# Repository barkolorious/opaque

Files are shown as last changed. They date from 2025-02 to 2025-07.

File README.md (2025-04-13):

# **OPAQUE**: **O**pen-source **P**ortable **A**ir **QU**ality **E**quipment

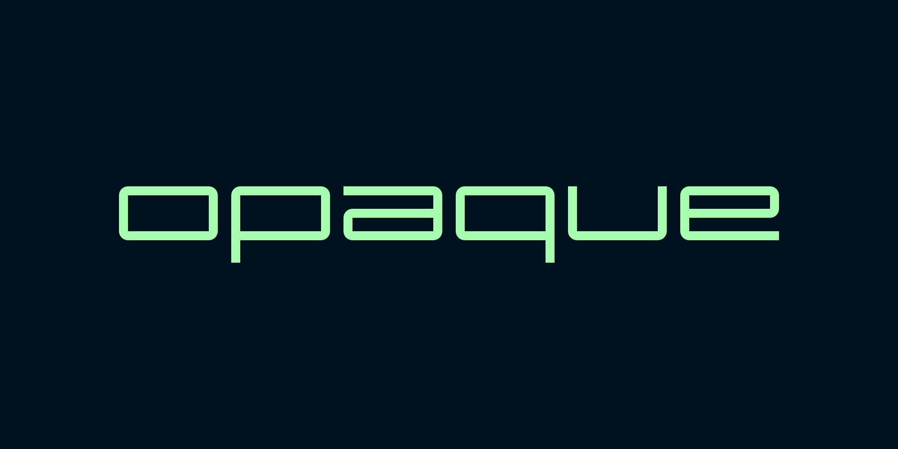
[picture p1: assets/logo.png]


---

A portable device that measures the temperature, humidity, AQI (Air Quality Index), tVOC (total Volatile Organic Components), eCO2, CO, NH3, NOx and O3 amount in the air.

It comes in 2 flavours: OPAQUE Lite and OPAQUE Connect. OPAQUE Lite stores the measurements on device, in contrast to OPAQUE Connect, which stores data both on device and on cloud. OPAQUE Connect can also pull data from cloud.

It's still work in progress.

2204-D Report: https://docs.google.com/document/d/112pA8oVNO5BkxKRDr9aJxBSNs7QlX5zvWhuIxiFPKnI/edit?usp=sharing

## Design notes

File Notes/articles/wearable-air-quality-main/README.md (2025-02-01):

# Wearable Air Quality Monitor
The device is based around the Arduino Nicla Sense ME  and incorporates aditional sensors to collect information on VOCs, CO2, Temperature, Humidity, and particulates. The objective is to provide a relatively low cost open design to monitor pollutants of concern.

----------------------
If installing fresh libraries, make sure to change the following:

In sps30.h file make sure to do the following
Comment out: 
#define INCLUDE_SOFTWARE_SERIAL 1

Change I2C length from 32 to 256>>
  #define I2C_LENGTH 256
  
Receieve buffer length change for non SMALLFOOTPRINT from 128 to 256:
#else
#define MAXRECVBUFLENGTH 256

Also install the ArduinoBLE library for the Arduino_BHY2.
----------------------



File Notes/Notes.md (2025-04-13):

- [x] terahertz diode co2
- [x] ege üni özlem hoca
- [x] cuma öğleden sonra 14:00

- [x] ege üni özkur hoca
- [x] ultraviyole sensör
- [ ] verilerin birbirlerini etkilemesi

- https://www.hammaddeler.com/urun/kaucuk-buyuk-tipa

- [x] basınç gerekli mi 
- [x] no2 so2 gerekli mi - özlem hocaya sor
- [x] 15k tl -> özlem hocaya sor
- [x] 3 tane
- [x] genel araştırma projesi

- [ ] sps30 karşılaştırma testi
- [ ] hastalar işe gitsin trafiğe çıksın
- [X] en şart ölçümleri soru ve sıklığı sor
- [X] butonu sor
- [x] 3 x 5 gün
- [x] ivme ölçer 
- [x] diğeri kadar büyük olabilir

- [ ] sunumları alabilir miyiz
- [ ] basınç gerekli mi
- [ ] no2 so2 gerekli mi
- [ ] genel araştırma projesi nasıl çalışıyor, gap olmadan bize yardım edebilir mi

**Hastalara verme sebebi**
- gerçekten işe yarıyor mu, 
- veri toplama ve analizi (bölgesel), 
- Doktora destek çünkü SD kart veri topluyor ve doktora verebilirsin.

**OPAQUE**: **O**pen-source **P**ortable **A**ir **QU**ality **E**quipment
![[assets/logo.png]]

## EgeSAM
- https://polenalerji.ege.edu.tr
- goksel.ozlem@gmail.com
- pelin.metiner@gmail.com
- [EgeSAM 101. Yıl Sempozyumu](EgeSAM%20101.%20Yıl%20Sempozyumu.md)

## Articles
- [BACA GAZI ÖRNEKLEMESİNDE BTEX VOC GRUPLARININ ÖLÇÜM BELİRSİZLİĞİNİN HESAPLANMASI](https://avesis.omu.edu.tr/yayin/6a808b43-7e9a-41d2-a6cd-b386e392ce22/baca-gazi-orneklemesinde-btex-voc-gruplarinin-olcum-belirsizliginin-hesaplanmasi)
- [What is BTEX?](https://www.aeroqual.com/blog/what-is-btex)
- [Akıllı Şehir Hava Takip Sistemi ve Astım Hastaları İçin PM2.5 Konsantrasyonu Ölçüm Aracının Geliştirilmesi](articles/akillihava.pdf)
- [Comprehensive analysis of resilience of human airway epithelial barrier against short-term PM2.5 inorganic dust exposure using in vitro microfluidic chip and ex vivo human airway models](allergy2024goksel.pdf)
- [HYPER-LOCAL AIR ZONE EVALUATOR (HAZE): AN OPEN SOURCE SYSTEM FOR PERSONAL ENVIRONMENTAL EXPOSURE MONITORING](v001t04a003-dmd2023-5665.pdf)

## Benzer Projeler
- https://atmotube.com/atmotube-pro
- Oğuz Hoca'nın Projesi
	- https://github.com/AMA-Labs/droneiotserver
	- https://asmedigitalcollection.asme.org/BIOMED/proceedings/DMD2023/86731/V001T04A003/1163853
- https://www.hepsiburada.com/sunshinee-13-u-1-arada-tuya-wifi-hava-kalitesi-monitoru-co2-tvoc-hcho-pm2-5-pm1-0-pm10-sicaklik-nem-saat-tarih-alarm-zamanlayici-siyah-yu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
- https://www.google.com.tr/shopping/product/1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,of:1,eto:141815484925603285_0,prmr:1,pid:141815484925603285,cs:1&sa=X&ved=0ahUKEwiIlb6ItvyKAxUZ6wIHHQQRC94QgjYI_wg 
- https://www.google.com.tr/url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
- https://www.reddit.com/r/esp32/s/lKiWNX6Ak0

## Probable Components
- ESC32 SIM800L
	- https://www.hiber.com.tr/esp32-sim800l-gsm-module-imei-kayitli-uretim-fazlasi
	- https://www.youtube.com/watch?v=aCeVsySh-v4
	- https://www.motorobit.com/esp32-sim800l-gsm-module-gelistirme-karti-ttgo-t
	- https://randomnerdtutorials.com/esp32-sim800l-publish-data-to-cloud/
	- https://www.hepsiburada.com/ttgo-t-call-v1-4-esp32-sim800l-gsm-modulu-gelistirme-karti-ve-sim-anten-lehimsiz-pm-HBC000071WQ8U
	- https://www.elektrodepo.com/urun/ttgo-t-call-v1-4-esp32-sim800l-gsm-modulu-gelistirme-karti-sim-anten-lehimsiz
	- https://www.amazon.com.tr/T-Call-SIM800L-Modülü-Geliştirme-Lehimsiz/dp/B0DJJYS7H8/ref=sr_1_1?adgrpid=149290891115&dib=eyJ2IjoiMSJ9.EgimDA37MKVbJFewe0D3VPdO1C6fNslO2Pl-HL35DVgIxA5WuMHFbvYWD4978R3_z2cK8L_joyDAhRv9Xe0morgsaPVF940nGoh1fdj12P2CRbK1QtMohecb0POAcMw8DVhDOnuiY08fk4ExVHoFzI31nRxyBsWJJ-KK28ia0VTu7qdZAMSPXiS5wjYPGHoBxLNg6GleS1d_2DnD4zWxIggH06StPBn1YcHMs6USU_KjMwu6Vwsy81Dq_cBEVPWbYKxBVEC2vj8UKeA4ZLVePiUncPJECCjdZJ-8quTdRKU.aERDkYUaHCwcZKKPt1ZaMCcbHvms9AoYU4QdMM2_wCA&dib_tag=se&hvadid=678425501699&hvdev=c&hvlocphy=1012783&hvnetw=g&hvqmt=e&hvrand=2204728206467899657&hvtargid=kwd-842690300862&hydadcr=5565_2410569&keywords=esp32+sim800l&qid=1729361943&sr=8-1
- PMS7003
	- [Datasheet](datasheets/PMS7003_PMsensor.pdf)
- SPS30
	- [Datasheet](datasheets/SPS30.pdf)
- SCD4x: CO2 - Sıcaklık - Nem
	- https://robiz.net/scd41
	- https://sensirion.com/media/documents/48C4B7FB/66E05452/CD_DS_SCD4x_Datasheet_D1.pdf
	- https://tr.aliexpress.com/i/1005003974569988.html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
- MQ-7: CO
- ENS160: CO2 - tVOC
	- [Datasheet](datasheets/ENS160.pdf)
	- [Library](https://github.com/sciosense/ENS160_driver)
- AHT20 + BMP280: Nem - Sıcaklık - Basınç
	- https://www.hiber.com.tr/aht20-bmp280-yuksek-hassasiyetli-atmosferik-basinc-sicaklik-nem
- NEO-8M: GPS
- SGP40: VOC - Toluen
	- https://www.amazon.com.tr/Bileşikler-Cihazları-Monitörleri-Oluşturmak-Destekler/dp/B09D43WDVK
	- https://sensirion.com/media/documents/296373BB/6203C5DF/Sensirion_Gas_Sensors_Datasheet_SGP40.pdf 
- DS1307: RTC
	- https://www.direnc.net/rtc-modul-ds1307
- MP801: C6H6 - C7H8 - CH2O - C2H5OH - smoke
	- https://www.winsen-sensor.com/product/mp801.html?searchid=4719
- MP503: C2H5OH - smoke - iso-butane - CH2O
	- https://www.winsen-sensor.com/product/mp503.html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
- ENS160 + AHT21: CO2 - tVOC - Sıcaklık - Nem
	- https://tr.aliexpress.com/item/1005004052950350.html?src=google
- Batarya
	- https://www.turktablet.net/urun/venatus-va33hd-batarya-pil-5000mah
	- https://www.turktablet.net
- Arduino Nicla Sense Me
	- https://market.samm.com/arduino-nicla-sense-me
- MQ-131: O3
- ZE25-O3: O3
	- https://www.roboshop.com.tr/ze25-o3-ozon-sensoru-o3-gaz-sensoru-modulu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
- MICS-6814: CO, NO2, NH3
	- https://www.robotistan.com/mics-6814-hava-kalitesi-co-no2-nh3-azot-karbon-gaz-sensoru-modulu
	- https://www.sgxsensortech.com/content/uploads/2015/02/1143_Datasheet-MiCS-6814-rev-8.pdf
- ADS1115:
	- ![[assets/Pasted image 20241123235145.png]]
	- https://how2electronics.com/how-to-use-ads1115-16-bit-adc-module-with-esp32/
	- https://arduino.stackexchange.com/questions/53899/ads1115-measuring-5v-voltages-and-powering-with-3-3v
- ESC32-DevKitC-V4
	- https://dl.espressif.com/dl/schematics/esp32_devkitc_v4-sch.pdf
https://randomnerdtutorials.com/esp32-web-bluetooth/
## Current Components

### Lite
- ESP32-DevKitC-V4
- RTC - DS3231
- OLED Screen - SSD1306
- Gyro - MPU6050
- µSD Card
- GPS - NEO-6M
- Temperature, Humidity Measurement - ENS210
- AQI, tVOC, eCO2 Measurement - ENS160
- CO, NH3, NOx Measurement - MiCS6814
- O3 Measurement - MQ-131
- PM1, PM2.5, PM10 - PMS7003

### Connect
- ESP32-DevKitC-V4
- RTC - DS3231
- Touch Screen - Nextion NX4827P043
- Gyro - MPU6050
- µSD Card
- Mobile Data - SIM800C
- GPS - NEO-6M
- Temperature, Humidity Measurement - ENS210
- AQI, tVOC, eCO2 Measurement - ENS160
- CO, NH3, NOx Measurement - MiCS6814
- O3 Measurement - MQ-131
- PM1, PM2.5, PM10 - PMS7003

---

![[assets/Pasted image 20241114225116.png]]
![[assets/Pasted image 20241116133241.png]]

- ESP32 + SSD1306: 
	- https://lastminuteengineers.com/oled-display-esp32-tutorial/
- ESP32 + SD Card ( + [Data logging](https://randomnerdtutorials.com/esp32-microsd-card-arduino/#webserversdcard)): 
	- https://www.electronicwings.com/esp32/microsd-card-interfacing-with-esp32
	- https://randomnerdtutorials.com/esp32-microsd-card-arduino/
- ESP32 + SSD1306 + DS3231:
	- https://microcontrollerslab.com/esp32-ds3231-real-time-clock-rtc-oled/
- ESP32 + MPU6050:
	- https://randomnerdtutorials.com/esp32-mpu-6050-accelerometer-gyroscope-arduino/
- ESP32 Analog Input:
	- https://randomnerdtutorials.com/esp32-adc-analog-read-arduino-ide/
- ESP32 + Firebase:
	- https://randomnerdtutorials.com/esp32-firebase-web-app/
- ESP32 + SIM800C:
	- https://community.thinger.io/t/esp32-sim800c/676/3
- ESP32 + SIM800L:
	- https://randomnerdtutorials.com/esp32-cloud-mqtt-broker-sim800l/
	- https://circuitdigest.com/microcontroller-projects/interfacing-sim800l-module-with-esp32
- ESP32 + NEO-6M:
	- https://randomnerdtutorials.com/esp32-neo-6m-gps-module-arduino/
- ESP32 I<sup>2</sup>C Pull-up: 
	- https://electronics.stackexchange.com/questions/602404/esp32-i2c-circuit
	> Most sensors we use in our projects are breakout boards that already have the resistors built-in. So, usually, when you’re dealing with this type of electronics components you don’t need to worry about this.
	> - https://randomnerdtutorials.com/esp32-i2c-communication-arduino-ide/
- PM7003:
	- https://registry.platformio.org/libraries/avaldebe/PMSerial
	- https://github.com/avaldebe/PMserial
	- https://github.com/Ptelka/PMS7003
- MICS6814
	- https://forum.arduino.cc/t/cjmcu-6814-readings-into-ppm/1257495/5
	- https://store.siqma.com/mics-6814-air-quality-sensor-module.html
		- https://www.youtube.com/watch?v=ByzoAjvoX58
			- https://github.com/noorkhokhar99/MICS6814/tree/master
	- https://github.com/Seeed-Studio/Mutichannel_Gas_Sensor
	- maybe you forgot pullup-resistors? Do you use the MiCS-6814 on the purple adapter board CJMCU6814? Then you may add an eg 47k ohm resistor from the analog Input (A1 in your sketch) to Vcc (5V or 3,3 V, depends on your arduino). Then you should get other measurment than the 0-values.  BTW: the sensor needs some time to heat up. And I'm not sure about it's stability over time. I've no experience with it yet.
	- https://kstobbe.dk/2019/02/16/esp32-pms5003-bme280-mics6814-sensor-build/
	- https://forum.arduino.cc/t/cjmcu-6814-adapter-board-with-mics-6814-co-nh3-no2-sensor/595612/14
	- https://forum.arduino.cc/t/mics-6814-cjmcu-6814-gas-sensor-reading-conversion/992844
	- https://forum.arduino.cc/t/mics-6814-integrated-on-a-board-with-esp-wroom-32d-v_rs-reads-2-98-v-of-3-3/699348
	- https://forum.arduino.cc/t/cjmcu-6814-readings-into-ppm/1348009
	- ![[assets/assets/Pasted image 20250128162927.png]]
- MQ-131
	- https://github.com/ostaquet/Arduino-MQ131-driver
	- https://www.graphreader.com/v2
	- https://www.winsen-sensor.com/d/files/manual/mq131-h.pdf

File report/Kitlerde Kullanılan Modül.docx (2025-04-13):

Kitlerde Kullanılan Modül | Kullanıcı Kiti | Hasta Kiti | Açıklama
Mikrodenetleyici Kartı | ESP32-DevKitC-V4 | ESP32-DevKitC-V4 | ESP32-WROOM-32U; 4MB’lık flash hafızaya, 40MHz’lik kristale, 2 çekirdeğe, Bluetooth ve Wi-Fi entegrasyonuna ve harici anten konnektörüne sahiptir. UART, SPI ve I²C haberleşme protokollerini destekleyen kart 3,3V’ta çalışmaktadır.
Ekran | NX4827P043-011R | SSD1306 | NX4827P043; 4,3 inç, dokunmatik (resistif) bir ekrandır. UART ile haberleşmekte ve 5V’ta çalışmaktadır.
Sıcaklık ve Nem Ölçümü | ENS210 | ENS210 | Sensör 3,3V’ta çalışmaktadır. Sıcaklık ölçüm hassasiyeti ±0.15°C, bağıl nem ölçüm hassasiyeti ise ±%2’dir. Sıcaklık ölçüm aralığı -40 ile 100°C arası iken bağıl nem ölçüm aralığı %0 ile %100’dür.
AQI, tUOB, CO2 Ölçümü | ENS160 | ENS160 | Sensör 3,3V’ta çalışmaktadır. tUOB ölçüm aralığı 0-65.000ppb arası iken CO2 ölçüm aralığı 400-65.000ppm’dir. AQI ölçüm aralığı 1-5’tir (UBA, 2007 standardına göre).
CO, NH3, NOx Ölçümü | MICS-6814 | MICS-6814 | Sensör 5V’ta çalışmaktadır. CO ölçüm aralığı 1-1.000ppm, NH3 ölçüm aralığı 1-500ppm ve NOx ölçüm aralığı 0,05-10ppm’dir.
O3 Ölçümü | MQ131 | MQ131 | Sensör 5V’ta çalışmaktadır. O3 ölçüm aralığı 10-1.000ppm’dir.
PM1, PM2.5, PM10 Ölçümü | PMS7003 | PMS7003 | Sensör 5V’ta çalışmaktadır. Ölçüm aralığı 0-1.000μg/m³tür ve %98 doğrulukla sonuç vermektedir.
Gerçek Zamanlı Saat | DS3231 for Pi | NX4827P043-011R modülünün kendi RTC modülü | DS3231 For Pi modülü, I²C ile haberleşmekte ve 3,3V’ta çalışmaktadır.
İvmeölçer | GY-521 | - | GY-521 modülü, MPU6050 entegresini kullanan bir ivmeölçerdir. Modül, I²C ile haberleşmekte ve 3,3V’ta çalışmaktadır.
Mikro SD Kart Adaptörü | Mikro SD Kart Adaptör Modülü | Mikro SD Kart Adaptör Modülü | Modül, SPI ile haberleşmekte ve 3,3V’ta çalışmaktadır.
GPS Modülü | NEO-6M | NEO-6M | Modülün konum hassasiyeti ±2,5m, hız hassasiyeti ±0,1m/s’dir. Modül, UART ile haberleşmekte ve 5V’ta çalışmaktadır.

Kitlerde Kullanılan Modül | Kullanıcı Kiti | Hasta Kiti | Açıklama
ESP32-DevKitC-V4 | X | X | Mikrodenetleyici Kartı 4MB’lık flash hafızaya, 40MHz’lik kristale, 2 çekirdeğe, Bluetooth ve Wi-Fi entegrasyonuna ve harici anten konnektörüne sahiptir. UART, SPI ve I²C haberleşme protokollerini destekleyen kart 3,3V’ta çalışmaktadır.
NX4827P043-011R | X | | Ekran NX4827P043; 4,3 inç, dokunmatik (resistif) bir ekrandır. UART ile haberleşmekte ve 5V’ta çalışmaktadır.
SSD1306 | | X | Ekran SSD1306; 128x64 piksel, siyah-beyaz bir OLED ekrandır. I²C ile haberleşmekte ve 3,3V’ta çalışmaktadır.
ENS210 | X | X | Sıcaklık ve Nem Ölçümü Sensör 3,3V’ta çalışmaktadır. Sıcaklık ölçüm hassasiyeti ±0.15°C, bağıl nem ölçüm hassasiyeti ise ±%2’dir. Sıcaklık ölçüm aralığı -40 ile 100°C arası iken bağıl nem ölçüm aralığı %0 ile %100’dür.
ENS160 | X | X | AQI, tUOB, CO2 Ölçümü Sensör 3,3V’ta çalışmaktadır. tUOB ölçüm aralığı 0-65.000ppb arası iken CO2 ölçüm aralığı 400-65.000ppm’dir. AQI ölçüm aralığı 1-5’tir (UBA, 2007 standardına göre).
MICS-6814 | X | X | CO, NH3, NOx Ölçümü Sensör 5V’ta çalışmaktadır. CO ölçüm aralığı 1-1.000ppm, NH3 ölçüm aralığı 1-500ppm ve NOx ölçüm aralığı 0,05-10ppm’dir.
MQ131 | X | X | O3 Ölçümü Sensör 5V’ta çalışmaktadır. O3 ölçüm aralığı 10-1.000ppm’dir.
PMS7003 | X | X | PM1, PM2.5, PM10 Ölçümü Sensör 5V’ta çalışmaktadır. Ölçüm aralığı 0-1.000μg/m³tür ve %98 doğrulukla sonuç vermektedir.
DS3231 for Pi | | X | Gerçek Zamanlı Saat DS3231 For Pi modülü, I²C ile haberleşmekte ve 3,3V’ta çalışmaktadır. Hassasiyeti ±1dakika/yıl’dır.
GY-521 | | X | İvmeölçer GY-521 modülü, MPU6050 entegresini kullanan bir ivmeölçerdir. Modül, I²C ile haberleşmekte ve 3,3V’ta çalışmaktadır.
Mikro SD Kart Adaptör Modülü | X | X | Mikro SD Kart Adaptörü Modül, SPI ile haberleşmekte ve 3,3V’ta çalışmaktadır.
NEO-6M | X | X | GPS Modülü Modülün konum hassasiyeti ±2,5m, hız hassasiyeti ±0,1m/s’dir. Modül, UART ile haberleşmekte ve 5V’ta çalışmaktadır.

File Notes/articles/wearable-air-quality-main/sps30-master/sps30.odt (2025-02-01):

SPS30 sensor

# 1. Background

This project is part of a number of projects to measure the air quality. I bought a new sensor : SPS30 from Sensirion. Having worked on another sensor from them (SCD30) before the quality is normally good. The aim is to compare the output with other sensors and provide the learning.

The board was relative new, but at the time of writing this version of the documentation a better datasheet is available from supplier. (July 2020)

While there is a driver available from Sensirion it is very modular, to a point where it feel to be over engineered and complex. Also it looked to be half-library as I did not find good user examples for Arduino / ESP32. Hence I wrote the driver from scratch and it supports UART communication (different serial ports) as well as I2C.

A number of examples have been added. Tailored examples for LORA/Feather and SODAQ AFF/SARA-R410M NB-IOT are also available on my github.

In March 2020 an updated datasheet was made available. It contained information about updated SPS30 function and new functions, of which some depend on firmware revisions. The library has been updated with new functions : sleep(), wakeup(), GetVersion() and GetStatusReg(). Also some existing functions have been updated.

In May 2020, based on continued new boards with different pin-outs, as well as boards with multiple I2C channels, the option has been added to select any serial or I2C channel and pass that initialized to the library. Example12 and 13 demonstrate those options.

The library has been validated on many boards now and in June 2020 I got hold of an Arduino Due. It does not seem to support SoftSerial, so for all the friends using a Due, I made changes that you can connected it to I2C, Serial1, Serial2 and Serial3, just like it is for a Mega2560.

Thank you Sensirion !! In June 2020 they have reached out as I have 2 SPS30 ‘only’ on firmware level 1.0 and offered me SPS30 with revision 2.2. I could now test the code and made a number of changes for the new functions : sleep(), wakeup() and GetStatusReg(). I have changed example11 to demonstrate reading the status register only and added example14 to demonstrate the usage of Sleep and wakeup().

August 2020. I obtained connectors for all 3 SPS30 and added Example20 which can run up to 5 SPS30 devices in parallel on a single Arduino Due, 4 devices on Mega2560 or ESP32. See chapter 9 for explanations.

October 2020 : added a Sparkfun LCD to display the results (with optional warning limit)

January 2021 : corrected pin - connection for Due

Paul van Haastrecht

paulvha@hotmail.com

# 2. Hardware connection

Depending on UART or I2C the connections are different. Has been tested by others on many other platforms including SAMx1D.

## 2.0 Select any communication

From the start I had decided to take an embedded communication channel setup. This made it much easier for the user to select and have the right setup for Serial or I2C. It was initially tested on an UNO, MEGA, ESP32, ESP8266 and works well.

Overtime code has been adjusted to support many more boards with different pin-outs based on user request and feedback. The Arduino Due has been added in 1.4.4.

Given the large number of new boards that continue to hit the market, with different pin-outs as well as boards with multiple I2C channels and based on feedback, I have decided to add the option for the user provide the communication channel also differently. This means the user will perform in the sketch the initialization of the channel (serial or I2C) and provide that to the SP30 library. Example12 (for serial communication) and Example13 (for I2C communication) has been added to demonstrate the usage.

The embedded approach as described below, and thus backward compatibility, continues to be available.

## 2.1 UART communication

### 2.1.1 ESP32

Using serial port1, setting the RX-pin(25) and TX-pin(26)

Different setup can be configured in the sketch.

SPS30 pin ESP32

1 VCC -------- VUSB

2 RX --------- TX pin 26

3 TX --------- RX pin 25

4 Select (NOT CONNECTED)

5 GND -------- GND

Also successfully tested on Serial2 (default pins TX:17, RX: 16)

NO level shifter is needed as the SPS30 is TTL 5V and LVTTL 3.3V compatible

### 2.1.2 ATMEGA2560 / Arduino Due

Used SerialPort2. No need to set/change RX or TX pin

SPS30 pin ATMEGA/ Due

1 VCC -------- 5V

2 RX --------- TX2 pin 16

3 TX --------- RX2 pin 17

4 Select (NOT CONNECTED)

5 GND -------- GND

Also successfully tested on SerialPort1 and Serialport3

### 2.1.3 Failed UNO R3

Failed as I had to use softserial as there is not a separate serial port. But as the SPS30

is only working on 115K the connection failed all the time with CRC errors. (see 2.2.3)

### 2.1.4 Failed ESP8266

As the power is only 3V3 (the SPS30 needs 5V) and one has to use softserial which failed with 115K speed

## 2.2 I2C communication

As documented in the datasheet, make sure to use external 10K pull-up resistor on both the SDA and SCL lines. Otherwise the communication with the sensor will fail random. Also read chapter 4 about the expected valid values in I2C.

Although the SPS30 (according to the datasheet) can handle 100K/s, based on feedback from a user he could only the SPS30 to work for longer time stable at 50K. Example13 and example16 allow you to set the speed to 50K. (added version 1.4.10)

### 2.2.1 ESP32

SPS30 pin ESP32

1 VCC -------- VUSB

2 SDA -------- SDA (pin 21)

3 SCL -------- SCL (pin 22)

4 Select ------ GND (select I2c)

5 GND ------- GND

The pull-up resistors should be to 3V3.

Just be aware the ESP32 also has WIRE1, without default pins. You can set pins however e.g.

Wire1.begin(23,18,100000); // SDA pin 23, SCL pin 18, 100kHz frequency // Wire1 on ESP32

You still need pull-up resistors to 3V3

### 2.2.2 ATMEGA2560 / Arduino Due

SPS30 pin ATMEGA

1 VCC -------- 5V

2 SDA -------- SDA

3 SCL --------- SCL

4 Select ------- GND (select I2c)

5 GND -------- GND

On a Due Wire already has pull-up resistors. You can also use Wire1 on a Due. Then connect to SDA1 and SCL1 next to AREF. Here you need to add external pull-up resistors as you have to do on an MEGA2560.

### 2.2.3 UNO R3

SPS30 pin UNO

1 VCC ------- 5V

2 SDA ------- A4

3 SCL -------- A5

4 Select ------ GND (select I2c)

5 GND ------- GND

When UNO-board is detected the UART code is excluded as that does not work on UNO and will save memory. Also some buffers reduced and the call to GetErrDescription() is removed to allow enough memory. Apart from that ALL examples work with UNO as well :-)

### 2.2.4 ESP8266

SPS30 pin External ESP8266

1 VCC -------- 5V

2 SDA ----------------------- SDA

3 SCL ------------------------ SCL

4 Select ---------------------- GND (select I2c)

5 GND ------- GND -------- GND

The pull-up resistors should be to 3V3 from the ESP8266.

### 2.2.5 SODAQ AFF / SARA NB-IOT

SPS30 pin SODAQ

1 VCC -------- 5V

2 SDA -------- SDA (next to ARF NOT A4 / SDA1)

3 SCL -------- SCL (next to SCL/ARF NOT A5 / SCL1)

4 Select ------- GND (select I2c)

5 GND -------- GND

When connecting as indicated above to SDA and SCL those pull-up resistors are already

on the SODAQ board. SDA1 and SCL1 do NOT have pull-up and require driver change.

# 3. Software

This software has been written from scratch. The driver has no dependencies on other libraries, some examples have, due to extra sensors / hardware. It has a number of user level calls to set and get data from the SPS30 and can be used independent of the communication channel setting. The I2C communication however could have some restrictions. See chapter 4.

## 3.1 Examples overview

At the top of each sketch there is detailed information about the hardware connections and dependencies on external libraries. For a SODAQ board, the standard console output Serial (e.g. Serial.print()), needs to be changed in each example to SerialUSB.

### 3.1.1 Basic reading

This sketch will detect an SPS30 and read and display all the data every 3 seconds

It will allow to configure for communication channel, serial-RX and TX pins as well as debug level.

### 3.1.2 Basic reading with fan-clean

This sketch will detect an SPS30, read the current auto clean interval, optionally set new auto clean interval or force a manual fan-clean. After that it wile read and display all the data every 3 seconds.

It will allow to configure for communication channel, serial-RX and TX pins, debug level and options to set the auto clean interval or force a manual fan-clean.

### 3.1.3 Basic reading specific data & order

This sketch will detect an SPS30 and allows to set and display specific data in a specific order every 3 seconds. It will allow to configure for communication channel, serial-RX and TX pins, debug level and define the wanted data in a wanted order.

### 3.1.4 Basic reading with DS18X20

This sketch will detect an SPS30 and DS18X20 temperature sensor and read and display all the data every 3 seconds. It will allow to configure for the SPS30 communication channel, serial-RX and TX pins as well as debug level. For the DS18x20 it will allow to configure the pin and whether to display in Celsius or Fahrenheit. This sketch the download library: https://github.com/PaulStoffregen/OneWire. Code for the DS18x20 is based on the DS18x20 example in the onewire library

### 3.1.5 Basic reading with BME280

This sketch will detect an SPS30 and DS18X20 temperature sensor and read and display all the data every 3 seconds. It will allow to configure for the SPS30 communication channel, serial-RX and TX pins as well as debug level. For the BME280 it will allow to configure the I2C address, whether to display in Celsius or Fahrenheit and whether to display altitude in meter or foot. This sketch the download library: https://github.com/sparkfun/SparkFun_BME280_Arduino_Library

### 3.1.6 SPS30 plotter

This sketch will detect an SPS30, reads and displays the data every seconds The output format is aimed for the plotter (Cntrl+shift+L). It will allow to configure for the SPS30 communication channel, serial-RX and TX pins as well as debug level. You can configure the data to plot (MassPMx, NumPMx or average size) as well as how of the first readings to skip to remove invalid start-up info.

### 3.1.7 SPS30 and SCD30

This sketch will detect an SPS30 and SCD30, reads and display data every 3 seconds. It will allow to configure for the SPS30 communication channel, serial-RX and TX pins as well as debug level. For the SCD30 it will allow to configure to display in Celsius or Fahrenheit. This sketch the depending on the SCD30 library: https://github.com/paulvha/scd30

NOTE: on an ESP32 together with and SCD30 the standard I2C/Wire library can not be used as that does not support clock stretching. The SoftWire library, part of SCD30 has been included to support that. See 3.3.5. Apart from that the I2C on an ESP32 initializes in a particular way and as part of that it will fail often if a device is constant sending data. Read the top of the sketch for more details.

### 3.1.8 SPS30 and SCD30 and BME280

This sketch is a combination of example 5 and 7 in one sketch.

### 3.1.9 SPS30 higher precision + typical value compare

Read the SPS30 information and display with high precision. Calculated average size and compare that against the reported typical value. Provide an actual and longer running error margin.

### 3.1.10 SPS30 and AirQualityindex (AQI)

This sketch will connect to an SPS30 for getting data, store data and display the available data. The sketch has been developed and tested only for an ESP32. The data during-hour and during-day is stored RAM and at end-of-day it will be combined with data from previous days that is stored in NVRAM. Based on the captured data and the region setting, it can calculate and display an air quality index that is applicable for that region. Requires : https://github.com/paulvha/airquality

### 3.1.11 basic reading + status register

In March 2020 an updated datasheet was made available in which new SPS30 functions were indicated. These functions depend mostly on newer level firmware of the SPS30. For the status register firmware level 2.2 in the SPS30 is necessary. This example was added to show how to use the new function GetStatusReg(). The fan needs to be turning couple seconds before detecting an issue.

### 3.1.12 basic reading + any Serial

Added the option for the user to select any serial communication channel. It must be initialized in the sketch ( e.g. Serial2.begin() and then passed on the library ( sps30.begin(&Serial2)). Example12 has been added to demonstrate the usage. This “any serial channel” approach can be applied to any of the other examples.

### 3.1.13 basic reading + any I2C

Added the option for the user to select any I2C communication channel. Many of the new boards have multiple I2C channels. It must be initialized in the sketch ( e.g. Wire1.begin() and then passed on the library ( sps30.begin(&Wire1)). Example13 has been added to demonstrate the usage. This “any I2C channel” approach can be applied to any of the other examples.

### 3.1.14 basic reading + sleep and wakeup

In March 2020 an updated datasheet was made available in which new SPS30 functions were indicated. These functions depend mostly on newer level firmware of the SPS30. For the sleep and wakeup firmware level 2.0 in the SPS30 is necessary. This example was added to show how to use the new functions : sleep(), wakeup().

### 3.1.15 basic reading + any Serial + LCD

### 3.1.16 basic reading + any I2C + LCD

As Example 12 and Example 13 but added an LCD for display to display PM1, PM2.5 and PM10.

The normal background color can be set to White, Green, Red, blue or OFF.

A trigger level for PM2 can be set :

A. SET the LCD background RED if above and return to normal when below.
B. OR only turn the LCD on RED if above the limit.

A button can be defined to turn the display on for 10 seconds. This button can be combined with with option A above.

The LCD used is from Sparkfun https://www.sparkfun.com/products/16397

Needs the driver to be installed as well, see sketch header for more information.

### 3.1.20 Multiple SPS30 on the same board

This has been added in August 2020 and for more information see chapter 9

## 3.2 Overview of user level calls

### 3.2.1 EnableDebugging(act, SelectDebugSerial)

Will enable or disabled driver debug messages. Valid options for ‘act’ as level of debug

0 : no debug message (default)

1 : sending and receiving data

2 : 1 + protocol messages

SelectDebugSerial is optional, by default it will use ‘Serial’ ( STANDARD). Starting revision 1.3.10 one could also select ‘SODAQ”, which will use ‘SerialUSB’ for debug output. See chapter 3.3.7.

### 3.2.2 SetSerialPin( rx, tx)

Sets the RX and TX pins to use for softserial or serialport1 on the ESP32. If these communication channels are used the pins must be set before calling begin. See NOTE 2 with chapter 3.2.3

### 3.2.3 begin(Comms_port)

This will initialize embedded the communication channel. Unlike in other sketches, you should NOT first perform a begin ( Serial1.begin()) in the sketch. That is all handled by the driver. The following options are supported :

I2C_COMMS I2C communication (Wire)

SOFTWARE_SERIAL Arduino variants (see NOTE)

SERIALPORT ONLY IF there is NO monitor attached

SERIALPORT1 Arduino MEGA2560 and Arduino Due

ESP32 Thing : MUST define pins as defaults are for flash memory

SERIALPORT2 Arduino MEGA2560, Due and ESP32 (default is omitted)

SERIALPORT3 Arduino MEGA2560 and Arduino Due only for now

NOTE 1 : Softserial has been left in as an option, but as the SPS30 is only working on 115K the connection will probably NOT work on any device. See chapter 3.3.4 to excluding Software Serial code. On a SAM21D and Due SoftSerial is disabled.

NOTE 2: SerialPort1 is only enabled in case of MEGA2560, Arduino Due or ESP32 (with defined RX/TX before)

On some boards/IDE (like Particle Photon) Serial1 is available as well. To force-enable from the user sketch : set TX and RX pins BOTH to 8, before calling begin().

Will return ‘true’ if successful, else ‘false’.

### 3.2.4 begin (&Serial)

The library will take any initialized serial communication channel. You MUST first perform a begin ( e.g. Serial1.begin()) in the sketch, before passing on.

### 3.2.5 begin (&Wire)

The library will take any initialized Wire communication channel. (e.g. Wire1) You MUST first perform a begin (e.g. Wire1.begin()) in the sketch, before passing on.

### 3.2.6 probe()

This will try to connect the SPS30 over the requested communication channel.

Will return ‘true’ if successful, else ‘false’.

### 3.2.7 reset()

This will sent a soft-reset to the SPS30.

Will return ‘true’ if successful, else ‘false’.

### 3.2.8 start()

This will sent a start-measurement command to the SPS30.

Will return ‘true’ if successful, else ‘false’.

### 3.2.9 stop()

This will sent a stop-measurement command to the SPS30.

Will return ‘true’ if successful, else ‘false’.

### 3.2.10 clean()

This will sent a manual clean fan command to the SPS30. The fan will spin faster for 10 seconds.

The SPS30 must be in measurement mode. Will return ‘true’ if successful, else ‘false’.

### 3.2.11 GetAutoCleanInt(uint32_t *val)

This will read the current Auto Fan clean interval from the SPS30 and return that in pointer to ‘val’.

Will return ‘SPS30_ERR_OK’ if successful read, else on the error messages documentation in Appendix A.

### 3.2.12 SetAutoCleanInt(uint32_t val)

This will SET the Auto Fan cleaning interval on the SPS30 to the value defined in ‘val’. Will return ‘SPS30_ERR_OK’ if successful read, else on the error messages documentation in Appendix A.

### 3.2.13 GetErrDescription(code, *buf, len)

This will provide a description of an error code as documented in Appendix A. ‘Code’ the error code, ‘buf’ is a buffer to store the message and ‘len’ is the length of the buffer. (not supported on Uno : see chapter 3.2)

### 3.2.14 GetSerialNumber(*buf, len)

This will try to read the serial number from the device and store that in buffer ‘buf’ with a maximum number of bytes ‘len’. The maximum can be 32 bytes. Will return ‘true’ if successful, else ‘false’.

### 3.2.15 GetArticleCode(*buf, len)

This will try to read the Articlecode from the device and store that in buffer ‘buf’ with a maximum number of bytes ‘len’. The maximum can be 32 bytes. Will return ‘true’ if successful, else ‘false’.

!! GetArticleCode has been depreciated and for backward compatibility it will also be empty!!!

### 3.2.16 GetProductName(*buf, len)

Tries to read the product name from the device and store that in buffer ‘buf’ with a maximum number of bytes ‘len’. The maximum can be 32 bytes. Will return ‘true’ if successful, else ‘false’.

The name will always be always “00080000” , recommended to use as product identifier.

### 3.2.17 I2C_expect()

Will return the number of valid float values to expect from reading in I2C. See chapter 4.

### 3.2.18 GetValues(struct sps_values *v)

This will try to read all the values from the SPS30 and store those in structure pointer v. Will return ‘SPS30_ERR_OK’ if successful read else on the error messages documentation in Appendix A.

The structure is defined in sps30.h, for details read the datasheet

typedef struct sps_values

{

float MassPM1; // Mass Concentration PM1.0 [μg/m3]

float MassPM2; // Mass Concentration PM2.5 [μg/m3]

float MassPM4; // Mass Concentration PM4.0 [μg/m3]

float MassPM10; // Mass Concentration PM10 [μg/m3]

float NumPM0; // Number Concentration PM0.5 [#/cm3]

float NumPM1; // Number Concentration PM1.0 [#/cm3]

float NumPM2; // Number Concentration PM2.5 [#/cm3]

float NumPM4; / / Number Concentration PM4.0 [#/cm3]

float NumPM10; // Number Concentration PM4.0 [#/cm3]

float PartSize; // Typical Particle Size [μm]

};

NOTE 1: As mentioned in chapter 4, when the communication channel is I2C, depending on the receive buffer size in wire.h, only the MassPMx may be available. The others will be zero.

NOTE 2: Although the SPS30 can provide the different values as unsigned 16 bits, this library is only reading and providing the float values. Why settle for less ?

### 3.2.19 GetSpecific value()

This will try to return a specific value as a float. In case of error a ‘-1’ value will be returned.

The following calls are valid :

GetMassPM1()

GetMassPM2()

GetMassPM4()

GetMassPM10()

GetNumPM0()

GetNumPM1()

GetNumPM2()

GetNumPM4()

GetNumPM10()

GetPartSize()

The driver will perform a GetValues() and report the specific requested value. If another value is requested this will be provided from cache. As such the different values are a snap-shot taken at the same time. If a value is requested that has been reported already all the values will be refreshed.

### 3.2.20 sleep()

This functions requires minimum firmware level 2.0. It will set the SPS30 to sleep, using even less power < 50uA according to datasheet. Measurements done indicate that the current is around 30uA

### 3.2.21 wakeup()

This functions requires minimum firmware level 2.0. It will wakeup the SPS30 after it was set to sleep. If the SPS30 was in measurement mode before turning to sleep, wakeup will restart measurement mode, else it will wakeup in idle mode. In Idle mode the SPS30 is using 320uA, in measurement mode around 52mA. a

### 3.2.22 GetVersion()

This function will read the firmware and hardware levels from the SPS30 and provide the library version level.

struct SPS30_version {

uint8_t major; SPS30 Firmware levels

uint8_t minor;

uint8_t HW_version; SPS30 hardware level (zero on I2C)

uint8_t SHDLC_major; SHDLC protocol (zero on I2C)

uint8_t SHDLC_minor;

uint8_t DRV_major; The library version level

uint8_t DRV_minor;

};

### 3.2.23 GetStatusReg()

This functions requires minimum firmware level 2.2. This function will read the device status register. The status return is an “orred” value as multiple errors might happen at the same time.

STATUS_OK = 0

STATUS_SPEED_ERROR = 1 (0b00000001)

STATUS_LASER_ERROR = 2 (0b00000010)

STATUS_FAN_ERROR = 4 (0b00000100)

The call will return SPS30_ERR_OK if NO status issues are found or SPS30_ERR_OUTOFRANGE in case status issues were detected. The status-issues are cleared after reading. For fan issues to be detected the fan must be up and running for a couple of seconds.

## 3.3 Driver configuration

In the SPS30.h configuration settings are available.

### 3.3.1 Automatic configuration

In case of an UNO or another board with small memory some changes are applied automatically.

The buffers are reduced, the error message lookup is disabled and the UART communication code is excluded.

### 3.3.2 Exclude I2C communication code

In case you do not plan to use the I2C code and want to remove that in order to reduce the memory size of the driver in sps30.h comment out the line : #define INCLUDE_I2C 1.

Compile will fail if UART communication is excluded at the same time.

### 3.3.3 Exclude UART communication code

In case you do not plan to use the I2C code and want to remove that in order to reduce the memory size of the driver in sps30.h comment out the line : #define INCLUDE_UART 1

Compile will fail if I2C communication is excluded at the same time.

### 3.3.4 Exclude Software Serial communication code

In case software serial is not available for your board / IDE (causing compile errors) OR you want to save memory in sps30.h comment out the line: #define INCLUDE_SOFTWARE_SERIAL 1.

Software Serial has been in as an option, but given the 115K speed, it is expected to fail.

As SAMD device has 6 SERCOM or for the Arduino Due and Apollo3, there is no SoftSerial available. This option is to exclude.

### 3.3.5 ESP32 / SCD30 / clock stretching library

In case a sketch is to interact with both SPS30 and SCD30 on a ESP32 platform running BOTH over I2C, you MUST use the SoftWire I2C that is part of SCD30. For that you need to un-comment in sps30.h the line: // #define SOFTI2C_ESP32 1

If you platform is ESP32 and you do NOT plan to run the SPS30 over I2C, you can also apply option 3.3.2.

### 3.3.6 RX_DELAY_MS

Due to some users reporting timing issues during reading with newer SPS30 a delay has been added between written the register and reading the content. This delay is defined in SPS30.h as 100mS.

### 3.3.7 SelectDebugSerial

Starting version 1.3.10 a different serial port can be selected for debug output. For backward compatibility ‘Serial’ is choosing as default (STANDARD) with the call EnableDebugging(). An option that can be chosen with SODAQ, which will use ‘SerialUSB’ for debug output. More can be defined in the top of SPS30.h

### 3.3.8 INCLUDE_FWCHECK

New firmware levels have been slipped streamed into the SPS30 The datasheet from March 2020 shows added / updated functions on new firmware level. E.g. sleep(), wakeup(), status register are new.

On serial connection the new functions are accepted and positive acknowledged on lower level firmware, but execution does not seem to happen or should be expected.

On I2C reading Status register gives an error on lower level firmware. Sleep and wakeup are accepted and positive acknowledged on lower level firmware, but execution does not seem to happen or should be expected.

Starting version 1.4 of this library a firmware level check has been implemented and in case a function is called that requires a higher level than on the current SPS30, it will return an error.

By setting INCLUDE_FWCHECK to 0, this check can be disabled

# 4. I2C communication

In datasheet (page 16) the disclaimer is made:

Some considerations should be made about the use of the I 2 C interface. I 2 C was originally designed to connect two chips on a PCB. When the sensor is connected to the main PCB via a cable, particular attention must be paid to electromagnetic interference and crosstalk. Use as short as possible (< 10 cm) and/or well shielded connection cables.

We recommend using the UART interface instead, whenever possible: it is more robust against electromagnetic interference, especially with long connection cables

While the above is true, the I2C implementation, which works good as long as you apply the 2 x 10K pull-up resistors as indicated in the datasheet (March 2020) on pag 16.

## 4.1 Number of valid values

Opposite to an earlier assumption that the SPS30 is only sending 32 bytes, it turned out that the I2C / Wire receive buffer on many boards is set a maximum value of 32. After that the boards will stop with receiving.

A size needed for each float value is 6 bytes (LSB + MSB + CRC ) ++ (LSB + MSB + CRC) To read all values an I2C receive buffer of at least 6 x 10 = 60 bytes is needed. As on many boards the default buffer size is set to 32 in Wire.h, it will only be providing 5 valid float values.

To cope with this we determine the I2C buffer-size in the sps30.h and calculate in the constructor for sps30 the expected valid bytes. If the I2C buffer size is less than 64 only the MASS values are provided.

One can check the impact by calling I2C_expect(), which will return the number of valid float values to expect from reading SPS30.

Of course you can increase the buffer (if memory size allows) for your board in Wire.h. This is NOT part of this library, but part of your IDE.

ATMEGA (UNO or 2560 or Due .. maybe others)

I had to increase BOTH otherwise the connection would fail:

Wire/src/wire.h #define BUFFER_LENGTH 64 // was 32

Wire/src/utility/twi.h #define TWI_BUFFER_LENGTH 64 // was 32

Note :

Got input from Bert Heusinkveld that on a windows system for PRO-Mini (UNO variant) he had to change these values on:

-c:\program files (x86)\arduino\hardware\avr\libraries\wire…

-c:\users\...\AppData\local\arduino15\packages\arduino\hardware\avr\1.6.23\libraries\wire....

esp8266

Wire/src/wire.h #define BUFFER_LENGTH 64 // was 32

esp32

The buffer is already 128

Wire/src/wire.h #define I2C_BUFFER_LENGTH 128

MKRZERO / SAMD / Apollo3

The SAMD library has a different definition as it has a ‘sercom’ setup for all communication.

In wire.h for the a SAMD the RX buffer is defined as : RingBufferN<256> rxBuffer;

The library will handle that and set to 256, BUT given the 6 communication options, the SoftSerial is NOT available and thus disabled.

# 5. Relationship PM10 and PM2.5

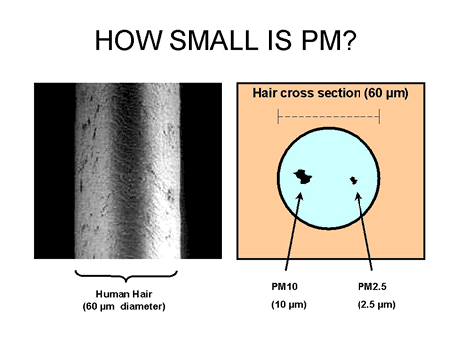
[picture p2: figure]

https://www.arb.ca.gov/research/aaqs/pm/pm.htm

An PM10 surface is 16 x PM2.5, while the PM10 volume is 64 x PM2.5. This means that the <PM 2.5 as much smaller, much lighter than the PM25 <> PM10 particles. And while the PM2.5 <> PM10 numbers are much less they have a size-able impact on the numbers.

The PM10 number INCLUDE the PM2.5 numbers. Different investigations have provided information around the relationship between PM2.5 and PM10 ug/m3.

The university of Montana 70% of the weight of PM10 constitutes of PM2.5.

HongKong:

Annual(μg/m³) | Daily(μg/m³)
PM2.5 = 0.71 x PM10 | PM2.5 = 0.75 x PM10

(https://www.epd.gov.hk/epd/english/environmentinhk/air/guide_ref/guide_aqa_model_g5.html)

Scotland:

The annual average ratio of daily mean PM2.5 concentration to daily mean PM10 concentration typically varied from 0.51 to 0.69 with a mean of 0.63

This was supported by the PCM modeled data, which indicated that the ratio of annual mean PM2.5 / PM10 ranged from 0.63 to 0.69

(http://www.scottishairquality.scot/assets/documents/technical%20reports/pm2.5-pm10ratio_29Mar2016-FINAL_Version_Approved.pdf)

# 6. Compare against Dylos

## 6.1 DYLOS-1700 definition

A DYLOS-1700 is providing information particle information per 0.01 cubic foot. It has 2 numbers:

A. Particle count > 0.5 μm

B. Particle count > 2.5 μm. This is a good representation of the PM10 value.(different tests)

From this you can calculate the Particle count between 0.5 μm and 2.5 μm: C = A - B

DYLOS numbers from cubic feet to cm3: DYLOS 0.01 ft³ / 283.1685 => cm³

## 6.2 SPS30 definition

The SPS30 numbers show in cm³ the particle count SMALLER than the size. Datasheet pag 2

PMx defines particles with a size smaller than “x” micrometers (e.g., PM2.5 = particles smaller than 2.5 μm).

The SPS30 starts measurement from 0.3um

## 6.3 Comparing

Let take an example of values captured (nearly) at the same moment :

SPS30 (concentration count)

PM0.5 PM1 PM2.5 PM4 PM10

123.09985 142.61128 143.41982 143.47649 143.48987

DYLOS-1700

A = 5523 B = 42 calculated C = 5481

Compare < 2.5μm concentration

Dylos > 5481 / 283.1685 = 19.536 particles / cm³ (> 0.5)

sps30 > 143.41982 –123.09985 = 20.31 particles /cm³ (> 0.5)

Compare >2.5μm concentration

Dylos > 42 / 283.1685 = 0.148 particles /cm³

SPS30 > 143.48987 – 143.41982 = 0.07 particles /cm³

Having run the above compare 10 times, the results < 2.5μm are within 92%, where the > 2.5μm varies between 1 to 40 times difference, but on a very small amount.

Interesting / surprising to see the high number between 0.3 μm to 0.5 μm. The Dylos starts at 0.5 where the SPS40 starts at 0.3 μm.

# 7. compare against SDS-011

## 7.1 SDS-011 definition

The SDS011 using principle of laser scattering,can get the particle concentration between 0.3 to 10μm in the air. It provides the mass of 2.5 μ/m³ and 10 μ/m³ . It is not defined whether this is inclusive or exclusive of the 2.5 μm particle, but it looks they follow official definition of the < 2.5 μm particle.

## 7.2 SP30 definition

The SPS30 numbers show in cm³ the particle count SMALLER than the size. Datasheet pag 2

PMx defines particles with a size smaller than “x” micrometers (e.g., PM2.5 = particles smaller than 2.5 μm).

The SPS30 starts at 0.3 μm as well and provides mass numbers as 1 μg/m³ , 2.5 μg/m³ , 4 μg/m³ and 10 μg/m³

## 7.3 Comparing

We had the 2 sensors run side by side for ~3500 samples, every 3 seconds.

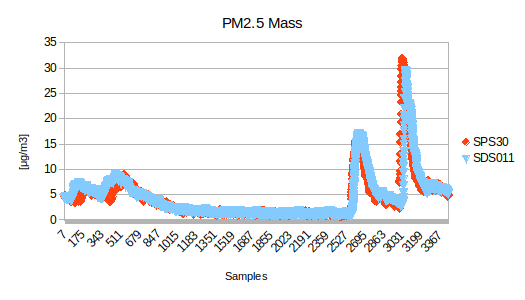
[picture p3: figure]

The 2.5 μ/m³ numbers are extremely close. They follow the same pattern, same reaction to change and the average over the 3500 samples is SPS30 : 4.27 μg/m³ where the SDS011 is showing : 4.45 μg/m³

Actually over a longer time it > 95% the same.

For the 10 μ/m³ the numbers are different

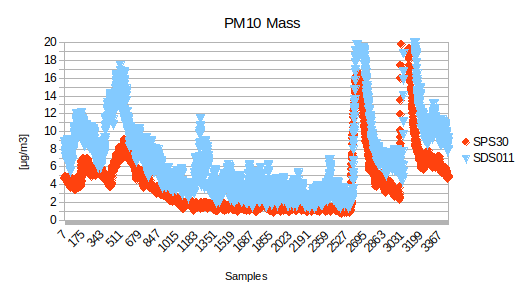
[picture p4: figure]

While they follow the same pattern and reaction, the values of SPS30 are nearly 50% of the SPS011. Over the 3500 samples on average the SPS30 is 4.35 μg/m³ where the SDS011 is 7.52 μg/m³.

We reference to chapter 5 :

Checking the relationship of SDS011 results shows over 3500 samples a factor between PM10 and PM2.5 of 0.567, often 0.6 / 0.7 drawn down especially when the μg/m3 reading is low.

Checking the relationship of SPS30 results shows over 3500 samples a factor between PM10 and PM 2.5 of 0.967, often 0.99 or 100% with lowest around 0.92.

Next to that when using example 9, compare Typical Particle Size (TPS) against average (AVG), it seems that the particles numbers above 2.5 μm to 10 μm are below of what to expect.

Using Example 9 and looking at the reported 10um mass, they are sometimes LESS than the 4um (nearly or the same as 2.5um). Also sometimes the 4 μm mass is less than 2.5 μm mass. I have 2 SPS30 sensor and BOTH have similar behavior. I have triple checked the real HEX values received from the SPS30. Below example with UART communication. :

sending: 0x7E 0x00 0x03 0x00 0xFC 0x7E

Received: 0x7E 0x00 0x03 0x00 0x28 0x41 0xB5 0x07 0x06 0x41 0xBF 0x36 0x47 0x41 0xBF 0x36 0x65 0x41 0xBF 0x36 0x47 0x43 0x18 0x06 0xDA 0x43 0x30 0xFB 0xD9 0x43 0x31 0xA0 0x35 0x43 0x31 0xA3 0x50 0x43 0x31 0xA4 0xB7 0x3F 0x09 0xD2 0x78 0xA9 0x7E length: 46

0x7E header

0x00 address

0x03 command

0x00 state

0x28 length

0x41 0xB5 0x07 0x06 1 ug/m3

0x41 0xBF 0x36 0x47 2.5 ug/m3

0x41 0xBF 0x36 0x65 4 ug/m3

0x41 0xBF 0x36 0x47 10 ug/m3 (PM10 mass values is the same as PM.25 and lower than PM4 ?)

0x43 0x18 0x06 0xDA 0.5 #/m3

0x43 0x30 0xFB 0xD9 1 #/m3

0x43 0x31 0xA0 0x35 2.5 #/m3

0x43 0x31 0xA3 0x50 4 #/m3

0x43 0x31 0xA4 0xB7 10 #/m3 (but at the same time the PM10 particle count is higher ???)

0x3F 0x09 0xD2 0x78 Typical particle

0xA9 CRC

0x7E trailer

# 8 Conclusions

## 8.1 Personal conclusion (feb 2019)

I believe the mass and volume numbers up to 2.5um are well representing the environment. But I wonder whether the sensor is able to detect / report above 2,5 μm particle size the average weight and/or the number of particles in the right way.

## 8.2 Additional / external PMx remarks

Since the release of the SPS30 a number of people and instances have tested this device and the remarks about PM10 measurement have been the same : is this correct ?

Many of the people who have reached out to me came to similar conclusions and wondered.

A research paper concluded that the Sensirion Sps30 is not able to detect particles above ~2 um.

https://www.researchgate.net/publication/337852062_Laboratory_evaluation_of_particle_size-selectivity_of_optical_low-cost_particulate_matter_sensors

Document available in extra folder : Laboratory_evaluation_of_particle_size-selectivity

Sensirion has been providing additional information. A specialist article has been created (copied in the extras directory).

“The quality of the mass estimation will thus vary highly depending on the manufacturer algorithm used to convert the measured optical signal into PM mass concentration…….

Sensirion’s proprietary algorithms use an advanced approach that allows a proper estimation of the mass concentration, regardless of the particle type measured. In addition, such an approach enables a correct estimation of the size bins. Also, an additional bin output is provided in contrast to most state-of-the-art consumer PM sensors on the market – PM4.0.”

The datasheet March 2020, footnote 4 on page 2:

“PM4 and PM10 output values are calculated based on distribution profile of all measured particles”

All in all it supports the earlier personal conclusions, but this additional information provide more background information.

# 9. Multiple SPS30 at the same time

Let’s say you want to measure the air quality on different places at the same time with different SPS30 :

- Inside the building different rooms
- Inside the building different rooms and outside the building
- Inside the building different floors

BUT you do not want to have multiple CPU boards !!

Because you may want to combine or compare the data on a single place or act on the measurements from a single place with an action or alarm condition….

GOOD NEWS… YOU CAN connect up to at least 5 (FIVE !) SPS30 to a single board.

Starting with example20 you can connect up to 5 (FIVE !) different SPS30 to a single board. They can be connected to either Serial1, Serial2, Serial3 or also at the same time to Wire, Wire1 or any WireX you might have. Example20 allows up to 3 Serial and up to 2 Wire connections at the same time !! With a little change, you can add Serial connection or add Wire connections (if your board support that) .

The example20 has been tested on a Arduino MEGA2560, Arduino Due and ESP32. The MEGA2560 and ESP32 can handle 4 while Arduino Due can have 5 running at the same time.

As I ‘only’ have 3 SPS30 I was able to test with 3 in parallel. In this chapter I will share the setup and the experience I had.

## 9.1 Hardware device setup

This is already described in chapter 2 with BOTH Serial and I2C on the different boards.

Just be reminded that for each Wire-channel you have to use different pull-up resistors !!

### 9.1.1 I2C cable length

The maximum bus length of an I2C link is about 1 meter at 100 Kbaud, or 10 meters at 10 Kbaud. All driven by the quality of the cable and it’s capacitive value. There are external I2C cable extenders with can extend to 300 meters. That said, I have not tested the library using an extender and that might need to include some delays. The default speed for I2C channel is 100Khz, BUT you could lower that by added a call SPS_COMMSx.setClock(clockFrequency), e.g. 35000 as 35Khz, for SPS30_COMMS4 or SPS30_COMMS5.

### 9.1.2 Serial / RS232 cable length

The RS-232 standard specifies this as 15 meters. On lower baud rates the lines can be longer (e.g. 100 meter at 9600 baud), but the SPS30 only works on 115K. There are external RS232 extenders which can extend to as far as 1200 meters on 115K. That said, I have not tested the library using an extender and that might need to include some delays. In the file sps30.h from the library a variable RX_DELAY_MS is defined as 100mS. This delay between requesting data and reading data could be extended if needed. The received data is normally buffered before reading by the application.

## 9.2 Software

### 9.2.1 General settings

The software is modular and has a couple of settings.

Chapter 3.3 defines the settings in sps30.h

Chapter 4 is especially important for the number of values in case of I2C

### 9.2.2 Sketch

The Example20 sketch has a number of settings

Communication channel

Around line 116 you define the number of SPS30 as well as the communication channels

Comment out ( like SPS_COMMS3) the channels that you do NOT use.

- Serial channel for SPS30_COMMS1 – SPS30_COMMS3 and / or
- I2C channel for SPS30_COMMS4 – SPS30_COMMS5

#define SPS30_COMMS1 Serial1 // serial only

#define SPS30_COMMS2 Serial2 // serial only

//#define SPS30_COMMS3 Serial3 // serial only

#define SPS30_COMMS4 Wire // I2C only

#define SPS30_COMMS5 Wire1 // I2C only

Debug

Debug messages can be set for each communication channel individually, DEBUG1 – DEBUG5.

0 : no DEBUG messages

1 : request sending and receiving

2 : request sending and receiving + show protocol errors

#define DEBUG1 0

#define DEBUG2 0

#define DEBUG3 0

#define DEBUG4 0

#define DEBUG5 0

ESP32 Serial1

The ESP32 is flexible is assigning the serial communication to different pins. The default Serial1 pins are used by memory, but you can still use the Serial1 by assigning different pins. See line 147 in the sketch for Serial1 instructions : SPS30_COMMS1.begin(115200, SERIAL_8N1, 25, 26); // ESP32 in case of Serial1

ESP32 Wire1

The ESP32 has 2 Wire channels. The Wire1 does not have default pins and these need to be defined as you setup the connection with: SPS30_COMMS5.begin(23,18,100000); // SDA pin 23, SCL pin 18, 100kHz frequency // Wire1 on ESP32

## 9.3 Multiple connection test

As stated before I have 3 SPS30, but WHY ?

The first one I bought had no connector included so I could not use it. What a deception ! The second I bought from Sparkfun, these guys get it… you want to test and thus a connector is included. Both running Firmware level 1.0 The third one I got from Sensirion, as an appreciation from the work done on the library (Thank You) BUT no connector (and not expected)

At later stage I have ordered the right connectors from AliExpress and can now connect all 3 devices.

### 9.3.1 Arduino DUE

The DUE is able to support up to 5 devices: 3 x serial + 2 x Wire. In my test I connected as follows:

SPS30-1 : connection Serial1

SPS30 pin DUE

1 VCC -------- 5V

2 RX --------- TX1 pin 18

3 TX --------- RX1 pin 19

4 Select (NOT CONNECTED)

5 GND -------- GND

#define SPS30_COMMS1 Serial1 // serial only

SPS30-2 : connection Serial2

SPS30 pin DUE

1 VCC -------- 5V

2 RX --------- TX2 pin 16

3 TX --------- RX2 pin 17

4 Select (NOT CONNECTED)

5 GND -------- GND

#define SPS30_COMMS2 Serial2 // serial only

SPS30-5: connection Wire1 (with external pull-up)

SPS30 pin DUE

1 VCC -------- 5V

2 SDA -------- SDA1 NEXT TO AREF

3 SCL --------- SCL1 NEXT TO SDA1

4 Select ------- GND (select I2c)

5 GND -------- GND

#define SPS30_COMMS5 Wire1 // I2C only

Last by not least, comment out the lines:

//#define SPS30_COMMS3 Serial3 // serial only

//#define SPS30_COMMS4 Wire // I2C only

The Arduino DUE standard Wire (NOT Wire1) keeps confusing me. Sometimes the standard Wire (SDA0 / SCL0) works and sometimes it does not. This has to do with the on-board resistors, which should NOT be there – only the client / slave devices. In the tests I have done it did work, but with other slave devices with pull-up resistors it did not work. While NOT applying external pull-up resistors Wire worked. It worked always with Wire1, if you not forget to add external pull-up resistors of 5K6 or 10K.

### 9.3.2 Arduino Mega2560

The Mega2560 is able to support up to 4 devices: 3 x serial + 1 Wire. There is no Wire1 on the Arduino Mega2560, the SDA and SCL pins are just 2 times available. I connected as follows, just for a test:

SPS30-1 : connection Serial1

SPS30 pin ATMEGA

1 VCC -------- 5V

2 RX --------- TX1 pin 18

3 TX --------- RX1 pin 19

4 Select (NOT CONNECTED)

5 GND -------- GND

#define SPS30_COMMS1 Serial1 // serial only

SPS30-2 : connection Serial2

SPS30 pin ATMEGA

1 VCC -------- 5V

2 RX --------- TX2 pin 16

3 TX --------- RX2 pin 17

4 Select (NOT CONNECTED)

5 GND -------- GND

#define SPS30_COMMS2 Serial2 // serial only

SPS30-3 : connection Serial3

SPS30 pin ATMEGA

1 VCC -------- 5V

2 RX --------- TX3 pin 14

3 TX --------- RX3 pin 15

4 Select (NOT CONNECTED)

5 GND -------- GND

#define SPS30_COMMS3 Serial3 // serial only

SPS30-4: connection Wire

SPS30 pin ATMEGA

1 VCC -------- 5V

2 SDA -------- SDA

3 SCL --------- SCL

4 Select ------- GND (select I2c)

5 GND -------- GND

#define SPS30_COMMS4 Wire // I2C only

Last by not least, comment out the line:

//#define SPS30_COMMS5 Wire1 // I2C only

### 9.3.3 ESP32

Is able to support up to 4 devices: 2 x serial + 2 x Wire. In my test I connected as follows:

SPS30-1 : connection Serial1

SPS30 pin ESP32

1 VCC -------- 5V

2 RX --------- TX2 pin 26

3 TX --------- RX2 pin 25

4 Select (NOT CONNECTED)

5 GND -------- GND

#define SPS30_COMMS1 Serial1 // serial only

I have then changed around line 330 from

SPS30_COMMS1.begin(115200);

to

SPS30_COMMS1.begin(115200, SERIAL_8N1, 25, 26); // ESP32 in case of Serial1

SPS30-4: connection Wire

SPS30 pin ESP32

1 VCC -------- 5V

2 SDA -------- SDA pin 21

3 SCL --------- SCL pin 22

4 Select ------- GND (select I2c)

5 GND -------- GND

#define SPS30_COMMS4 Wire // I2C only

Pin 21 and 22 are the default pins for Wire, but could be changed like done for Wire.

Also added 2 pull-up resistors of 5k6

SPS30-5: connection Wire1

SPS30 pin ESP32

1 VCC -------- 5V

2 SDA -------- SDA pin 23

3 SCL --------- SCL pin 18

4 Select ------- GND (select I2c)

5 GND -------- GND

#define SPS30_COMMS5 Wire1 // I2C only

I have then changed around line 449 from

SPS30_COMMS5.begin();

to

SPS30_COMMS5.begin(23,18,100000); // SDA pin 23, SCL pin 18, 100kHz frequency // Wire1 on ESP32

Also added 2 pull-up resistors of 5k6

In case you want to use Serial2 as well :

SPS30-2 : connection Serial2

SPS30 pin ESP32

1 VCC -------- 5V

2 RX --------- TX2 pin 17

3 TX --------- RX2 pin 16

4 Select (NOT CONNECTED)

5 GND -------- GND

#define SPS30_COMMS2 Serial2 // serial only

Pin 16 and 17 are the default pins for Serial2, but could be changed like done for Serial1

## 9.4 Sample output ESP32

SPS30-Example20: Basic reading with multiple SPS30. press <enter> to start

Trying to connect.

Detected SPS30 - 1

Serial number : 361D4FD3AA941A76 Product name : 00080000

Firmware level: 1.0 Hardware level: 6 SHDLC protocol: 2.0 Library level : 1.4

Measurement started SPS30 - 1

Detected SPS30 - 4

Serial number : 1FDFF1525C39D2B1 Product name : 00080000

Firmware level: 1.0 Hardware level: 0

Measurement started SPS30 - 4

Detected SPS30 - 5

Serial number : 46B997159016E02F Product name : 00080000

Firmware level: 2.2 Hardware level: 0

Measurement started SPS30 - 5

Hit <enter> to continue reading.

SPS30 -------------Mass ----------- ------------- Number -------------- -Average- --Serialnumber--

Dev Concentration [μg/m3] Concentration [#/cm3] [μm]

P1.0 P2.5 P4.0 P10 P0.5 P1.0 P2.5 P4.0 P10 PartSize

1 3.11 3.61 3.92 4.03 20.60 24.48 24.96 25.01 25.02 0.62 361D4FD3AA941A76

4 5.63 10.23 13.61 14.46 27.20 39.61 44.40 45.00 45.10 0.85 1FDFF1525C39D2B1

5 6.14 6.49 6.49 6.49 41.85 48.78 48.99 49.01 49.02 0.52 46B997159016E02F

1 3.77 4.36 4.73 4.86 25.00 29.69 30.26 30.32 30.34 0.63 361D4FD3AA941A76

4 5.61 9.95 13.13 13.93 27.64 39.65 44.18 44.74 44.84 0.87 1FDFF1525C39D2B1

5 6.02 6.36 6.36 6.36 41.04 47.83 48.04 48.06 48.07 0.49 46B997159016E02F

1 4.85 5.53 5.94 6.08 32.41 38.32 38.96 39.03 39.05 0.60 361D4FD3AA941A76

4 4.94 7.66 9.60 10.08 27.11 36.10 38.89 39.23 39.29 0.74 1FDFF1525C39D2B1

5 6.04 6.39 6.39 6.39 41.17 47.99 48.19 48.21 48.23 0.53 46B997159016E02F

1 5.52 6.21 6.61 6.75 37.11 43.71 44.36 44.43 44.44 0.60 361D4FD3AA941A76

4 5.36 7.96 9.78 10.24 30.32 39.56 42.20 42.53 42.58 0.74 1FDFF1525C39D2B1

5 6.19 6.54 6.54 6.54 42.18 49.15 49.36 49.39 49.40 0.51 46B997159016E02F

1 5.86 6.57 6.97 7.12 39.45 46.42 47.09 47.16 47.17 0.62 361D4FD3AA941A76

4 6.07 8.77 10.64 11.11 34.92 45.03 47.76 48.09 48.15 0.73 1FDFF1525C39D2B1

5 6.48 6.85 6.85 6.85 44.16 51.46 51.68 51.71 51.72 0.49 46B997159016E02F

# Appendix A : Error messages

Defined in sps30.h

Hex

00 SPS30_ERR_OK “All good"

01 SPS30_ERR_DATALENGTH "Wrong data length for this command (too much or little

data)"

02 SPS30_ERR_UNKNOWNCMD "Unknown command"

03 SPS30_ERR_ACCESSRIGHT "No access right for command"

04 SPS30_ERR_PARAMETER "Illegal command parameter or parameter out of allowed

range"

28 SPS30_ERR_OUTOFRANGE "Internal function argument out of range"

43 SPS30_ERR_CMDSTATE "Command not allowed in current state"

50 SPS30_ERR_TIMEOUT "No response received within timeout period"

51 SPS30_ERR_PROTOCOL "Protocol error"

88 SPS30_ERR_FIRMWARE “Not supported on this SPS30 firmware level”

# Appendix B : some example output

## Example 1 : Basic reading

SPS30-Example1: Basic reading. press <enter> to start

Trying to connect

Detected SPS30.

Serial number : 361D4FD3AA941A76

Product name : 00080000

Firmware level: 1.0

Library level: 1.4

Measurement started

Hit <enter> to continue reading

Hit <enter> to continue reading (Note 1)

-------------Mass ----------- ------------- Number -------------- -Average-

Concentration [μg/m3] Concentration [#/cm3] [μm]

P1.0 P2.5 P4.0 P10 P0.5 P1.0 P2.5 P4.0 P10 PartSize

13.31 16.19 18.14 18.85 107.15 103.87 106.74 107.09 0.00 0.60

12.88 14.86 16.06 16.51 103.75 101.60 103.49 103.71 0.00 0.61

12.77 14.80 16.06 16.52 102.83 100.61 102.56 102.79 0.00 0.65

12.50 14.04 14.90 15.22 100.64 99.02 100.45 100.61 0.00 0.61

12.14 13.42 14.08 14.32 97.77 96.48 97.63 97.75 0.00 0.62

11.97 13.09 13.63 13.82 96.39 95.29 96.27 96.37 0.00 0.61

11.80 12.87 13.37 13.55 95.02 93.98 94.92 95.01 0.00 0.61

11.61 12.60 13.04 13.20 93.50 92.55 93.40 93.48 0.00 0.60

11.50 12.44 12.84 12.99 92.59 91.70 92.50 92.58 0.00 0.59

11.37 12.29 12.67 12.81 91.58 90.72 91.49 91.56 0.00 0.59

11.43 12.32 12.68 12.82 92.02 91.19 91.94 92.01 0.00 0.57

11.43 12.31 12.65 12.77 92.07 91.27 92.00 92.06 0.00 0.58

11.43 12.28 12.60 12.72 92.09 91.32 92.01 92.07 0.00 0.57

11.34 12.15 12.45 12.56 91.33 90.60 91.26 91.31 0.00 0.57

11.25 12.03 12.31 12.41 90.58 89.88 90.51 90.57 0.00 0.56

11.10 11.85 12.10 12.19 89.42 88.77 89.37 89.41 0.00 0.56

11.13 11.85 12.08 12.17 89.61 88.98 89.55 89.60 0.00 0.56

11.00 11.69 11.90 11.98 88.56 87.97 88.51 88.55 0.00 0.57

10.76 11.42 11.61 11.68 86.67 86.12 86.63 86.66 0.00 0.56

10.71 11.35 11.53 11.60 86.23 85.70 86.19 86.23 0.00 0.56

10.67 11.30 11.47 11.53 85.94 85.42 85.90 85.93 0.00 0.56

10.56 11.17 11.33 11.39 85.02 84.52 84.98 85.01 0.00 0.57

10.51 11.11 11.26 11.32 84.62 84.13 84.58 84.61 0.00 0.56

10.55 11.16 11.31 11.36 85.00 84.52 84.97 85.00 0.00 0.57

10.73 11.36 11.51 11.57 86.46 85.96 86.42 86.45 0.00 0.57

11.08 11.72 11.88 11.94 89.23 88.72 89.19 89.22 0.00 0.56

11.17 11.81 11.96 12.02 89.95 89.44 89.91 89.94 0.00 0.56

11.01 11.63 11.78 11.83 88.66 88.16 88.62 88.65 0.00 0.57

10.89 11.50 11.65 11.70 87.70 87.22 87.67 87.70 0.00 0.58

## Example 5 : Basic reading with BME280

SPS30-Example5: Basic reading + BME280. press <enter> to start

Trying to connect

Detected SPS30

Serial number : 361D4FD3AA941A76

Product name : 00080000

Firmware level: 1.0

Library level: 1.4

Detected BME280

Measurement started

Hit <enter> to continue reading (Note 1)

================================= SPS30 ================================= ========== BME280 ============

--------------------Mass ------------------- ----------------------- Number ------------------------- -Average- Pressure Humidity Altitude Temperature

Concentration [μg/m3] Concentration [#/cm3] [μm] [hPa] [%] Meter [*C]

P1.0 P2.5 P4.0 P10 P0.5 P1.0 P2.5 P4.0 P10 PrtSize

15.26 15.87 15.87 15.87 122.90 122.53 122.90 122.90 0.00 0.36 967 37.7 390.6 22.98

15.69 16.33 16.33 16.33 126.39 126.01 126.38 126.39 0.00 0.42 1005 37.8 68.8 22.93

15.90 16.54 16.54 16.54 128.06 127.67 128.05 128.06 0.00 0.44 1005 37.8 68.9 22.90

16.63 17.30 17.30 17.30 133.93 133.52 133.92 133.93 0.00 0.45 1005 37.7 67.8 22.84

17.01 17.70 17.70 17.70 137.02 136.60 137.01 137.01 0.00 0.46 1005 37.6 69.1 22.80

17.20 17.89 17.89 17.89 138.51 138.08 138.50 138.50 0.00 0.46 1005 37.5 68.5 22.77

17.20 17.89 17.89 17.89 138.51 138.09 138.50 138.51 0.00 0.47 1005 37.6 69.4 22.73

17.24 17.94 17.94 17.94 138.89 138.47 138.88 138.89 0.00 0.47 1005 37.5 68.9 22.67

17.40 18.10 18.10 18.10 140.13 139.70 140.12 140.13 0.00 0.47 1005 37.5 68.4 22.63

17.42 18.12 18.12 18.12 140.30 139.88 140.30 140.30 0.00 0.48 1005 37.3 68.6 22.58

## Example 7 : Basic reading with SCD30

SPS30-Example7: Basic reading + SCD30. press <enter> to start

Trying to connect

Serial number : 361D4FD3AA941A76

Product name : 00080000

Firmware level: 1.0

Library level: 1.4

SCD30 found

Serial number: 390943

Measurement started

Hit <enter> to continue reading (Note 1)

=================================== SPS30 ================================= ========= SCD30 ==========

---------------------Mass ----===---------- ----------------------- Number -------------------------- -Average- CO2 Humidity Temperature

Concentration [μg/m3] Concentration [#/cm3] [μm] [ppm] [%] [*C]

P1.0 P2.5 P4.0 P10 P0.5 P1.0 P2.5 P4.0 P10 PrtSize

16.29 17.21 17.21 17.21 127.91 127.44 127.90 127.91 0.00 0.55 741 35.6 22.15

17.86 21.66 23.86 24.41 140.80 136.81 140.33 140.73 0.00 0.57 741 35.4 22.25

17.08 19.54 20.73 21.02 134.41 132.05 134.16 134.37 0.00 0.56 742 35.3 22.33

15.96 16.86 16.86 16.86 125.31 124.85 125.30 125.31 0.00 0.54 742 35.0 22.44

15.65 16.53 16.53 16.53 122.85 122.40 122.84 122.85 0.00 0.55 741 35.0 22.49

15.64 17.00 17.37 17.46 122.90 121.85 122.81 122.88 0.00 0.56 739 34.8 22.62

15.61 16.49 16.49 16.49 122.56 122.11 122.55 122.56 0.00 0.56 739 34.7 22.67

15.97 16.89 16.90 16.91 125.39 124.90 125.37 125.38 0.00 0.56 744 34.5 22.77

16.12 17.05 17.08 17.08 126.54 126.03 126.52 126.53 0.00 0.56 745 34.4 22.80

## Example 8 : Basic reading + SCD30 + BME280

Trying to connect

Detected SPS30

Serial number : 361D4FD3AA941A76

Product name : 00080000

Firmware level: 1.0

Library level: 1.4

Detected SCD30

Serial number : 390943

Detected BME280

Measurement started

Hit <enter> to continue reading (Note 1)

============== SPS30 ============================== ========= SCD30 ====== ======== BME280 ===============

-------------Mass ----------- ------------- Number -------------- -Average- CO2 Humidity Temperature Pressure Humidity Altitude Temperature

Concentration [μg/m3] Concentration [#/cm3] [μm] [ppm] [%] [*C] [hPa] [%] Meter [*C]

P1.0 P2.5 P4.0 P10 P0.5 P1.0 P2.5 P4.0 P10 PrtSize

3.04 3.63 3.97 4.05 23.96 23.34 23.88 23.94 0.00 0.60 804 32.7 24.89 1022 44.7 -74.1 21.29

2.91 3.62 4.05 4.15 22.98 22.22 22.89 22.97 0.00 0.59 802 32.6 24.89 1022 44.6 -74.0 21.29

2.57 3.05 3.31 3.38 20.25 19.76 20.19 20.24 0.00 0.60 800 32.6 24.90 1022 44.8 -74.0 21.30

2.35 2.82 3.09 3.16 18.54 18.05 18.48 18.53 0.00 0.60 799 32.5 24.87 1022 45.3 -74.8 21.30

2.18 2.50 2.66 2.69 17.13 16.81 17.09 17.12 0.00 0.56 796 32.6 24.89 1022 45.0 -74.6 21.30

2.15 2.57 2.81 2.87 16.95 16.52 16.90 16.95 0.00 0.57 797 32.7 24.87 1022 44.6 -74.4 21.30

2.01 2.34 2.52 2.56 15.82 15.48 15.78 15.81 0.00 0.57 798 32.7 24.90 1022 45.4 -74.1 21.30

1.95 2.32 2.53 2.58 15.39 15.01 15.35 15.39 0.00 0.60 798 32.8 24.89 1022 45.1 -74.5 21.31

1.84 2.21 2.42 2.47 14.48 14.10 14.44 14.48 0.00 0.58 800 32.7 24.87 1022 45.0 -74.2 21.30

1.76 2.07 2.24 2.28 13.90 13.58 13.86 13.89 0.00 0.58 801 32.7 24.89 1022 45.0 -75.1 21.30

## Example 9 : Basic reading + typical + average

Hit <enter> to continue reading

-----------------------Mass --------------------- -------------------------- Number --------------------------- -----Partsize -------- ----- Error Margin -----

Concentration [μg/m3] Concentration [#/cm3] [μm] %

PM1.0 PM2.5 PM4.0 PM10 PM0.5 PM1.0 PM2.5 PM4.0 PM10 Typical Average Actual last 10 samples

2.44646 3.72065 4.61890 4.84432 13.60713 17.95112 19.25093 19.41132 19.43798 0.68469 0.78369 -14.46 -14.46

2.98158 3.99828 4.66924 4.83762 17.91819 22.43591 23.43956 23.55998 23.58018 0.66387 0.70377 -6.01 -10.30

3.25240 4.01541 4.47382 4.58886 20.40710 24.83409 25.55428 25.63722 25.65131 0.62317 0.65614 -5.29 -8.72

3.52776 4.20484 4.58310 4.67803 22.50948 27.09331 27.71152 27.78041 27.79225 0.58633 0.63696 -8.64 -8.70

3.68784 4.34082 4.69292 4.78127 23.66743 28.37988 28.96679 29.03113 29.04225 0.56174 0.63027 -12.20 -9.33

3.82785 4.54891 4.94859 5.04888 24.45823 29.41227 30.06833 30.14116 30.15369 0.59167 0.63536 -7.39 -9.02

3.90359 4.63237 5.03476 5.13575 24.95849 30.00106 30.66302 30.73637 30.74899 0.59676 0.63461 -6.34 -8.65

3.94991 4.69951 5.11631 5.22090 25.22431 30.34434 31.02732 31.10326 31.11631 0.60294 0.63599 -5.48 -8.26

3.94206 4.61696 4.97509 5.06495 25.35640 30.36026 30.96264 31.02818 31.03953 0.59949 0.62764 -4.70 -7.87

3.85170 4.45136 4.75403 4.82998 24.92396 29.72656 30.25042 30.30610 30.31580 0.60135 0.62064 -3.21 -7.41

3.79606 4.38160 4.67558 4.74935 24.57754 29.30286 29.81325 29.86734 29.87679 0.60597 0.61999 -2.31 -6.52

3.74854 4.33460 4.63112 4.70552 24.25030 28.92784 29.44034 29.49486 29.50437 0.60642 0.62094 -2.39 -6.11

3.73187 4.26205 4.51513 4.57863 24.27512 28.85470 29.30724 29.35406 29.36230 0.60149 0.61450 -2.16 -5.79

3.81722 4.27159 4.46097 4.50849 25.04913 29.60613 29.97384 30.00942 30.01584 0.58703 0.60410 -2.91 -5.07

3.86197 4.29266 4.46133 4.50366 25.41500 29.98342 30.32403 30.35597 30.36181 0.58214 0.60071 -3.19 -4.09

3.84442 4.25367 4.40619 4.44445 25.34799 29.86744 30.18542 30.21449 30.21984 0.58537 0.59842 -2.23 -3.63

3.93010 4.40392 4.60364 4.65376 25.77495 30.47541 30.86048 30.89796 30.90471 0.60476 0.60479 -0.01 -3.18

3.79063 4.30330 4.53995 4.59933 24.72161 29.33589 29.76757 29.81152 29.81931 0.61342 0.61143 0.32 -1.61

3.70268 4.20668 4.44037 4.49902 24.14001 28.65187 29.07703 29.12041 29.12809 0.61379 0.61182 0.32 -1.41

Note 1:

The PM10 showing 0 in some examples was an error that has been fixed in the code in a later version

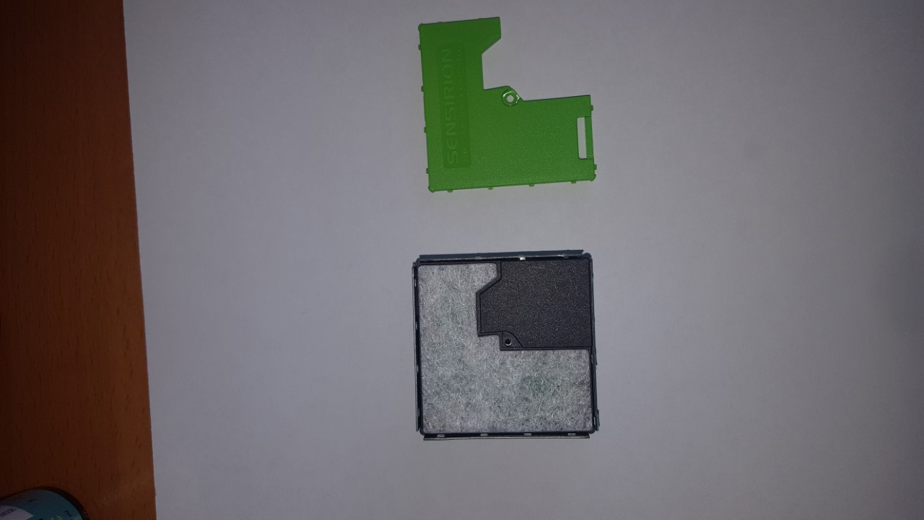
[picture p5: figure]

# Appendix C: inside SPS30

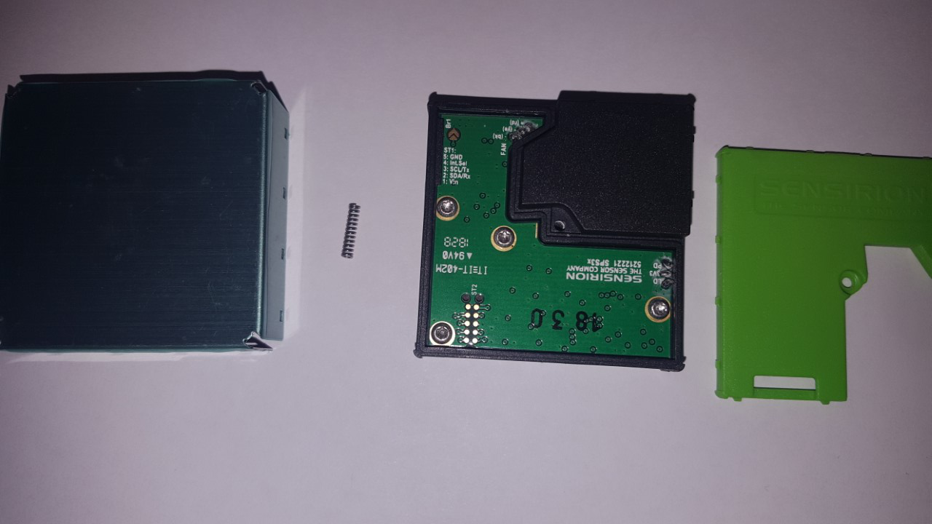
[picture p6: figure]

Removing the top cover screw

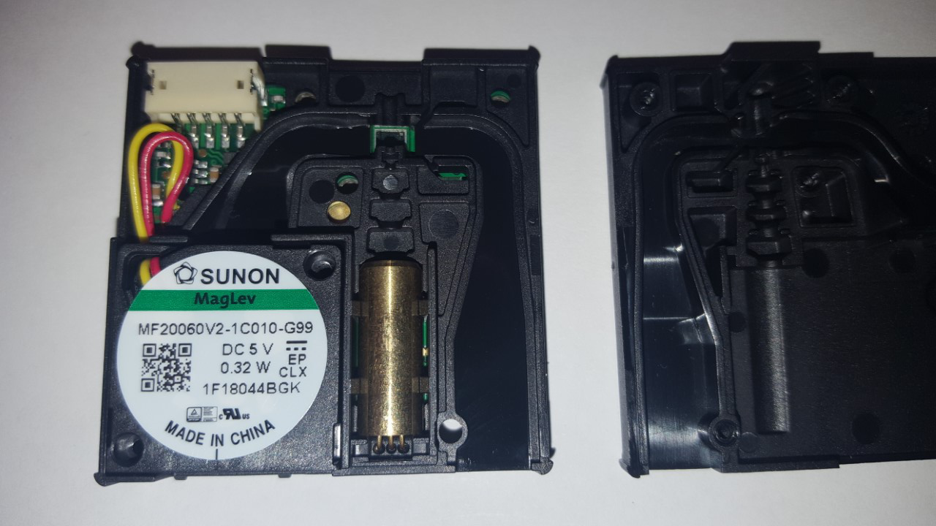
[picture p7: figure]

Carefully remove from the housing. Watch the spring at the back. Removing the 4 screws allows the top panel to be removed

Air goes in on the right hand side, through a measurement chamber and is coming out through the fan. At the bottom, the golden piece, is the led.

SPS30 page 40 of 40 Paulvha / version 1.4.11 / January 2022

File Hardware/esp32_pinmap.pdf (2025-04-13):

X | 3V3 | GND | X
X | EN | GPIO23 | VSPI_MOSI
X | VP | GPIO22 | I2C_SCL
X | VN | GPIO1 | U0_TX
Kayıt Düğmesi X Yedek Düğme X | GPIO34 | GPIO3 | U0_RX I2C_SDA
| GPIO35 | GPIO21
U3 SIM800_RX X | GPIO32 | GND | X
U3 SIM800_TX X U4 Nextion_RX X U4 Nextion_TX X Pil Şarj oluyor X | GPIO33 | GPIO19 | VSPI_MISO VSPI_SCK VSPI_SS U2_TX
| GPIO25 | GPIO18
| GPIO26 | GPIO5
| GPIO27 | GPIO17
X | GPIO14 | GPIO16 | U2_RX
X | GPIO12 | GPIO4 | U1_RX
X | GND | GPIO0 | X
X | GPIO13 | GPIO2 | U1_TX
| GPIO9 | GPIO15 | X NEXTION EXT INT
| GPIO10 | GPIO8
| GPIO11 | GPIO7
X | 5V | GPIO6

Pil Seviye (Analog)

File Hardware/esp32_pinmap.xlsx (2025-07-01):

 |  |  |  |  | NAME | TYPE | FUNCTION | TO
X | 3V3 |  | GND | GND | 3V3 | Power | Power supply
X | EN |  | GPIO23 | VSPI_MOSI | 5V | Power
BAT_CHR | GPIO36 |  | GPIO22 | I2C_SCL | GND | Power | Ground
EMPTY | GPIO39 |  | GPIO1 | U0_TX | GND | Power | Ground
BAT_LVL | GPIO34 |  | GPIO3 | U0_RX | GND | Power | Ground
INTERRUPT | GPIO35 |  | GPIO21 | I2C_SDA | EN | Input | Chip-enable
BTN_REC | GPIO32 |  | GND | GND | VP | Input
BTN_BCK | GPIO33 |  | GPIO19 | VSPI_MISO | VN | Input
(SS)U3_RX | GPIO25 |  | GPIO18 | VSPI_CLK | GPIO0 | Input/Output
(SS)U3_TX | GPIO26 |  | GPIO5 | VSPI_SS | GPIO1 | Input/Output | U0_TX | PC_RX
EMPTY | GPIO27 |  | GPIO17 | U1_TX | GPIO2 | Input/Output | U1_TX | NEO-6M_RX
HSPI_CLK | GPIO14 |  | GPIO16 | U1_RX | GPIO3 | Input/Output | U0_RX | PC_TX
HSPI_MISO | GPIO12 |  | GPIO4 | U2_RX | GPIO4 | Input/Output | U1_RX | NEO-6M_TX
GND | GND |  | GPIO0 | EMPTY | GPIO5 | Input/Output | VSPI_SS | SD Card_CS
HSPI_MOSI | GPIO13 |  | GPIO2 | U2_TX | GPIO6 | Input/Output | DO NOT USE | SHARED WITH FLASH DO NOT USE
DO NOT USE | GPIO9 |  | GPIO15 | HSPI_SS | GPIO7 | Input/Output | DO NOT USE | SHARED WITH FLASH DO NOT USE
DO NOT USE | GPIO10 |  | GPIO8 | DO NOT USE | GPIO8 | Input/Output | DO NOT USE | SHARED WITH FLASH DO NOT USE
DO NOT USE | GPIO11 |  | GPIO7 | DO NOT USE | GPIO9 | Input/Output | DO NOT USE | SHARED WITH FLASH DO NOT USE
X | 5V |  | GPIO6 | DO NOT USE | GPIO10 | Input/Output | DO NOT USE | SHARED WITH FLASH DO NOT USE
 |  | USB |  |  | GPIO11 | Input/Output | DO NOT USE | SHARED WITH FLASH DO NOT USE
 |  |  |  |  | GPIO12 | Input/Output | HSPI_MISO
 |  |  |  |  | GPIO13 | Input/Output | HSPI_MOSI
 |  |  |  |  | GPIO14 | Input/Output | HSPI_SCK
 |  |  |  |  | GPIO15 | Input/Output | HSPI_SS
 |  |  |  |  | GPIO16 | Input/Output | U2_RX | PM7003_TX
 |  |  |  |  | GPIO17 | Input/Output | U2_TX | PM7003_RX
 |  |  |  |  | GPIO18 | Input/Output | VSPI_SCK | SD Card_SCK
 |  |  |  |  | GPIO19 | Input/Output | VSPI_MISO | SD Card_MISO
 |  |  |  |  | GPIO21 | Input/Output | I2C_SDA | SSD1306_SDA, DS3231_SDA, ENS160_SDA, ENS210_SDA, MPU6050_SDA
 |  |  |  |  | GPIO22 | Input/Output | I2C_SCL | SSD1306_SCL, DS3231_SCL, ENS160_SCL, ENS210_SCL, MPU6050_SCL
 |  |  |  |  | GPIO23 | Input/Output | VSPI_MOSI | SD Card_MOSI
 |  |  |  |  | GPIO25 | Input/Output | GPIO
 |  |  |  |  | GPIO26 | Input/Output | GPIO
 |  |  |  |  | GPIO27 | Input/Output | GPIO
 |  |  |  |  | GPIO32 | Input/Output | GPIO
 |  |  |  |  | GPIO33 | Input/Output | GPIO
 |  |  |  |  | GPIO34 | Input
 |  |  |  |  | GPIO35 | Input

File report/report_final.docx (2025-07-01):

Proje Ana Alanı : Hava ve İklim

Proje Tematik Alanı : Hava Kalitesi

Proje Adı (Başlığı) : Açık-kaynaklı Taşınabilir Hava Kalitesi Ölçüm Kitleri

(opaque)

Özet

Yüksek tansiyon ve tütün kullanımından sonra, bulaşıcı olmayan hastalıklardan kaynaklı ölümlerin üçüncü önde gelen nedeni olan hava kirliliği, çağımızın en büyük çevresel sağlık riski olup her yıl 8,1 milyondan fazla insanın hayatını kaybetmesine neden olmaktadır. Uzun süreler hava kirliliğine maruz kalan kişilerin solunum sistemi hastalıklarına, kardiyovasküler hastalıklara, kanser ve diyabet gibi kronik hastalıklara yakalanma risklerinin arttığı kanıtlanmıştır. Ayrıca pandemi sürecinde yapılan bilimsel çalışmalarda hava kirliliğinin COVID-19 virüsüne yakalanma riskini yükselttiği gösterilmiştir. Hava kirliliğinden korunmak için alınabilecek önlemlerle ilgili araştırmalarda kişisel düzeyde alınabilecek tedbirlerin kirli ortamlardan uzaklaşmakla ve/veya maske takmakla sınırlı olduğu belirtilmiştir.

Proje kapsamında iki adet taşınabilir ölçüm cihazı (Kişisel Kit ve Medikal Kit) ve bir adet priz modülü (PrMd) yapılmıştır. Ölçüm cihazları mikro parçacıkları (PM1, PM2.5, PM10), toplam Uçucu Organik Bileşikleri (tUOB), AQI değerini, CO2, CO, NH3, NOx konsantrasyonlarını, sıcaklık ve nemi ölçmektedir. Kişisel Kit kişisel kullanımda özelleşip ölçümleri bir veritabanına kaydederken Medikal Kit ise medikal kullanımda özelleşip doktorların tanı ve tedavi süreçlerini hızlandırmayı amaçlamaktadır. PrMd ise Kişisel Kit ile etkileşimde olup ölçümlerin kullanıcının belirlediği alarm değerleri geçmesi halinde devreye girmektedir.

Kitler yapıldıktan sonra iki tür hassasiyet kontrol testi yapılmıştır. Birincisi kalibreli cihazlarla dış ortamda karşılaştırmalı testler, ikincisi referans değerlere karşı laboratuvar ortamında yapılan testlerdir. Testlerin sonuçlarının istatiksel değerlendirilmesinde bağımsız iki örneklem T-testi, mertebe karşılaştırması için Pearson Korelasyon analizi yapılmıştır. Yapılan analizlerde cihazların ölçümleri arasında istatiksel olarak anlamlı bir fark görülmemiştir.

Anahtar kelimeler: Hava Kirliliği, Taşınabilir Ölçüm Cihazı

1 Amaç

Dünya nüfusunun % 92’sinin etkilendiği ve her yıl 8 milyondan fazla insanın erken ölüm nedeni olan hava kirliliği (Çağlayan vd., Mart 2022) için kişisel olarak alınabilecek tedbirler ortamdan uzaklaşmak ve/veya maske takmakla sınırlıdır. Kirlilik kaynağının belirlenip kontrol altına alınması ve sağlık risklerinin tespit edilip kişisel tedbir alınabilmesi için bulunulan ortamın hava kirlilik değerlerinin bilinmesi gerekir. İnsanların yanlarında taşıyabilecekleri, uygun maliyetli ve yeterli hassasiyette ve pek çok ölçümü bir arada yapabilen ölçüm cihazına ihtiyaç vardır. Buna ek olarak kirlilikten etkilenen kişilerin maruziyet sureleri ve neye maruz kaldığının da bilmesi tedavi sürecinde doktorların daha doğru karar vermesini sağlayacaktır.

Bu çerçevede, projede iki tip taşınabilir ölçüm cihazı yapılması hedeflenmiştir.

1. Kişisel Kit: Hava kirliliğinden etkilenen kişilerin kullanabileceği taşınabilir ve kabul edilebilir hassasiyetler içinde kritik hava kirlilik parametreleri olan mikro parçacıkları (PM1, PM2.5, PM10), toplam Uçucu Organik Bileşikleri (tUOB), AQI değerini, CO2, CO, NH3, NOx konsantrasyonlarını ve sıcaklık, nem gibi ilişkili olduğu değerleri ölçebilen açık kaynaklı bir ölçüm cihazıdır. Kullanıcı, dokunmatik ekranda tüm ölçüm değerlerini görebilmektedir.
2. Medikal Kit: Tıbbî alanda kullanılması hedeflenmiştir Kişisel Kit ile aynı ölçümleri yapmaktadır. Hastaların yanlarında taşımaları için doktorlar tarafından verilecektir. Doktorların, hastaların yaşam ortamları hakkında bilgi edinmesini sağlayarak tanı/tedavi sürecini hızlandırmayı amaçlayan bir ölçüm cihazıdır.

Medikal Kit ile Kişisel Kit arasındaki farklar “Madde 3 Yöntem” başlığı altında verilmiştir. Bunun dışında kitlerin ölçümlerine göre çalışacak bir priz modülü (PrMd) yapılmıştır.

Ayrıca bu cihazların ölçümlerinin zaman ve konum bilgileriyle kaydedilip bir veri tabanı oluşturulması ve böylece hem hava kirliliğinin takibi hem de araştırma ve geliştirme çalışmalarında kullanılabilmesi hedeflenmiştir.

2 Giriş

“Hava kirliliği, çağımızın en büyük çevresel sağlık riski olup, her yıl 8,1 milyondan fazla insanın hayatını kaybetmesine neden olan sessiz bir katildir.” (United Nations Enviroment Programme [UNEP], t.y.). Hava kirliliği; iç veya dış havanın, doğal özelliklerini değiştiren bir dizi gaz ve katı ile kirlenmesidir. Başlıca sağlığa zararlı kirleticiler arasında partikül madde (PM2.5 ve PM10), karbonmonoksit (CO), ozon (O3), kükürtdioksit (SO2) ve azot oksitler (NOx) bulunur. İnce partikül madde (PM2.5), hava kirliliği etkilerinin sağlık tahminlerini yapmakta kullanılan temel göstergedir (World Health Organization [WHO], 2019).

Hava kirleticilerinin etkileri, maruz kalınan kirleticinin türü ve süresine göre değişmektedir. Yapılan çalışmalar, hava kirliliğine maruz kalmanın vücuttaki her organı etkilediğini ortaya koymuştur (Görsel 1). Dünya Sağlık Örgütü, hava kirliliği ile Tip 2 diyabet, obezite, sistemik inflamasyon, Alzheimer hastalığı ve bunama arasındaki bağlantılara dair kanıtlar sunmaktadır. Bağışıklık sistemini de hava kirliliğinden olumsuz yönde etkilenmektedir. Her yıl milyonlarca insanın erken ölümüne yol açan hava kirliliği, dünya nüfusunun %92’sini etkilemektedir. Kirlilik kaynaklı hastalık yükü ve maliyeti çok yüksektir (Çağlayan vd., Mart 2022).

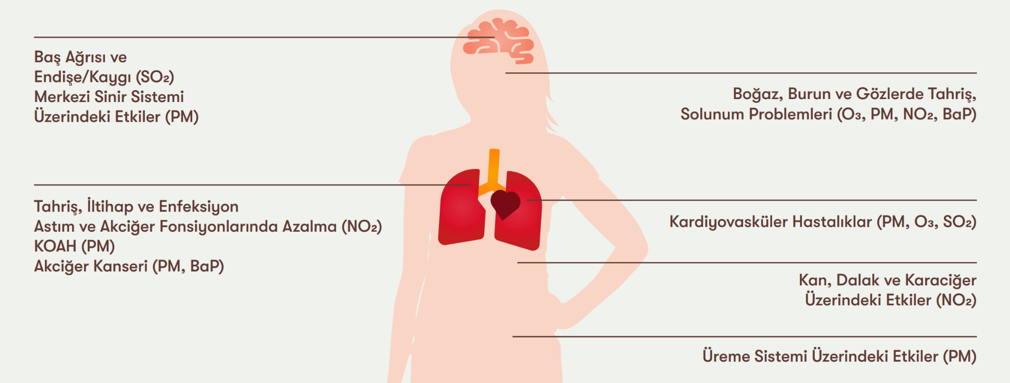
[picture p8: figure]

Görsel 1: Hava kirliliğine maruz kalmanın organlara etkileri (Çağlayan vd., Mart 2022)

Bir kısır döngü olarak hava kirlilik sebepleri aynı zamanda iklim değişikliğinin de sebepleridir. İklim değişikliğiyle beraber yükselen ortalama sıcaklıklar, yer seviyesinde ozon gibi diğer hava kirletici emisyonlarının oluşmasını tetiklemektedir (Clean Air Fund, t.y.). Çalışmalar ayrıca, ortam sıcaklığındaki yükselişin bakteri ve mantar seviyelerinin artmasına neden olduğunu ortaya koymuştur (Aghlara, 2017). Bunun yanı sıra, bakteri ve mantar yoğunluğunun PM2.5 ve PM10 seviyeleri ile istatistiksel olarak anlamlı bir bağlantıya sahip olduğu saptanmıştır. Dahası iklim değişikliğinin etkisi ile birlikte sıcak dalgaları gibi aşırı hava olayları kalıcı hale gelmekte ve bu da hava kirliliğinin zirve yaptığı sürenin artmasına sebep olmaktadır.

Hava kirliliğine karşı özellikle beş yaş altı çocuklar ve yaşlılar savunmasızdır. Astım ve diğer solunum yolu hastalıkları, kardiyovasküler hastalıklar gibi önceden var olan hastalıkları olan kişiler sağlık etkileri açısından daha büyük risk altındadır. Araştırmalar partikül maruziyetinin etkilerinin hamilelikte düşük ve erken doğum gibi olumsuzlukları artırdığını göstermiştir. En son 2020 yılı ile başlayan COVID-19 pandemisi sürecinde yapılan bilimsel çalışmalar, hava kirliliğinin COVID-19 virüsüne yakalanma riskini artırdığını ortaya koymuştur (Temiz Hava Hakkı Platformu, Eylül 2021).

Hava Kalitesi İndeksi (AQI), havada bulunan kirleticilerin insan sağlığı üzerindeki etkilerini değerlendirmek amacıyla geliştirilmiş bir ölçüttür. Hava kalitesini gösteren bu indeks, belirli bir bölgede hava kirletici maddelerin konsantrasyonunu belirli bir zaman diliminde ölçerek bir skala üzerinde değerlendirir (Idrees vd., 2018). Türkiye’de 5 temel kirletici için hava kalitesi indeksi hesaplanmaktadır. Bunlar; partikül maddeler (PM10), karbonmonoksit (CO), kükürt dioksit (SO2), azot dioksit (NO2) ve ozondur (O3) (Ege Temiz Hava Merkezi Müdürlüğü, t.y.).

Mikro parçacıklar (PM2.5, PM10), tanım olarak atmosferde asılı bulunan katı partiküllerin ve sıvı damlacıkların bir karışımı olup, asitler (sülfat, nitrat gibi), organik kimyasallar, metaller, toprak veya toz partikülleri, bakteri, küf, mantar, deniz suyunun buharlaşması ile ortaya çıkan tuzlar ve alerjik polenlerden oluşur. Genel kaynakları ısınma yöntemleri, enerji sektörü, trafik ve sanayileşmedir. (WHO, 2019) Partikül maddelerin sağlık üzerindeki etkileri, maruz kalma düzeyine (genellikle μg/m³ olarak ifade edilir) ve maruz kalma süresine bağlıdır. Partikül maddelerin sağlık üzerindeki etkilerine karşı bireysel duyarlılık değişebilir.

Karakaş (2015) doğumdan sonra iki yaşına kadar çocukların evlerindeki iç ortam kirleticilerini, bu kirleticiler ile alt solunum yolu enfeksiyonları ve alerjik semptomlar arasındaki ilişki incelemiştir. Araştırmada iç ve dış ortam havasında biyoaerosoller (bakteri ve mantar), uçucu organik bileşikler (UOB), partikül madde (PM10, PM2.5 ve PM1) ve poli aromatik hidrokarbonlar (PAH) gibi kirleticilerin 0-2 yaş grubundaki bebekler üzerinde olumsuz etkileri olduğu ortaya konmuştur.

Kaynama sıcaklığı 50 ile 260 °C arasında değişen organik bileşikler “Uçucu Organik Bileşikler (UOB)” sınıfına girer. Bu bileşikler arasında alifatik, aromatik, oksijen içeren ve halojenli hidrokarbonlar bulunur. İç mekanlarda UOB (Uçucu Organik Bileşikler) kaynakları genellikle boya, vernik, yapıştırıcı ve döşeme malzemeleri gibi yapı malzemeleri olurken, ofislerde ise fotokopi makineleri ve çeşitli ofis ekipmanları önemli yayılım kaynakları arasında yer alır (Alyüz ve Veli, 2006).

Troposferik ozon (veya yeryüzü seviyesindeki ozon) kısa ömürlü bir hava kirleticidir. Doğrudan bir emisyon kaynağı yoktur ancak uçucu organik bileşiklerin ve azot oksitlerin güneş ışığıyla etkileşimleri sonucu oluşur (WHO, Ekim 2024; Climate & Clean Air Coalition [CCAC], t.y.). Sadece ozon hava kirliliğine uzun süreler maruz kalmak, solunum hastalıkları nedeniyle her yıl 1 milyon erken ölüme sebep olmakla birlikte bronşiti ve amfizemi kötüleştirebilir, astım krizlerini tetikleyebilir ve akciğer dokusuna kalıcı zarar verebilir (CCAC, t.y.).

Karbondioksit (CO2); renksiz, kokusuz ve yanıcı olmayan bir gazdır ve havada doğal olarak bulunur. Metabolik olaylar sonucu üretilir. Ayrıca fosil yakıtların yakılması ve volkanik patlamalar gibi doğal kaynaklardan da açığa çıkar. Uzun süreler düşük seviyelerde CO2’ye maruz kalmak baş ağrısı ve uyku hali gibi semptomlara neden olabilir. Daha yüksek seviyelerde ise hızlı solunum, bilinç bulanıklığı, artan kalp debisi, yükselmiş kan basıncı ve artmış aritmi riski görülebilir (U.S. Department of Agriculture, Food Safety and Inspection Service [FSIS], 2020).

Azot oksitler (NOx), genellikle azot dioksit (NO2) ve azot monoksit (NO) bileşiklerini içeren reaktif gazlardır. Bu gazlar, fosil yakıtların yanması, endüstriyel süreçler ve motorlu taşıt emisyonları gibi insan kaynaklı faaliyetler sonucunda atmosfere salınır. Özellikle NO2, solunum yolu hastalıklarını tetikleyebilir ve akciğer fonksiyonlarını olumsuz etkileyebilir. Uzun süreli maruziyet, astım ve kronik bronşit gibi hastalıkların kötüleşmesine neden olabilirken, kısa vadede göz, burun ve boğazda tahrişe yol açabilir. Ayrıca, azot oksitler atmosferde ince partiküllerin (PM) ve ozonun oluşumuna katkıda bulunarak hava kirliliğini artırır ve genel halk sağlığını tehdit eder (WHO, 2021).

Hava kirliliğini önlemeye yönelik tedbirlerin büyük çoğunluğu yetkili kurumlar tarafından uygulanabilir niteliktedir (IQAir, 2022; WHO, 2019). Bireysel olarak alınabilecek önlemler ise hava kirliliğine maruz kalma süresini en aza indirmek, imkanlar ölçüsünde hava filtreleri ve hava temizleme sistemlerinden faydalanmak, kirliliğin olduğu ortamlarda KN95, N95 veya FFP2 tipi maskeler kullanmak ve dışarısı uygun olduğunda pencereleri açarak iç ortamların havalandırılmasını sağlamakla sınırlıdır. Kişisel olarak tedbir alabilmek için de kirlilik ölçümleri gereklidir (Karakaş, 2015; Aghlara, 2017; IQAir, 2022). Hava kalitesi verileri Çevre ve Şehircilik Bakanlığı (ÇŞB) “Ulusal Hava Kalitesi İzleme Ağı Web Sitesi”nden (https://sim.csb.gov.tr/Services/AirQuality) görülebilmektedir. Buradaki veriler geniş bir bölgeyi kapsamaktadır, bulunulan nokta için sadece fikir verebilir.

Literatür taramasında bu proje kapsamında daha önce yapılmış benzer veya yakın çalışmalara bakıldığında:

- (Alsshamsi, 2017 vd., aktaran Idrees vd., 2018) Bu çalışmada gerçek zamanlı hava kirliliğini gösteren IoT sistemi yapılmıştır. Yazarlar birden fazla gaz sensörü kullanmışlar, ancak belirli standart ölçüm prosedürünü takip etmemişlerdir.
- (Bellavista, 2017 vd., aktaran Idrees vd., 2018) Bu çalışmada, MQ serisinden düşük maliyetli sensörler kullanarak çevresel parametreleri izledikleri IoT konseptine dayalı bir izleme sistemi tasarlanmıştır ancak düşük maliyetli sensörler durumunda zorunlu olan veri doğrulaması veya sensör kalibrasyon prosedürü yoktur.
- (Lee, 2014 vd., aktaran Idrees vd., 2018) Bu çalışmada, MQTT protokolü aracılığıyla mevcut bir Wi-Fi ağında çalışmaktadır. Amaç iç mekan hava kalitesini izlemektir ve odak noktası PM kontrolü olan tek bir kirleticilerdir.
- (Caya, 2017 vd., aktaran Idrees vd., 2018) Bu çalışmada, yalnızca PM'yi tespit etmeyi ve veri iletimi için düşük maliyetli bir toz sensörü ve Raspberry Pi kullanarak e-posta yoluyla kullanıcıyı bilgilendirmeyi amaçlamaktadır.
- (Yang vd. 2017, aktaran Idrees vd., 2018) Bu çalışmada, 3B AQI haritasını ölçmek için bir sistem üzerinde durulmuştur. Araştırmacılar, 3B veri toplama için bir dört pervaneli helikopter prototipi yapmış ve sonuçları resmi verilerle karşılaştırmıştır. Bu tasarım maliyet açısından verimli değildir ve sistem uygulaması oldukça karmaşıktır.
- (Min vd. 2014, aktaran Idrees vd., 2018) Bu çalışmada, hava kirliliği izleme için LTE ağ iletişimi ve IoT konsepti kullanılmıştır, düşük maliyetli sensörlerin sınırlamalarını dikkate almaz ve sonuçlarını Ulusal Ortam Hava Kalitesi İzleme Bilgi Sistemi tarafından sağlanan resmi verilerle karşılaştırır.
- (Simic vd. 2016, aktaran Idrees vd., 2018) Bu çalışmada, düşük maliyetli bir çözüm elde etmek için bir mobil hava kalitesi izleme sistemi yapılmıştır. Sensör taşıyıcısı olarak bir kamu otobüsü çatısı kullanılmıştır. Mobil algılama durumunda, sensörlerin düzgün çalışması için birçok hususun ele alınması gerekir, çünkü sensörler statik formda iyi çalışır. Sistemin maliyeti düşük olsa da sistem tasarım parametrelerinin eksikliği nedeniyle veriler çok güvenilir değildir.
- (Boubrima vd. 2016, aktaran Idrees vd., 2018) Bu çalışmada, kirlilik izleme sistemlerinde sensör ağı kurulumu için kapsamlı bir çalışma yürütülmüştür. Sensör düğümü yerleştirme stratejilerini ve sorunlarını analiz etmişlerdir. Bu çalışma simülasyonlar aracılığıyla değerlendirilmiştir.

Yukarıda tartışılan mevcut sistemlerin çoğu yalnızca bir veya iki ana kirleticiye vurgu yapmıştır. Sistemler daha fazla kirletici ölçtüyse, veri işleme yetenekleri belirsizdir. Düşük maliyetli sensörler kullanılmasına rağmen, bir kalibrasyon mekanizmasından yoksun oldukları tespit edilmiştir. Ayrıca, bu sistemler için güç yönetimi stratejilerinin olmadığı görülmüştür.

3 Yöntem

Proje kapsamında ölçümleri sağlayan kitler (bk. Madde 3.1) ve bu kitlerle etkileşimde olup ölçümlere göre tepki veren priz modülü (bk. Madde 3.2) yapılmıştır.

  3.1 Kitler

Proje kapsamında iki tür kit yapılmıştır: Medikal Kit ve Kişisel Kit. Medikal Kit doktorlar tarafından hastaların kullanması için verilen bir cihaz olarak tasarlanmıştır. Kişisel Kit ise kişilerin kendi kullanımları göz önüne alınarak tasarlanmıştır. Kitler arasındaki ana farklar Kişisel Kit’in 4,3 inçlik dokunmatik bir LCD ekrana sahip olması ve Bluetooth ile kullanıcının telefonuna bağlanabilmesidir. Kullanılan elemanlar Tablo 1’de verilmiştir.

Sistemin elektrik devrelerinin tasarımında açık kaynak ve kod olan KiCad programı kullanılmıştır. Bu program https://www.kicad.org bağlantısından ücretsiz olarak indirilebilir.

    3.1.1 Medikal Kit

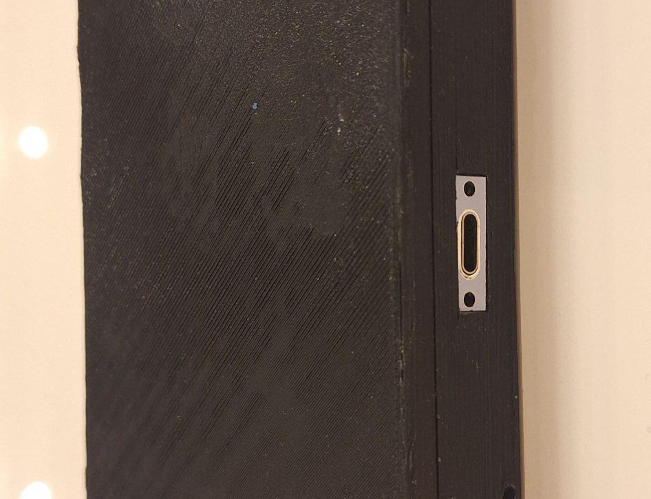
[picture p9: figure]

Görsel 2: Medikal Kit

Görsel 2’te görünen Medikal Kit, 83,5x166x25,5 mm boyutlarında (standart bir cep telefonu boyutu), 211g ağırlığında olarak hastaların kolaylıkla yanlarında taşıyabilecekleri şekilde tasarlanmıştır. Medikal Kit, doktorlar tarafından hastalarına tanı koymalarını, hastalarının yaşadıkları yerlerin hava kirliliklerini öğrenmelerini ve bunlara göre tedavi yöntemi seçmelerini kolaylaştırmak amacıyla kullanılması hedeflenmiştir. Bu cihazın kullanım amacı doktorların hastaların 7/24 tansiyonunu görmek için verilen tansiyon cihazlarıyla benzerdir. Bu kit; sıcaklık, nem, AQI [Air Quality Index (T.: Hava Kalitesi İndeksi)], tUOB (toplam Uçucu Organik Bileşenler), CO2, CO, NH3, NOx, PM1, PM2.5, PM10 ve O3’nu ölçmekte ve bu ölçümleri ölçüm zamanı ve konumuyla birlikte mikro SD karta kaydetmektedir.

Medikal Kit üzerinde iki adet düğme bulunmaktadır. Bu düğmeler biri kayıt düğmesi diğeri ise ekran kontrol düğmesidir. Hasta kendini kötü hissettiğinde kayıt düğmesine basarak anlık ölçüm değerlerinin kaydeder. Bu değerler “önemli” olarak etiketlenir. Bu sayede doktor hangi değerlerde hastanın kötü hissetmiş olduğunu anlayabilir. Ekran kontrol düğmesi ile hasta, sistem üzerindeki ekranda farklı sayfaları görebilir. Elektrik devre şeması Ek-1’de verilmiştir.

    3.1.2 Kişisel Kit

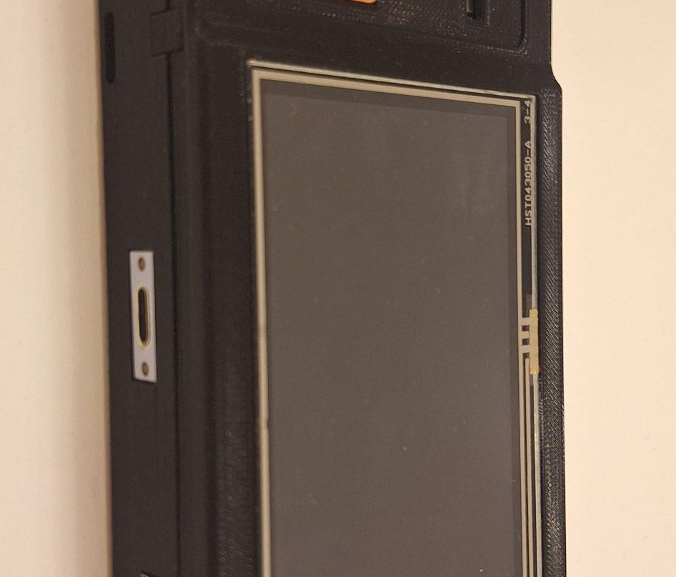
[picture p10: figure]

Görsel 3: Kişisel Kit

Görsel 3’te görünen Kişisel Kit, 83,5x166x28 mm boyutlarında (standart bir cep telefonu boyutu), 297g ağırlığında olarak kişilerin kolaylıkla yanlarında taşıyabilecekleri şekilde tasarlanmıştır. Kişisel Kit, hava kirliliğinden etkilenen kişilerin yanlarında taşıyarak bulundukları ortamın anlık ölçümlerini dokunmatik ekranda görmesi ve kişilerin önlem almalarını kolaylaştırmak amacıyla kullanılması hedeflenmiştir. Bu kit; sıcaklık, nem, AQI, tUOB, CO2, CO, NH3, NOx, PM1, PM2.5, PM10 ve O3’nu ölçmekte ve bunları ölçüm zamanı ve konumuyla birlikte hem mikro SD karta hem de Bluetooth aracılığıyla kullanıcının telefonuna bağlanarak bir veritabanına kaydeder. Bu veritabanına ayrı bir web sitesinden (Görsel 4) ulaşılabilir. Bunun yanında ölçülen değerler kullanıcı tarafından belirlenen (Görsel 5) alarm değerlerini aştığında Priz Modülü’ne (bk. Madde 3.2) Wi-Fi üzerinden bilgi göndererek bu modüle takılan cihazların çalışmasını sağlar. Elektrik devre şeması Ek-1’de verilmiştir.

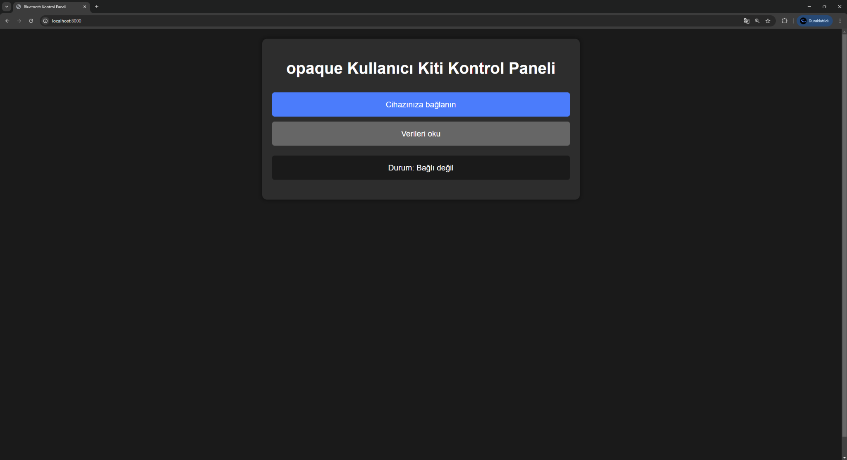
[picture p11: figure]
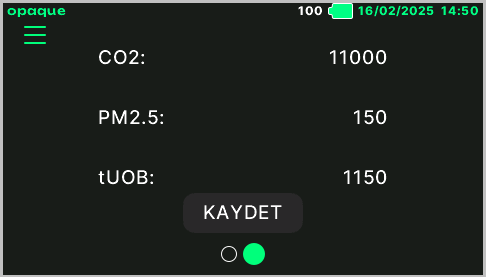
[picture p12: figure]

Görsel 4 ve 5: Veritabanına ulaşılabilen web sitesi; Alarm değer belirleme ekranı

    3.1.3 Kitlerde Kullanılan Modüller

Tablo 1

Kitlerde kullanılan modüller

Kitlerde Kullanılan Modül | Kişisel Kit | Medikal Kit | Açıklama | Görsel

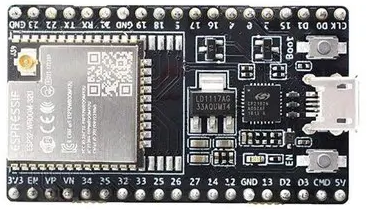
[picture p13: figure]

ESP32-DevKitC-V4 | X | X | Mikrodenetleyici Kartı ESP32-DevKitC-V4; 4MB’lık flash hafızaya, 40MHz’lik kristale, 2 çekirdeğe, Bluetooth ve Wi-Fi entegrasyonuna ve harici anten konnektörüne sahiptir. UART, SPI ve I²C haberleşme protokollerini destekleyen kart 3,3V’ta çalışmaktadır. | Görsel 6: ESP32-DevKitC-V4

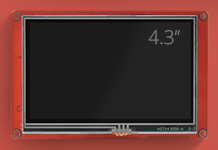
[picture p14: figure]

NX4827P043-011R | X | | Ekran NX4827P043; 4,3 inç, dokunmatik (resistif) bir ekrandır. UART ile haberleşmekte ve 5V’ta çalışmaktadır. | Görsel 8: NX4827P043

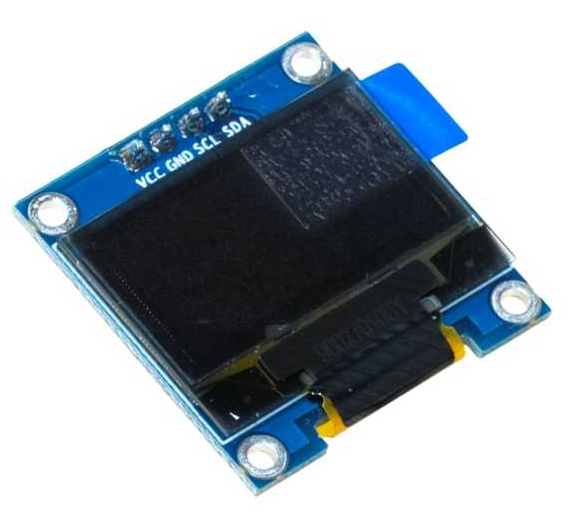
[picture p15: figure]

SSD1306 | | X | Ekran SSD1306; 128x64 piksel, siyah-beyaz bir OLED ekrandır. I²C ile haberleşmekte ve 3,3V’ta çalışmaktadır. | Görsel 7: SSD1306

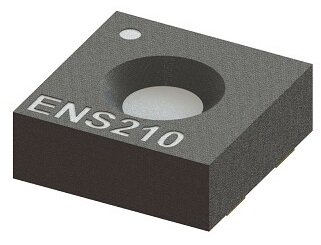
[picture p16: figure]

ENS210 | X | X | Sıcaklık ve Nem Ölçümü Sensör 3,3V’ta çalışmaktadır. Sıcaklık ölçüm hassasiyeti ±0.15°C, bağıl nem ölçüm hassasiyeti ise ±%2’dir. Sıcaklık ölçüm aralığı -40 ile 100°C arası iken bağıl nem ölçüm aralığı %0 ile %100’dür. | Görsel 9: ENS210

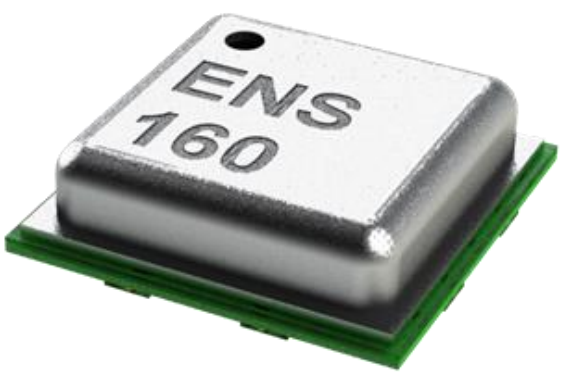
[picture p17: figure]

ENS160 | X | X | AQI, tUOB, CO2 Ölçümü Sensör 3,3V’ta çalışmaktadır. tUOB ölçüm aralığı 0-65.000 ppb arası iken CO2 ölçüm aralığı 400-65.000 ppm’dir. AQI ölçüm aralığı 1-5’tir (UBA, 2007 standardına göre). | Görsel 10: ENS160

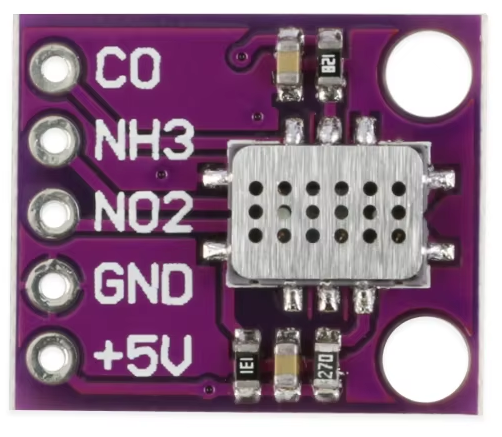
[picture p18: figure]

MICS-6814 | X | X | CO, NH3, NOx Ölçümü Sensör 5V’ta çalışmaktadır. CO ölçüm aralığı 1-1.000ppm, NH3 ölçüm aralığı 1-500ppm ve NOx ölçüm aralığı 0,05-10ppm’dir. | Görsel 11: MICS-6814

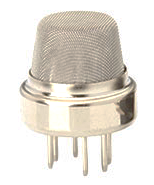
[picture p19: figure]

MQ131 | X | X | O3 Ölçümü Sensör 5V’ta çalışmaktadır. O3 ölçüm aralığı 10-1.000ppm’dir. | Görsel 12: MQ131

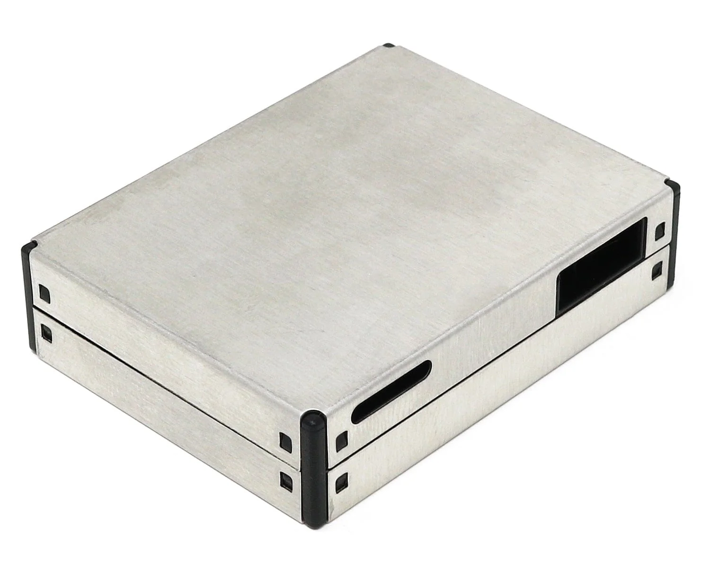
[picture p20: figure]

PMS7003 | X | X | PM1, PM2.5, PM10 Ölçümü Sensör 5V’ta çalışmaktadır. Ölçüm aralığı 0-1.000μg/m³tür ve %98 doğrulukla sonuç vermektedir. | Görsel 13: PMS7003

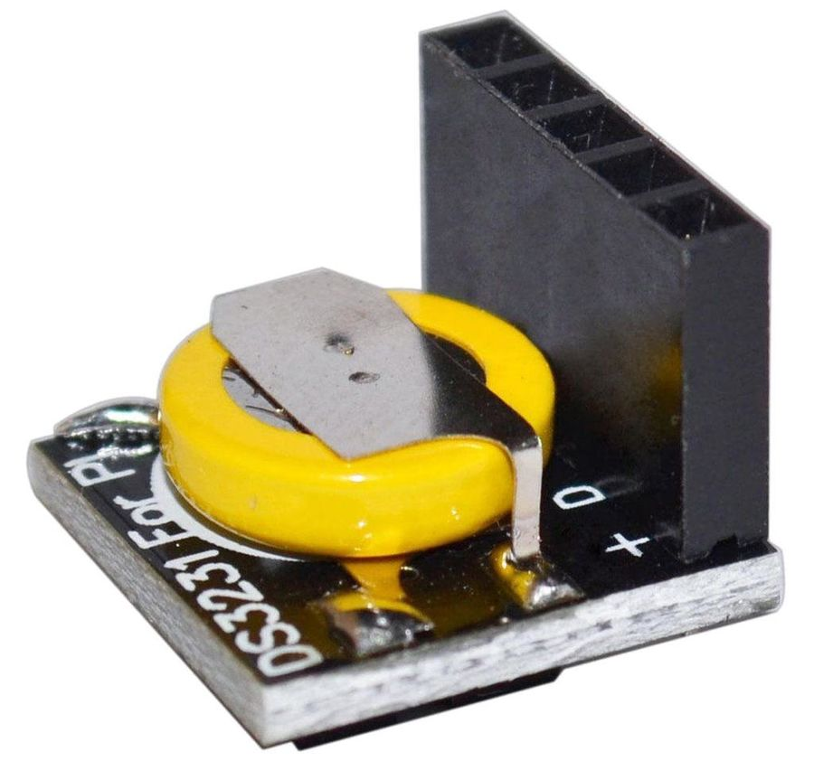
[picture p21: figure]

DS3231 for Pi | | X | Gerçek Zamanlı Saat DS3231 for Pi modülü, I²C ile haberleşmekte ve 3,3V’ta çalışmaktadır. Hassasiyeti ±1dakika/yıl’dır. | Görsel 14: DS3231 for Pi

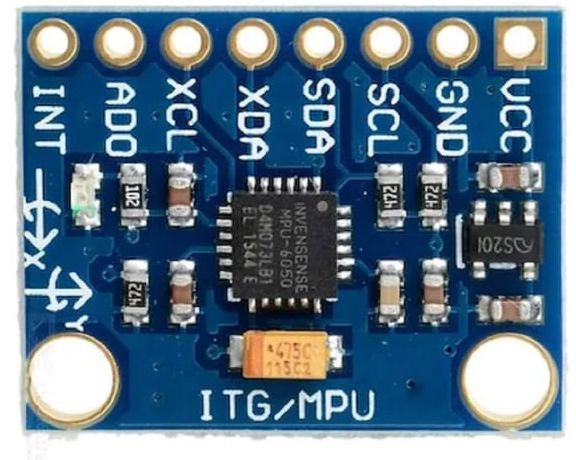
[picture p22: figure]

GY-521 | | X | İvmeölçer GY-521 modülü, MPU6050 entegresini kullanan bir ivmeölçerdir. Modül, I²C ile haberleşmekte ve 3,3V’ta çalışmaktadır. | Görsel 15: GY-521

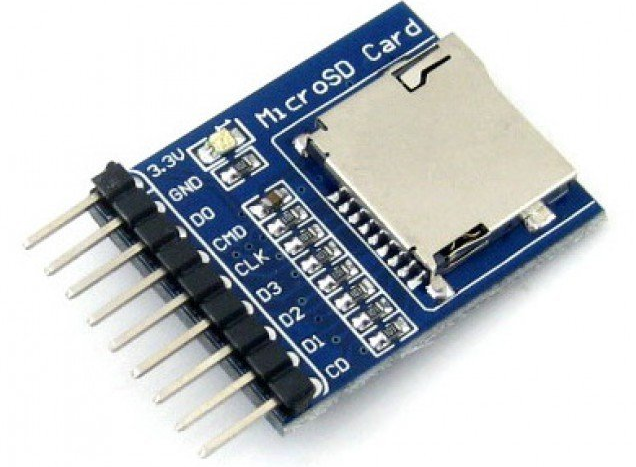
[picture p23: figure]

Mikro SD Kart Adaptör Modülü | X | X | Mikro SD Kart Adaptörü Modül, SPI ile haberleşmekte ve 3,3V’ta çalışmaktadır. | Görsel 16: Mikro SD Kart Adaptör Modülü

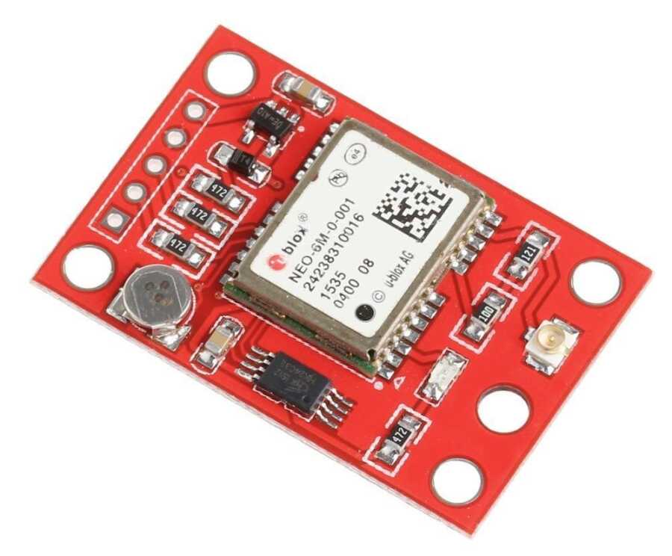
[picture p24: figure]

NEO-6M | X | X | GPS Modülü Modülün konum hassasiyeti ±2,5m, hız hassasiyeti ±0,1m/s’dir. Modül, UART ile haberleşmekte ve 5V’ta çalışmaktadır. | Görsel 17: NEO-6M

      3.1.3.1 Diğer Elektrik/Elektronik Elemanlar

Her iki kitte kullanılan diğer elektrik / elektronik elemanlar:

- 3,7V 3800mA lityum tablet pili
- SX1308 2A DC-DC Step-Up aşamalı voltaj yükseltici
- MP2307 Mini360 DC-DC Step-Down voltaj regülatörü
- Type C USB dişi giriş
- 6x6 mm buton
- 5x2 1.27 mm IDC male soket
- Diyot, on/off switch, direnç, led, montaj kablosu
    3.1.4 3B Baskılar

İki kitin de dış kutusu 3B baskı ile PETG filament ile basılmıştır. Bu sayede sıcak ortamlarda bozulmadan durabilmektedir. 3B çizimler Onshape programı ile çizilmiştir. Sonrasında 3B çizimler GitHub’a .step ve .stl dosya formatlarında yüklenmiştir.

    3.1.5 Baskılı Devre Kartı

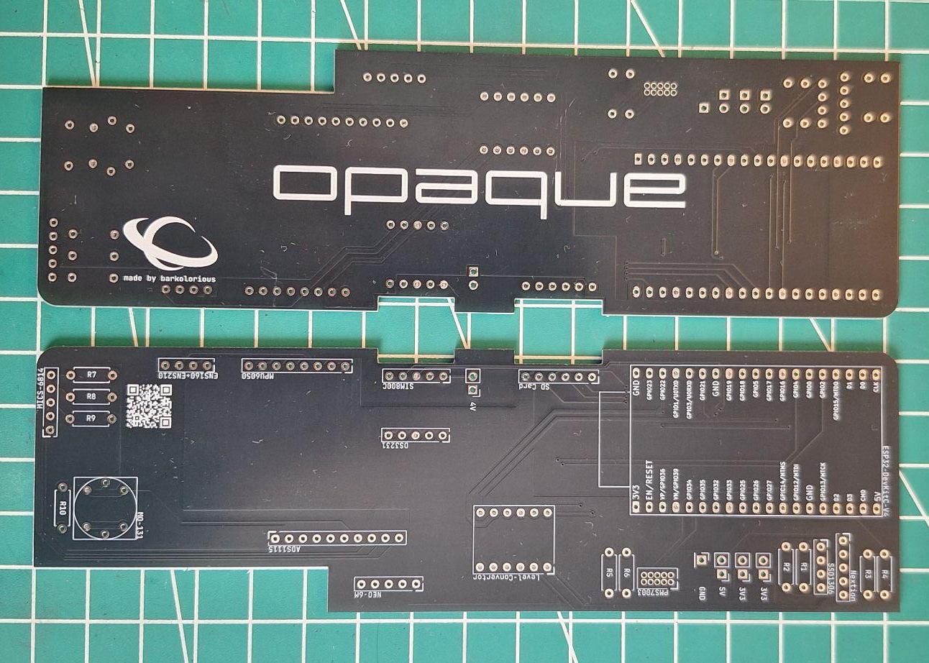
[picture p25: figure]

Görsel 18: Baskılı Devre Kartı

Malzemeler seçtikten, 3B tasarım bitirdikten ve şematik çizdikten sonra baskılı devre kartı [İng.: Printed Circuit Board (PCB)] tasarımı yapılmıştır. Bu tasarım KiCad uygulamasında yapılmıştır. Ardından bir firmaya üretim için sipariş verilmiştir.

    3.1.6 Yazılım

ESP32-DevKitC-V4 modülünün kodlamasında Arduino IDE kullanılmıştır. Arduino IDE Arduino’nun resmi sitesi, https://www.arduino.cc/en/software adresinden ücretsiz olarak indirilebilir. Bazı modüller için açık kaynak ve kod olarak hazır kütüphaneler kullanılmıştır.

  3.2 Priz Modülü (PrMd)


Görsel 19: Priz Modülü (PrMd)

Priz Modülü (Görsel 19), Kişisel Kit ile çalışmak üzere tasarlanan ve üzerinden iki adet priz bulunan bir modüldür. İç mekânlarda kullanılmak üzere tasarlanan PrMd, bünyesinde bulunan Wi-Fi modülü aracılığıyla Kişisel Kit’ten uyarı sinyali aldığında üzerindeki prizi aktif hale getirmektedir. Bir elektrik prizine takıldığında, kendi üzerindeki prizler yalnızca uyarı sinyali alındığında devreye girer; aksi takdirde devre dışı kalır. Bu sayede PrMd'ye bağlanan hava temizleme üniteleri, uyarı ışıkları, oda nemlendiricileri vb. sistemler yalnızca gerekli olduğunda çalışarak enerji tasarrufu sağlar. Wi-Fi tabanlı iletişim kullanıldığı için, iki modül arasındaki haberleşme mesafesi iç mekân koşulları için yeterlidir.

PrMd prizlerinde 220 VAC gerilim kullanılacak olması nedeniyle, modülü tasarlandıktan sonra, güvenlik gözetilerek bir uzmana kontrol ettirilmiş ve onun önerileri doğrultusunda düzenlenmiştir. Kullanılan elektrik / elektronik elemanlar bu raporun 3.2.1 maddesinin alt başlıklarında açıklanmıştır. Elektrik devre şeması Ek-1’de verilmiştir.

    3.2.1 PrMd’de Kullanılan Modüller
      3.2.1.1 Mikrodenetleyici Kartı


Görsel 20: ESP8266-01

Kişisel Kit ile haberleşmeyi sağlamak için ESP8266-01 seçilmiştir. Bu modül, PrMd’nin kontrolünü de sağlar. ESP8266-01; 1MB’lık flash hafızaya, Bluetooth ve Wi-Fi entegrasyonuna ve dahili antene sahiptir. UART ve I²C haberleşme protokollerini destekleyen kart 3,3V’ta çalışmaktadır.

      3.2.1.2 Diğer Elektrik / Elektronik Elemanlar

PrMd modülünde kullanılan diğer elektrik / elektronik elemanlar:

- 20 VAC / 7.5 VAC 1 W trafo,
- 4A köprü diyot (elektronik sistem beslemesi için),
- ASM1117 3.3 VDC voltaj regülatörü (ESP8266-01 beslemesi),
- MT3608 2A DC-DC booster (voltaj yükselticisi / 24 VDC röle beslemesi),
- 10 A sigorta (220 VAC bölgesi için),
- 220 VAC, 30 mA 2x20 A monofaze kaçak akım rölesi ve ikili priz,
- 24 VDC, 4 kontak 16A sanayi tipi röle ve röle soketi
- Delikli plaket, klemens, montaj rayı, diyot ve montaj kablosu.
  3.3 Testler

İki kit de monte edildikten sonra gerekli sensörler temiz havada 72 saat ısıtılmıştır. Sonrasında sensörlerin hassasiyetini ölçmek için testler yapılmıştır.

Burada iki tür test kullanılmıştır.

- Akredite ölçüm ekipmanları ile farklı ortamlarda karşılaştırmalı kontrol ölçümleri,
- Hava geçirmez kapta içeriği bilinen gazların ölçümleri.

Testlerde Kişisel Kit kullanılmıştır.

    3.3.1 Karşılaştırmalı Kontrol Ölçümleri


Görsel 21: Ölçümlerin alındığı ağır sanayi kuruluşuna ait kontrol ekipmanı

Karşılaştırmalı ölçümleri için mevzuat gereği ellerinde akredite ölçüm ekipmanları olan bir ağır sanayi kuruluşundan destek alınmış, kuruluşun sahasında altı farklı noktada kontrol ölçümleri yapılmıştır.

Kullanılan kontrol ölçüm cihazları (Görsel 21) aşağıdaki gibidir:

- PM10 kontrol ölçümü için kullanılan cihaz modeli: Turnkey DM11928
- CO2 kontrol ölçümü için kullanılan cihaz modeli: Riken Keiki GX-3R Pro
- CO kontrol ölçümü için kullanılan cihaz modeli: Riken Keiki GX-3R Pro
- tUOB kontrol ölçümü için kullanılan cihaz modeli: PCE-VOC 1

Ölçümler bağımsız iki örneklem T-testi, mertebe yakınlıklarını görmek için Pearson Korelasyon analizi ile istatiksel olarak değerlendirilmiştir.
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

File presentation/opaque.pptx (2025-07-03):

## Açık-kaynaklı Taşınabilir Hava Kalitesi Ölçüm Kitleri


Hazırlayan: Barkın Özsoy
Danışman: Dr. Gülseren Coşkun

## GİRİŞ

“Hava kirliliği, çağımızın en büyük çevresel sağlık riski olup, her yıl 8,1 milyondan fazla insanın hayatını kaybetmesine neden olan sessiz bir katildir.” (United Nations Environment Program [UNEP], t.y.).

Hava kirliliğini insan sağlığını veya çevre dengesini bozacak şekilde havanın bileşiminin değişmesi olarak tanımlanabilir.
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

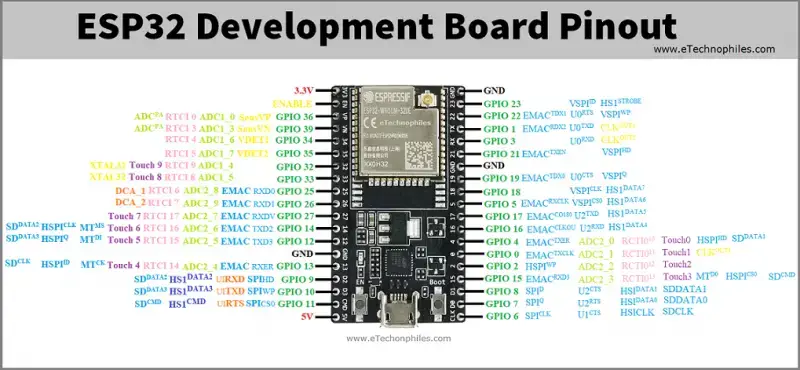
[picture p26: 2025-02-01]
Notes/assets/Pasted image 20241116133241.png

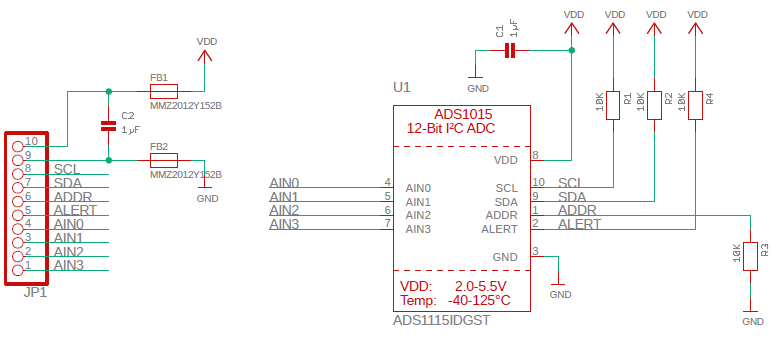
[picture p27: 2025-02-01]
Notes/assets/Pasted image 20241123235145.png

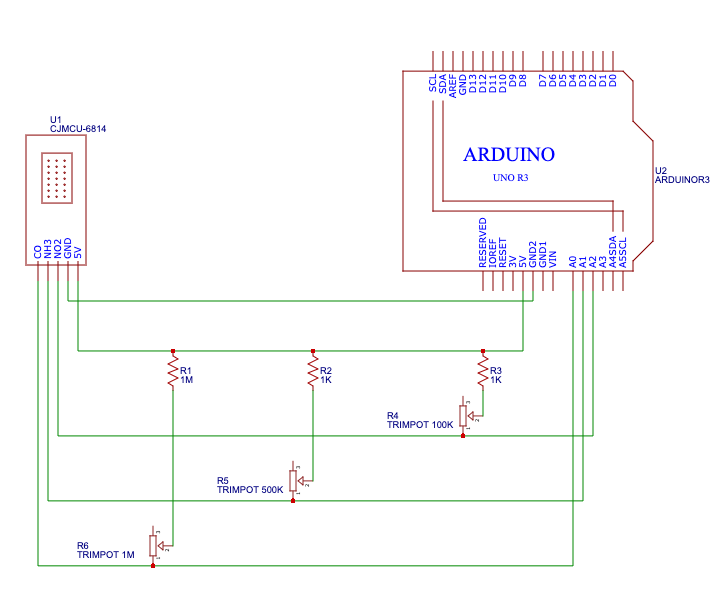
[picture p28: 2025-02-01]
Notes/assets/Pasted image 20250128162927.png

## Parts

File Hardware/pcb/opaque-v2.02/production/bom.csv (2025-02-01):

Designator | Footprint | Quantity | Value | LCSC Part #
 | 4caf8f08-ef57-4cd8-b036-9392498239b6 | 1
J1 | PinHeader_1x01_P2.54mm_Vertical | 1 | Conn_01x01_Socket
J2, J3, J4, J5 | PinHeader_1x02_P2.54mm_Vertical | 4 | Conn_01x02_Pin
R1, R2 | R_Axial_DIN0207_L6.3mm_D2.5mm_P7.62mm_Horizontal | 2 | 3.3kΩ
R10 | R_Axial_DIN0207_L6.3mm_D2.5mm_P7.62mm_Horizontal | 1 | 1MΩ
R3 | R_Axial_DIN0207_L6.3mm_D2.5mm_P7.62mm_Horizontal | 1 | 5.6kΩ
R4, R5, R6 | R_Axial_DIN0207_L6.3mm_D2.5mm_P7.62mm_Horizontal | 3 | 10kΩ
R7, R8, R9 | R_Axial_DIN0207_L6.3mm_D2.5mm_P7.62mm_Horizontal | 3 | 47kΩ
U1 | ESP32-DevKitC | 1 | ESP32-DevKitC
U10 | ADS1115 | 1 | ~
U11 | NX4827P043 | 1 | ~
U12 | PMS7003 | 1 | ~
U13 | MICS-6814 | 1 | ~
U14 | MQ-131 | 1 | ~
U2 | DS3231 | 1 | ~
U3 | MPU6050 | 1 | ~
U4 | ENS160+ENS210 | 1 | ~
U5 | SIM800C | 1 | ~
U6 | SD_Card | 1 | ~
U7 | NEO-6M | 1 | ~
U8 | SSD1306 | 1 | ~
U9 | Level-Convertor | 1 | ~

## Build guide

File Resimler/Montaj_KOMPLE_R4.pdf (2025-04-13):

setPageBoxes("Crop", 0, 0, [0,2000,2000,0]);

# Unknown

TITLE | C:/Documents and Settings/dozsoy/Desktop/Montaj_KOMPLE_R4.stp PART NO | Montaj_KOMPLE_R4 REVISION | NONE DESIGNER | odozs ENGINEER NOTES

THE INFORMATION AND/OR MATERIAL IN THIS DOCUMENT IS THE PROPERTY OF AND RESTRICTED INFORMATION AND/OR MATERIAL OF THE AUTHOR. THIS INFORMATION MAY NOT BE USED, REPRODUCED, PUBLISHED OR DISCLOSED TO OTHERS WITHOUT WRITTEN AUTHORIZATION. IT IS TO BE USED ONLY FOR MANUFACTURING ITEMS SPECIFIED WITHIN THE DOCUMENT.

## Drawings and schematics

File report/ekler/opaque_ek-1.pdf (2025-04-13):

Ek-1:
Elektrik Devre Şeması

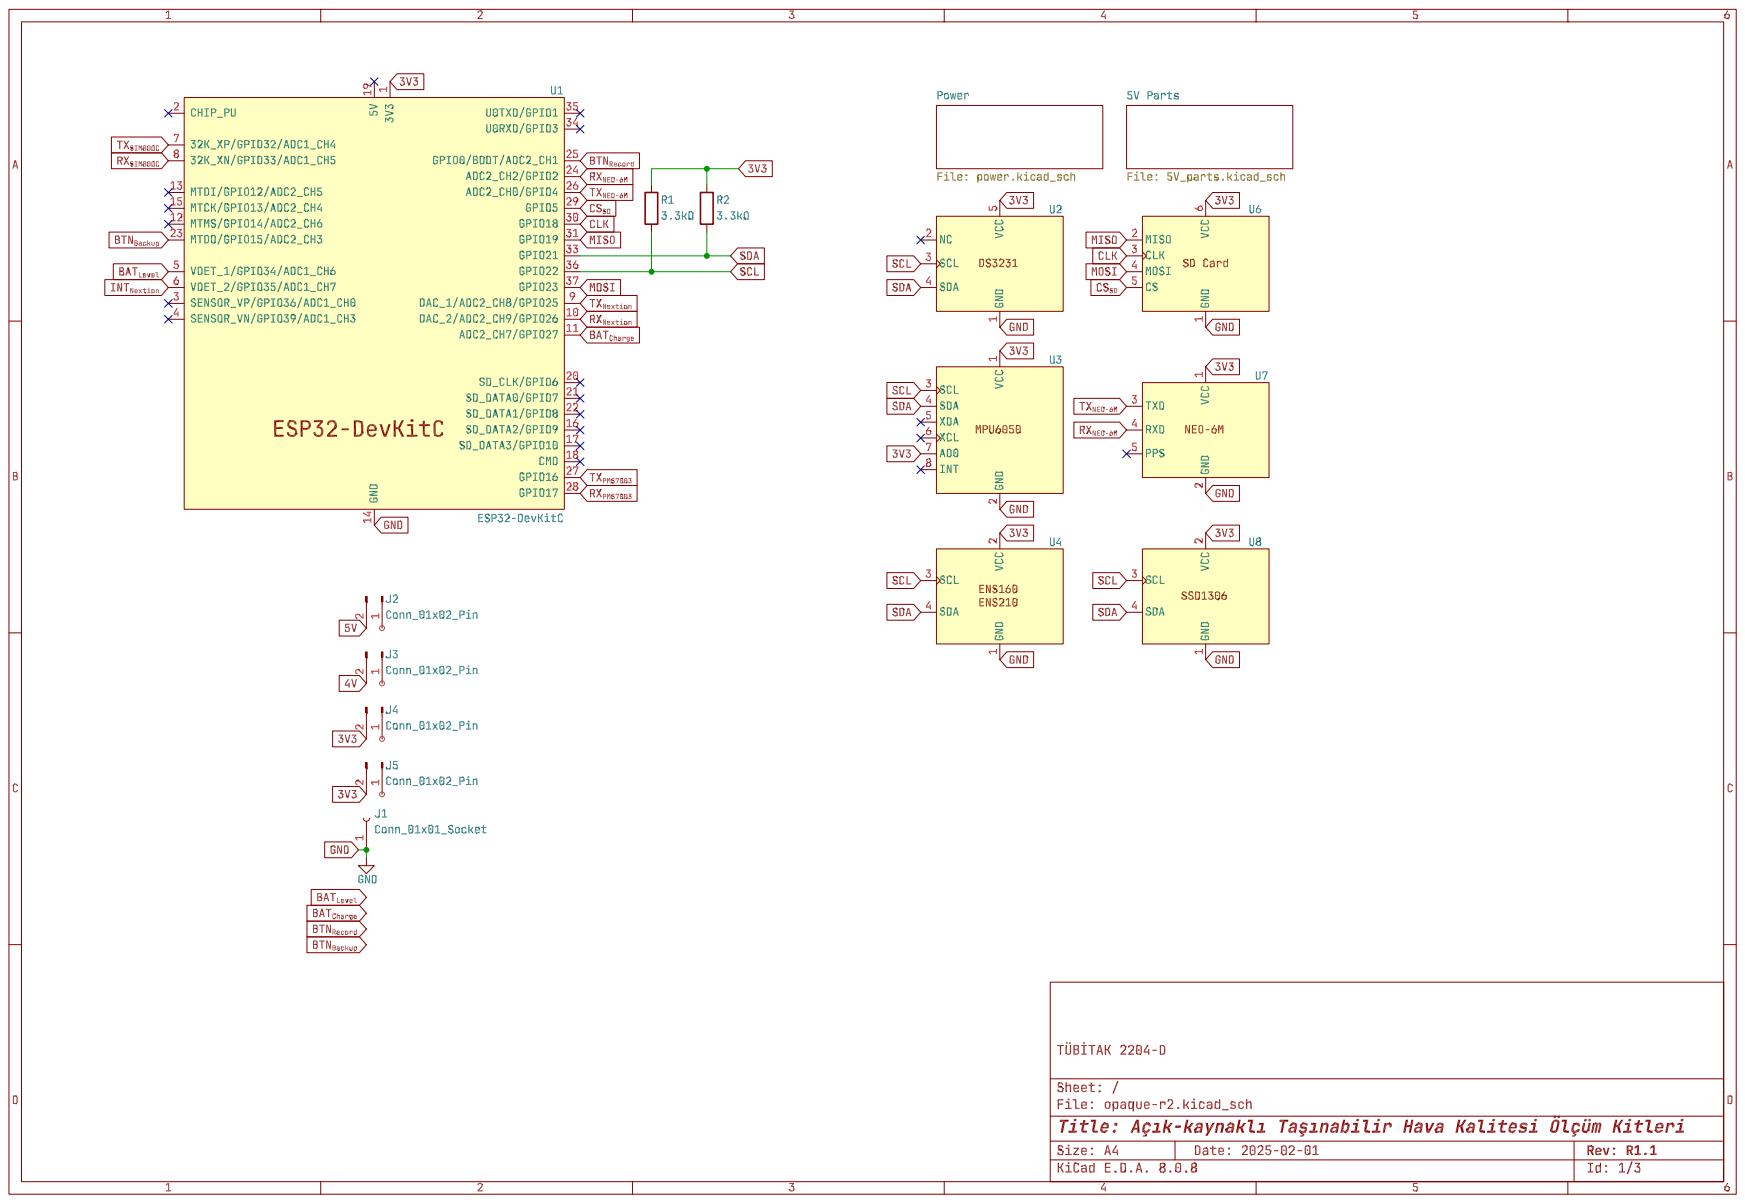
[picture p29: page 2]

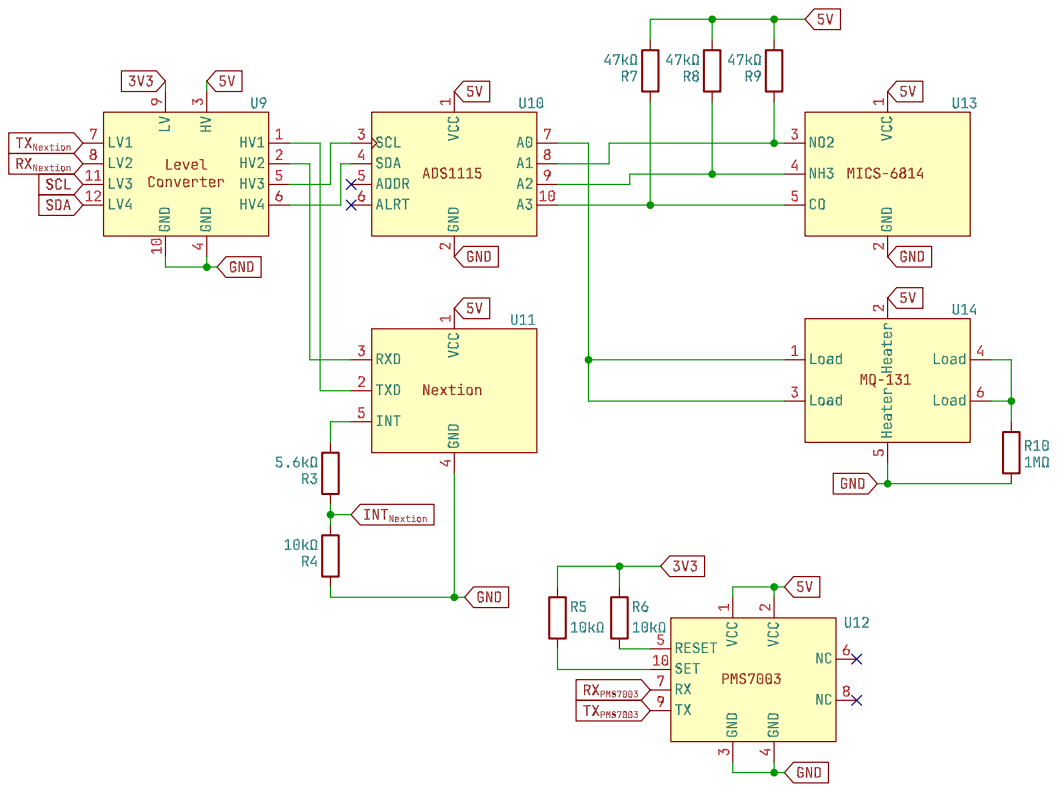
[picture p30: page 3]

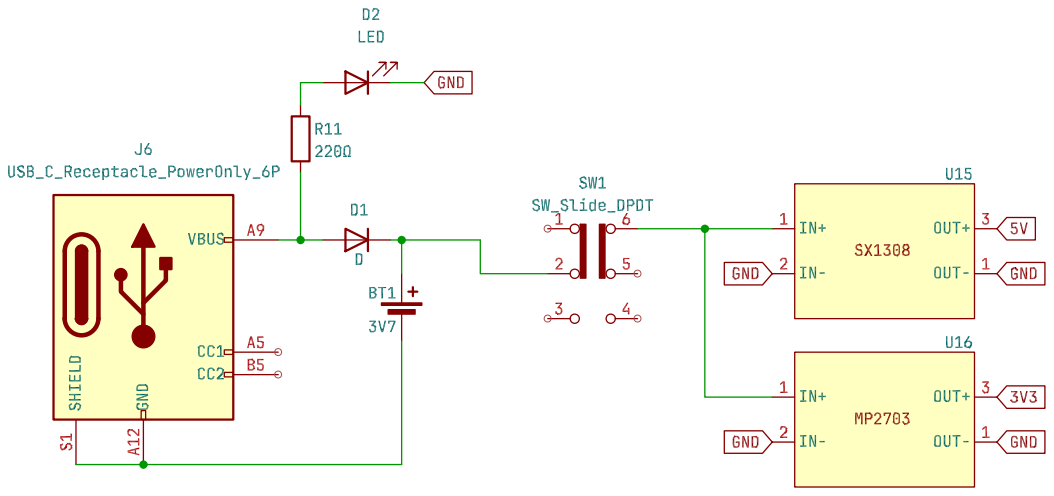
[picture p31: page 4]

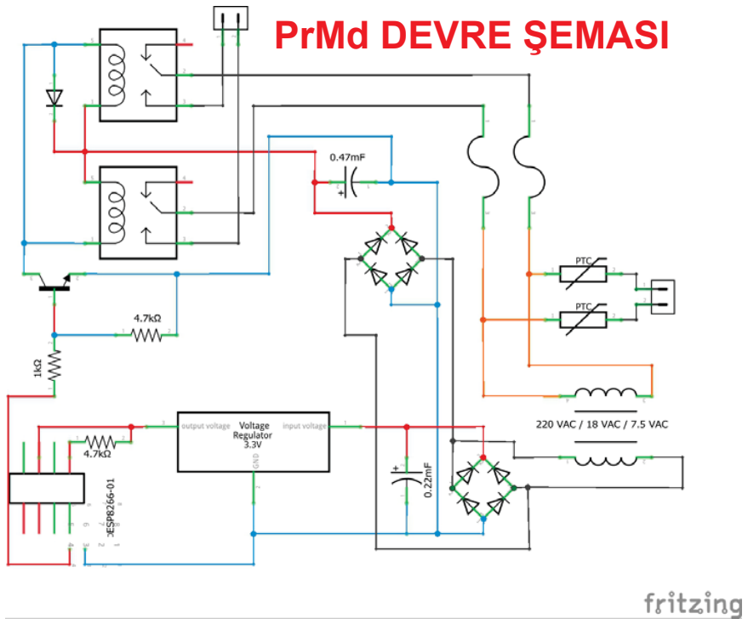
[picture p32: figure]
PrMd DEVRE ùEMASI




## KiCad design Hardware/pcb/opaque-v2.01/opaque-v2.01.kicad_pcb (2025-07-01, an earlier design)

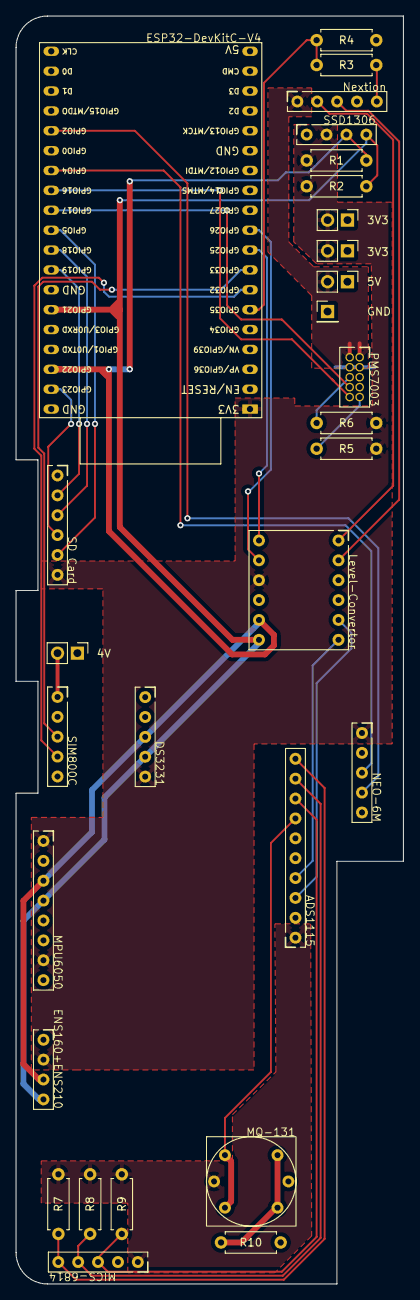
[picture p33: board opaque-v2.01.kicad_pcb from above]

Board: 2 copper layers, 49.5 x 162.0 mm, 29 parts (0 on the bottom side), 31 nets.

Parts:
J1: Conn_01x01_Socket; PinHeader_1x01_P2.54mm_Vertical
J2, J3, J4, J5: Conn_01x02_Pin; PinHeader_1x02_P2.54mm_Vertical
R1, R2: 3.3kΩ; R_Axial_DIN0207_L6.3mm_D2.5mm_P7.62mm_Horizontal
R3: 5.6kΩ; R_Axial_DIN0207_L6.3mm_D2.5mm_P7.62mm_Horizontal
R4, R5, R6: 10kΩ; R_Axial_DIN0207_L6.3mm_D2.5mm_P7.62mm_Horizontal
R7, R8, R9: 47kΩ; R_Axial_DIN0207_L6.3mm_D2.5mm_P7.62mm_Horizontal
R10: 1MΩ; R_Axial_DIN0207_L6.3mm_D2.5mm_P7.62mm_Horizontal
U1: ESP32-DevKitC
U2: DS3231
U3: MPU6050
U4: ENS160+ENS210
U5: SIM800C
U6: SD_Card
U7: NEO-6M
U8: SSD1306
U9: Level-Convertor
U10: ADS1115
U11: NX4827P043
U12: PMS7003
U13: MICS-6814
U14: MQ-131

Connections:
3V3: J4.2, J5.2, R1.1, R2.1, R5.1, R6.1, U1.1 (3V3), U2.5 (VCC), U3.1 (VCC), U3.7 (AD0), U4.2 (VCC), U6.6 (VCC), U7.1 (VCC), U8.2 (VCC), U9.9 (LV)
4V: J3.2, U5.1 (VCC)
5V: J2.2, R7.2, R8.2, R9.2, U9.3 (HV), U10.1 (VCC), U11.1 (VCC), U12.1 (VCC), U12.2 (VCC), U13.1 (VCC), U14.2 (Heater)
CLK: U1.30 (GPIO18), U6.3 (CLK)
GND: J1.1, R4.1, R10.2, U1.14 (GND), U1.32 (GND), U1.38 (GND), U2.1 (GND), U3.2 (GND), U4.1 (GND), U5.5 (GND), U6.1 (GND), U7.2 (GND), U8.1 (GND), U9.4 (GND), U9.10 (GND), U10.2 (GND), U11.4 (GND), U12.3 (GND), U12.4 (GND), U13.2 (GND), U14.5 (Heater)
INT_{Nextion}: R3.1, R4.2, U1.6 (VDET_2/GPIO35/ADC1_CH7)
MISO: U1.31 (GPIO19), U6.2 (MISO)
MOSI: U1.37 (GPIO23), U6.4 (MOSI)
unnamed: R10.1, U14.4 (Load), U14.6 (Load)
unnamed: U10.7 (A0), U14.1 (Load), U14.3 (Load)
unnamed: R9.1, U10.8 (A1), U13.3 (NO2)
unnamed: R8.1, U10.9 (A2), U13.4 (NH3)
unnamed: R7.1, U10.10 (A3), U13.5 (CO)
unnamed: U9.5 (HV3), U10.3 (SCL)
unnamed: U9.6 (HV4), U10.4 (SDA)
unnamed: R3.2, U11.5 (INT)
unnamed: U9.2 (HV2), U11.3 (RXD)
unnamed: U9.1 (HV1), U11.2 (TXD)
unnamed: R6.2, U12.5 (RESET)
unnamed: R5.2, U12.10 (SET)
RX_{NEO-6M}: U1.24 (ADC2_CH2/GPIO2), U7.4 (RXD)
RX_{Nextion}: U1.10 (DAC_2/ADC2_CH9/GPIO26), U9.8 (LV2)
RX_{PMS7003}: U1.28 (GPIO17), U12.7 (RX)
RX_{SIM800C}: U1.8 (32K_XN/GPIO33/ADC1_CH5), U5.3 (RXD)
SCL: R1.2, U1.36 (GPIO22), U2.3 (SCL), U3.3 (SCL), U4.3 (SCL), U8.3 (SCL), U9.11 (LV3)
SDA: R2.2, U1.33 (GPIO21), U2.4 (SDA), U3.4 (SDA), U4.4 (SDA), U8.4 (SDA), U9.12 (LV4)
TX_{NEO-6M}: U1.26 (ADC2_CH0/GPIO4), U7.3 (TXD)
TX_{Nextion}: U1.9 (DAC_1/ADC2_CH8/GPIO25), U9.7 (LV1)
TX_{PMS7003}: U1.27 (GPIO16), U12.9 (TX)
TX_{SIM800C}: U1.7 (32K_XP/GPIO32/ADC1_CH4), U5.4 (TXD)
~CS_{SD}: U1.29 (GPIO5), U6.5 (~CS)

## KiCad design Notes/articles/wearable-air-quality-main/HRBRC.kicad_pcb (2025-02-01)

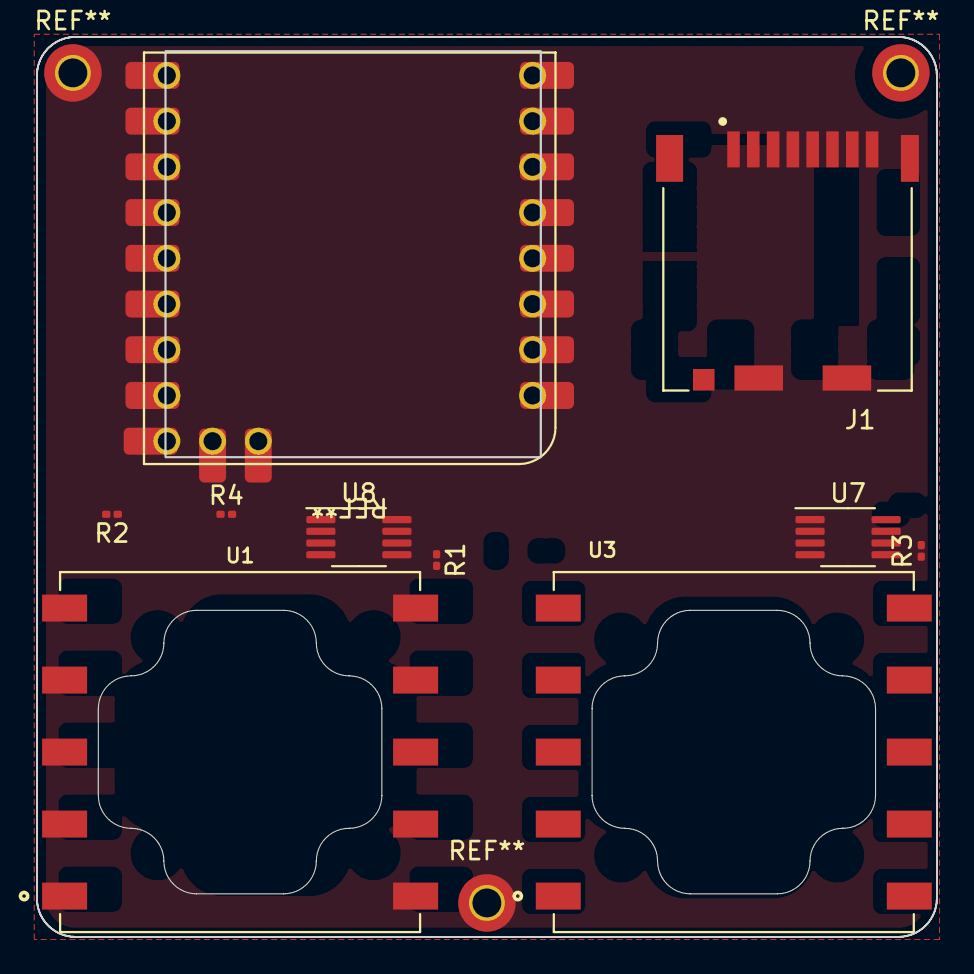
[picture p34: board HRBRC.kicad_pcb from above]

Board: 2 copper layers, 50.0 x 50.0 mm, 10 parts (1 on the bottom side), 11 nets, no tracks yet.

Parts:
J1: Micro_SD_Card_Det_Hirose_DM3CS; HRS_DM3CS-SF
R1, R3: 49.9; R_0201_0603Metric
R2, R4: 499K; R_0201_0603Metric
U1, U3: 110-407; XDCR_110-407
U6: SCD41; SCD4x
U7, U8: MCP6L02x-xMS; MSOP-8_3x3mm_P0.65mm

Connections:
+3.3VA: U7.8 (V+), U8.8 (V+)
+3V3: J1.4 (VDD), U6.7 (VDD), U6.19 (VDDH)
GND: U6.6 (GND), U6.20 (GND), U6.21 (GND), U7.4 (V-), U8.4 (V-)
unnamed: U8.1, U8.5 (+)
unnamed: J1.6 (VSS), J1.9 (DET_B)
unnamed: R1.1, U1.6 (COUNTER)
unnamed: R3.1, U3.6 (COUNTER)
unnamed: U7.6 (-), U7.7
unnamed: U1.1 (WORKING), U1.10 (WORKING)
unnamed: U3.1 (WORKING), U3.10 (WORKING)
VGAS: U8.6 (-), U8.7

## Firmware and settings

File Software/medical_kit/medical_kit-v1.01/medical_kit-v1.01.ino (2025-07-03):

/*
 ██████████████████   ██████████████████  ███████████████████   ██████████████████  ██                ██  ██████████████████ 
██                ██ ██                ██                   ██ ██                ██ ██                ██ ██                ██
██                ██ ██                ██  ███████████████████ ██                ██ ██                ██ ███████████████████ 
██                ██ ██                ██ ██                ██ ██                ██ ██                ██ ██
 ██████████████████  ███████████████████   ██████████████████   ███████████████████  ██████████████████   ██████████████████ 
                     ██                                                          ██
                     ██                                                          ██            
*/
//////////////////////////////////// LIBS ////////////////////////////////////
#include <Wire.h>
#include <FS.h>
#include <SPI.h>
#include <SoftwareSerial.h>
/////////////// SSD1306 ////////////////
#include <Adafruit_GFX.h>
#include <Adafruit_SSD1306.h>
#include "Org_01.h"
//////////////// DS3231 ////////////////
#include <RTClib.h>
//////////////// ENS160 ////////////////
#include <SparkFun_ENS160.h>
//////////////// ENS210 ////////////////
#include <ens210.h>
/////////////// MPU6050 ////////////////
#include <MPU6050_light.h>
/////////////// SD Card ////////////////
#include <SD.h>
/////////////// ADS1115 ////////////////
#include <Adafruit_ADS1X15.h>
/////////////// PMS7003 ////////////////
#include <PMserial.h>
//////////////// NEO6M /////////////////
#include <TinyGPS++.h>
///////////////////////////////////// LIBS /////////////////////////////////////

#define SSD1306_LOGO_O_HEIGHT    10
#define SSD1306_LOGO_O_WIDTH     20
#define MPU6050_DETECT_THRESHOLD 1.2
#define MQ131_ADS1115_PIN        0
#define MQ131_R_LOAD             22000.0
#define MICS6814_OX_ADS1115_PIN  1
#define MICS6814_NH3_ADS1115_PIN 2
#define MICS6814_CO_ADS1115_PIN  3

///////////////////////////////////// PINS /////////////////////////////////////
/*        EMPTY         */ /* GPIO0 */
/*        EMPTY         */ /* GPIO1 (UART0 TX) -- CP2102 RX */
#define UART2_TX        2  /* GPIO2 (UART2 TX) -- NEO6M RX (WiFi) */
/*        EMPTY         */ /* GPIO3 (UART0 RX) -- CP2102 TX */
#define UART2_RX        4  /* GPIO4 (UART2 RX) -- NEO6M TX (WiFi) */
#define VSPI_CS         5  /* GPIO5 (VSPI CS)  -- SD Card CS */
/*      DO NOT USE      */ /* GPIO6 */
/*      DO NOT USE      */ /* GPIO7 */
/*      DO NOT USE      */ /* GPIO8 */
/*      DO NOT USE      */ /* GPIO9 */
/*      DO NOT USE      */ /* GPIO10 */
/*      DO NOT USE      */ /* GPIO11 */
/*        EMPTY         */ /* GPIO12 (WiFi) */
/*        EMPTY         */ /* GPIO13 (WiFi) */
/*        EMPTY         */ /* GPIO14 (WiFi) */
/*        EMPTY         */ /* GPIO15 (WiFi) */
#define UART1_RX        16 /* GPIO16 (UART1 RX) -- PMS7003 TX */
#define UART1_TX        17 /* GPIO17 (UART1 TX) -- PMS7003 RX */
#define VSPI_CLK        18 /* GPIO18 (VSPI CLK) */
#define VSPI_MISO       19 /* GPIO19 (VSPI MISO) */
#define I2C_SDA         21 /* GPIO21 (I2C SDA) */
#define I2C_SCL         22 /* GPIO22 (I2C SCL) */
#define VSPI_MOSI       23 /* GPIO23 (VSPI MOSI) */
/*        EMPTY         */ /* GPIO25 (WiFi) */
/*        EMPTY         */ /* GPIO26 (WiFi) */
/*        EMPTY         */ /* GPIO27 (WiFi) */
#define BTN_RECORD_PIN  32 /* GPIO32 -- Record Button */
#define BTN_BACKUP_PIN  33 /* GPIO33 -- Backup Button */
#define BAT_LEVEL_PIN   34 /* GPIO34 (Analog) -- Battery Charge Level */
/*        EMPTY         */ /* GPIO25 */
#define BAT_CHARGE_PIN  36 /* GPIO36 (Analog) -- Battery Is Charging?*/
/*        EMPTY         */ /* GPIO39 */
///////////////////////////////////// PINS /////////////////////////////////////

/////////////////////////////////// OBJECTS ////////////////////////////////////
////// SSD1306 /////////
Adafruit_SSD1306 ssd1306(128, 64, &Wire, -1);
//////////////// DS3231 ////////////////
RTC_DS3231 ds3231;
//////////////// ENS160 ////////////////
SparkFun_ENS160 ens160; 
//////////////// ENS210 ////////////////
ENS210 ens210;
/////////////// MPU6050 ////////////////
MPU6050 mpu6050(Wire);
/////////////// ADS1115 ////////////////
Adafruit_ADS1115 ads1115;
/////////////// PMS7003 ////////////////
SerialPM pms7003(PMS7003, UART1_RX, UART1_TX);
//////////////// NEO6M /////////////////
TinyGPSPlus neo6m;
HardwareSerial neo6m_serial(2);
/////////////////////////////////// OBJECTS ////////////////////////////////////

////////////////////////////////// VARIABLES ///////////////////////////////////
/////////////// GENERAL ////////////////
uint32_t measurement_timer = 0;
float measurements[12] = {0, 0, 0, 0, 0, 0, 0, 0, 0, 0, 0, 0};
/////////////// SSD1306 ////////////////
const unsigned char logo_opaque [] PROGMEM = {
	0x7f, 0xff, 0xe3, 0xff, 0xff, 0x1f, 0xff, 0xf8, 0xff, 0xff, 0xcc, 0x00, 0x03, 0x3f, 0xff, 0xf0, 
	0xff, 0xff, 0xf7, 0xff, 0xff, 0xbf, 0xff, 0xfd, 0xff, 0xff, 0xec, 0x00, 0x03, 0x7f, 0xff, 0xf8, 
	0xc0, 0x00, 0x36, 0x00, 0x01, 0x80, 0x00, 0x0d, 0x80, 0x00, 0x6c, 0x00, 0x03, 0x60, 0x00, 0x18, 
	0xc0, 0x00, 0x36, 0x00, 0x01, 0x80, 0x00, 0x0d, 0x80, 0x00, 0x6c, 0x00, 0x03, 0x60, 0x00, 0x18, 
	0xc0, 0x00, 0x36, 0x00, 0x01, 0x9f, 0xff, 0xfd, 0x80, 0x00, 0x6c, 0x00, 0x03, 0x7f, 0xff, 0xf8, 
	0xc0, 0x00, 0x36, 0x00, 0x01, 0xbf, 0xff, 0xfd, 0x80, 0x00, 0x6c, 0x00, 0x03, 0x7f, 0xff, 0xf0, 
	0xc0, 0x00, 0x36, 0x00, 0x01, 0xb0, 0x00, 0x0d, 0x80, 0x00, 0x6c, 0x00, 0x03, 0x60, 0x00, 0x00, 
	0xc0, 0x00, 0x36, 0x00, 0x01, 0xb0, 0x00, 0x0d, 0x80, 0x00, 0x6c, 0x00, 0x03, 0x60, 0x00, 0x00, 
	0xff, 0xff, 0xf7, 0xff, 0xff, 0xbf, 0xff, 0xfd, 0xff, 0xff, 0xef, 0xff, 0xff, 0x7f, 0xff, 0xf8, 
	0x7f, 0xff, 0xe7, 0xff, 0xff, 0x1f, 0xff, 0xf8, 0xff, 0xff, 0xe7, 0xff, 0xfe, 0x3f, 0xff, 0xf0, 
	0x00, 0x00, 0x06, 0x00, 0x00, 0x00, 0x00, 0x00, 0x00, 0x00, 0x60, 0x00, 0x00, 0x00, 0x00, 0x00, 
	0x00, 0x00, 0x06, 0x00, 0x00, 0x00, 0x00, 0x00, 0x00, 0x00, 0x60, 0x00, 0x00, 0x00, 0x00, 0x00, 
	0x00, 0x00, 0x06, 0x00, 0x00, 0x00, 0x00, 0x00, 0x00, 0x00, 0x60, 0x00, 0x00, 0x00, 0x00, 0x00, 
	0x00, 0x00, 0x06, 0x00, 0x00, 0x00, 0x00, 0x00, 0x00, 0x00, 0x60, 0x00, 0x00, 0x00, 0x00, 0x00, 
	0x00, 0x00, 0x06, 0x00, 0x00, 0x00, 0x00, 0x00, 0x00, 0x00, 0x60, 0x00, 0x00, 0x00, 0x00, 0x00
};
const unsigned char logo_opaque_frame0 [] PROGMEM = {
	0x7f, 0xff, 0xe3, 0xff, 0xff, 0x00, 0x0f, 0xf8, 0xff, 0xff, 0xc7, 0xc0, 0x3e, 0x3f, 0xff, 0xf0, 
	0xff, 0xff, 0xf7, 0xff, 0xff, 0x80, 0x1f, 0xfd, 0xff, 0xff, 0xef, 0xc0, 0x3f, 0x7f, 0xff, 0xf8, 
	0xc0, 0x00, 0x36, 0x00, 0x01, 0x9f, 0xff, 0xfd, 0x80, 0x00, 0x6c, 0x00, 0x03, 0x60, 0x00, 0x18, 
	0xc0, 0x00, 0x36, 0x00, 0x01, 0xbf, 0xff, 0xfd, 0x80, 0x00, 0x6c, 0x00, 0x03, 0x60, 0x00, 0x18, 
	0xc0, 0x00, 0x36, 0x00, 0x01, 0xb0, 0x00, 0x0d, 0x80, 0x00, 0x6c, 0x00, 0x03, 0x60, 0x00, 0x18, 
	0xc0, 0x00, 0x36, 0x00, 0x01, 0xb0, 0x00, 0x0d, 0x80, 0x00, 0x6c, 0x00, 0x03, 0x60, 0x00, 0x18, 
	0xc0, 0x00, 0x36, 0x00, 0x01, 0xb0, 0x00, 0x0d, 0x80, 0x00, 0x6c, 0x00, 0x03, 0x7f, 0xff, 0xf8, 
	0xc0, 0x00, 0x36, 0x00, 0x01, 0xb0, 0x00, 0x0d, 0x80, 0x00, 0x6c, 0x00, 0x03, 0x7f, 0xff, 0xf0, 
	0xff, 0xff, 0xf7, 0xff, 0xff, 0xbf, 0xff, 0xfd, 0xff, 0xff, 0xef, 0xff, 0xff, 0x7f, 0xf0, 0x00, 
	0x7f, 0xff, 0xe7, 0xff, 0xff, 0x1f, 0xff, 0xf8, 0xff, 0xff, 0xe7, 0xff, 0xfe, 0x3f, 0xe0, 0x00, 
	0x00, 0x00, 0x06, 0x00, 0x00, 0x00, 0x00, 0x00, 0x00, 0x00, 0x60, 0x00, 0x00, 0x00, 0x00, 0x00, 
	0x00, 0x00, 0x06, 0x00, 0x00, 0x00, 0x00, 0x00, 0x00, 0x00, 0x60, 0x00, 0x00, 0x00, 0x00, 0x00, 
	0x00, 0x00, 0x00, 0x00, 0x00, 0x00, 0x00, 0x00, 0x00, 0x00, 0x00, 0x00, 0x00, 0x00, 0x00, 0x00, 
	0x00, 0x00, 0x00, 0x00, 0x00, 0x00, 0x00, 0x00, 0x00, 0x00, 0x00, 0x00, 0x00, 0x00, 0x00, 0x00, 
	0x00, 0x00, 0x00, 0x00, 0x00, 0x00, 0x00, 0x00, 0x00, 0x00, 0x00, 0x00, 0x00, 0x00, 0x00, 0x00
};
const unsigned char logo_o [] PROGMEM = {
	0x7f, 0xff, 0xe0, 0xff, 0xff, 0xf0, 0xc0, 0x00, 0x30, 0xc0, 0x00, 0x30, 0xc0, 0x00, 0x30, 0xc0, 
	0x00, 0x30, 0xc0, 0x00, 0x30, 0xc0, 0x00, 0x30, 0xff, 0xff, 0xf0, 0x7f, 0xff, 0xe0
};
const unsigned char tags [] PROGMEM = {
  0xfb, 0xef, 0x80, 0x00, 0x00, 0x00, 0x03, 0xef, 0xbe, 0x20, 0x00, 0x82, 0x20, 0xa0, 0x00, 0x00, 
  0x00, 0x02, 0x2a, 0xa2, 0x28, 0x00, 0x82, 0x2f, 0x80, 0x00, 0x00, 0x00, 0x03, 0xea, 0xa2, 0x20,
  0x00, 0x82, 0x28, 0x00, 0x00, 0x00, 0x00, 0x02, 0x0a, 0xa2, 0x20, 0x00, 0xfb, 0xef, 0xa0, 0x00, 
  0x00, 0x00, 0x02, 0x0a, 0xbe, 0xa8, 0x00, 0x00, 0x00, 0x00, 0x00, 0x00, 0x00, 0x00, 0x00, 0x00, 
  0x00, 0x00, 0x00, 0x00, 0x00, 0x00, 0x00, 0x00, 0x00, 0x00, 0x00, 0x00, 0x00, 0x8b, 0xef, 0x80, 
  0x00, 0x00, 0x00, 0x03, 0xef, 0xbe, 0x3e, 0x00, 0x8a, 0x28, 0x20, 0x00, 0x00, 0x00, 0x02, 0x2a, 
  0x82, 0x20, 0x80, 0x8a, 0x28, 0x00, 0x00, 0x00, 0x00, 0x03, 0xea, 0xbe, 0x3e, 0x00, 0x52, 0x28,
  0x00, 0x00, 0x00, 0x00, 0x02, 0x0a, 0xa0, 0x02, 0x00, 0x23, 0xef, 0xa0, 0x00, 0x00, 0x00, 0x02, 
  0x0a, 0xbe, 0xbe, 0x80, 0x00, 0x00, 0x00, 0x00, 0x00, 0x00, 0x00, 0x00, 0x00, 0x00, 0x00, 0x00, 
  0x00, 0x00, 0x00, 0x00, 0x00, 0x00, 0x00, 0x00, 0x00, 0x00, 0xfb, 0xef, 0x80, 0x00, 0x00, 0x00, 
  0x03, 0xef, 0xaf, 0x80, 0x00, 0x8a, 0x22, 0x20, 0x00, 0x00, 0x00, 0x02, 0x2a, 0xa8, 0xa0, 0x00, 
  0xfa, 0x22, 0x00, 0x00, 0x00, 0x00, 0x03, 0xea, 0xa8, 0x80, 0x00, 0x8a, 0x62, 0x00, 0x00, 0x00,
  0x00, 0x02, 0x0a, 0xa8, 0x80, 0x00, 0x8b, 0xef, 0xa0, 0x00, 0x00, 0x00, 0x02, 0x0a, 0xaf, 0xa0, 
  0x00, 0x00, 0x00, 0x00, 0x00, 0x00, 0x00, 0x00, 0x00, 0x00, 0x00, 0x00, 0x00, 0x00, 0x00, 0x00, 
  0x00, 0x00, 0x00, 0x00, 0x00, 0x00, 0x00, 0xf8, 0x00, 0x00, 0x00, 0x00, 0x00, 0x03, 0xe8, 0xbe,
  0x00, 0x00, 0x23, 0xdf, 0x7a, 0x00, 0x00, 0x00, 0x02, 0x28, 0x82, 0x80, 0x00, 0x23, 0xd5, 0x48, 
  0x00, 0x00, 0x00, 0x02, 0x2f, 0xbe, 0x00, 0x00, 0x22, 0x11, 0x48, 0x00, 0x00, 0x00, 0x02, 0x28,
  0x82, 0x00, 0x00, 0x23, 0xd1, 0x7a, 0x00, 0x00, 0x00, 0x02, 0x28, 0xbe, 0x80, 0x00, 0x00, 0x00, 
  0x40, 0x00, 0x00, 0x00, 0x00, 0x00, 0x00, 0x00, 0x00, 0x00, 0x00, 0x00, 0x00, 0x00, 0x00, 0x00, 
  0x00, 0x00, 0x00, 0x00, 0x88, 0x00, 0x02, 0x00, 0x00, 0x00, 0x03, 0xef, 0x80, 0x00, 0x00, 0x8a, 
  0x5f, 0x5e, 0x80, 0x00, 0x00, 0x02, 0x28, 0xa5, 0x00, 0x00, 0xfa, 0x55, 0x12, 0x00, 0x00, 0x00, 
  0x02, 0x28, 0x98, 0x00, 0x00, 0x8a, 0x51, 0x52, 0x00, 0x00, 0x00, 0x02, 0x28, 0x98, 0x00, 0x00,
  0x8b, 0xd1, 0x5e, 0x80, 0x00, 0x00, 0x02, 0x2f, 0xa5, 0x00, 0x00, 0x00, 0x00, 0x00, 0x00, 0x00, 
  0x00, 0x00, 0x00, 0x00, 0x00, 0x00, 0x00, 0x00, 0x00, 0x00, 0x00, 0x00, 0x00, 0x00, 0x00, 0x00, 
  0x00, 0xfb, 0xe0, 0x00, 0x00, 0x00, 0x00, 0x03, 0xef, 0x80, 0x00, 0x00, 0x88, 0x28, 0x00, 0x00, 
  0x00, 0x00, 0x02, 0x08, 0xa0, 0x00, 0x00, 0x8b, 0xe0, 0x00, 0x00, 0x00, 0x00, 0x02, 0x08, 0x80, 
  0x00, 0x00, 0x88, 0x20, 0x00, 0x00, 0x00, 0x00, 0x02, 0x08, 0x80, 0x00, 0x00, 0xfb, 0xe8, 0x00,
  0x00, 0x00, 0x00, 0x03, 0xef, 0xa0, 0x00, 0x00
};
//////////////// DS3231 ////////////////
String ds3231_curr_date;
String ds3231_curr_time;
const char daysOfTheWeek[7][4] = {"Paz", "Pzt", "Sal", "Car", "Per", "Cum", "Cts"};
const char monthsOfTheYear[13][4] = {"N/A", "Oca", "Sub", "Mar", "Nis", "May", "Haz", "Tem", "Agu", "Eyl", "Eki", "Kas", "Ara"};
//////////////// ENS160 ////////////////
uint16_t ens160_eCO2 = 0;
uint16_t ens160_tVOC = 0;
uint8_t  ens160_AQI  = 0;
uint8_t  ens160_flag;
//////////////// ENS210 ////////////////
float ens210_temperature = 0;
float ens210_humidity    = 0;
/////////////// MPU6050 ////////////////
uint8_t mpu6050_in_motion;
/////////////// SD Card ////////////////
uint8_t sd_card_type;
//////////////// MQ131 /////////////////
float mq131_O3 = 0;
/////////////// MICS6814 ///////////////
typedef enum mics6814_channel {CH_NH3, CH_RED, CH_OX} mics6814_channel_t;
typedef enum mics6814_gas {CO, NO2, NH3, C3H8, C4H10, CH4, H2, C2H5OH} mics6814_gas_t;
uint16_t mics6814_NH3_base_R = 12691;
uint16_t mics6814_RED_base_R = 19975;
uint16_t mics6814_OX_base_R  = 7941;
float mics6814_NH3 = 0;
float mics6814_CO  = 0;
float mics6814_NO2 = 0;
/////////////// PMS7003 ////////////////
uint16_t pms7003_PM1   = 0;
uint16_t pms7003_PM2p5 = 0;
uint16_t pms7003_PM10  = 0;
uint16_t pms7003_N0p3  = 0;
uint16_t pms7003_N0p5  = 0;
uint16_t pms7003_N1    = 0;
uint16_t pms7003_N2p5  = 0;
uint16_t pms7003_N5    = 0;
uint16_t pms7003_N10   = 0;
uint32_t pms7003_last_read = -1;
//////////////// NEO6M /////////////////
float neo6m_lat = 0;
float neo6m_lng = 0;
float neo6m_alt = 0;
/////////////// BUTTONS ////////////////
uint8_t button_record = 0;
uint8_t button_backup = 0;
////////////////////////////////// VARIABLES ///////////////////////////////////

void setup() {
  Wire.begin();
  Serial.begin(115200);

  delay(500);

  ssd1306_init();

  delay(500);

  ens210_init();
  ens160_init();
  mpu6050_init();
  //sd_card_init();
  ads1115_init();
  mq131_init();
  mics6814_init();
  pms7003_init();
  neo6m_init();
  buttons_init();

  ssd1306_opening_animation();
  Serial.println("started");
}

void loop() {
  if (millis() - measurement_timer > 5000) {
    measurement_timer = millis();
    ens160_read();
    ens210_read();
    mpu6050_read();
    mq131_read();
    mics6814_read();
    pms7003_read();
    neo6m_read();

    update_measurements();

    ssd1306_update();
  }

  buttons_read();

  uint32_t wait_timer = millis();
  while (millis() - wait_timer < 100) ;
}

void update_measurements (void) {
  measurements[0]  = 0.9 * measurements[0]  + 0.1 * ens210_temperature;
  measurements[1]  = 0.8 * measurements[1]  + 0.2 * ens210_humidity;
  measurements[2]  = 0.8 * measurements[2]  + 0.2 * ens160_eCO2;
  measurements[3]  = 0.8 * measurements[3]  + 0.2 * ens160_tVOC;
  measurements[4]  = 0.0 * measurements[4]  + 1.0 * ens160_AQI;
  measurements[5]  = 0.5 * measurements[5]  + 0.5 * mq131_O3;
  measurements[6]  = 0.8 * measurements[6]  + 0.2 * mics6814_NH3;
  measurements[7]  = 0.8 * measurements[7]  + 0.2 * mics6814_NO2;
  measurements[8]  = 0.8 * measurements[8]  + 0.2 * mics6814_CO;
  measurements[9]  = 0.8 * measurements[9]  + 0.2 * pms7003_PM1;
  measurements[10] = 0.8 * measurements[10] + 0.2 * pms7003_PM2p5;
  measurements[11] = 0.8 * measurements[11] + 0.2 * pms7003_PM10;
}

/////////////////////////////////// BUTTONS ////////////////////////////////////
void buttons_init (void) {
  pinMode(BTN_BACKUP_PIN, INPUT);
  pinMode(BTN_RECORD_PIN, INPUT);
}

void buttons_read (void) {
  button_backup = digitalRead(BTN_BACKUP_PIN);
  button_record = digitalRead(BTN_RECORD_PIN);

  if (button_record) {
    String ens160_report     = "eCO2:[" + String(ens160_eCO2) + "],tVOC:[" + String(ens160_tVOC) + "],AQI:[" + String(ens160_AQI) + "],";
    String ens210_report     = "T:[" + String(ens210_temperature) + "],Hum:[" + String(ens210_humidity) + "],";
    String mpu6050_report    = "motion:[" + String(mpu6050_in_motion) + "],";
    String mq131_report      = "O3:[" + String(mq131_O3) + "],";
    String pms7003_PM_report = "PM:[" + String(pms7003_PM1) + "," + String(pms7003_PM2p5) + "," + String(pms7003_PM10) + "],";
    String pms7003_N_report  = "N:[" + String(pms7003_N0p3) + "," + String(pms7003_N0p3) + "," + String(pms7003_N1) + "," + String(pms7003_N2p5) + "," + String(pms7003_N5) + "," + String(pms7003_N10) + "],";
    String neo6m_report      = "LAT:[" + String(neo6m_lat) + "],LNG:[" + String(neo6m_lng) + "],ALT:[" + String(neo6m_alt) + "],";
    String mics6814_report   = "NH3:[" + String(mics6814_NH3) + "],NO2:[" + String(mics6814_NO2) + "],CO:[" + String(mics6814_CO) + "],";

    String all = ds3231_curr_date + "," + ds3231_curr_time + "," + ens160_report + ens210_report + mpu6050_report + mq131_report + mics6814_report + pms7003_PM_report + pms7003_N_report + neo6m_report;
    sd_card_write_file(SD, "/test.txt", all.c_str());
  }  
}
/////////////////////////////////// BUTTONS ////////////////////////////////////

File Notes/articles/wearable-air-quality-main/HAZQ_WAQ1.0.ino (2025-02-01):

//comment out the following line to use TFT screen instead of SD card
//#define USE_SD_CARD 1


#include "Nicla_System.h"
#include <Adafruit_GPS.h>
#include "sps30.h"
#include "Arduino_BHY2.h"
#include <Wire.h>
#include "Adafruit_ILI9341.h"
#include <SPI.h>
#include <SD.h>
#ifdef USE_SD_CARD
#include "Sd2PinMap.h"
#endif

#ifndef USE_SD_CARD
//if we are not using the SD card, then we are using the TFT
#define TFT_CS 6
#define TFT_DC 5
#define TFT_MOSI 7
#define TFT_CLK 9
#define TFT_RST A0
#define TFT_MISO 8
Adafruit_ILI9341 tft = Adafruit_ILI9341(TFT_CS, TFT_DC, TFT_MOSI, TFT_CLK, TFT_RST, TFT_MISO);

#endif

Adafruit_GPS GPS(&Wire);
#define GPSECHO false

uint32_t timer = millis();

Sensor gas(SENSOR_ID_GAS);
SPS30 sps30;
sps_values val;

const int chipSelect = 0;

#ifdef USE_SD_CARD
File dataFile;

Sd2Card card;
SdVolume volume;
SdFile root;
#endif

void setup() {
  nicla::begin();
  Serial.begin(115200);
  Wire.begin();
  GPS.begin(0x10);  // The I2C address to use is 0x10
  GPS.sendCommand(PMTK_SET_NMEA_OUTPUT_RMCGGA);
  GPS.sendCommand(PMTK_SET_NMEA_UPDATE_1HZ);  // 1 Hz update rate
  GPS.sendCommand(PGCMD_ANTENNA);
  // delay(1000);
  GPS.println(PMTK_Q_RELEASE);
  BHY2.begin();
  // delay(500);
  BHY2.begin();
  gas.begin();
  sps30.begin(&Wire);

#ifndef USE_SD_CARD
  tft.begin();
  tft.fillScreen(ILI9341_BLACK);
#endif

#ifdef USE_SD_CARD
  if (!SD.begin(chipSelect)) {
    Serial.println("initialization failed. Things to check:");
    Serial.println("1. is a card inserted?");
    Serial.println("2. is your wiring correct?");
    Serial.println("3. did you change the chipSelect pin to match your shield or module?");
    Serial.println("Note: press reset button on the board and reopen this Serial Monitor after fixing your issue!");
    while (true)
      ;
  }

  // Open the data file
  dataFile = SD.open("datalog.txt", FILE_WRITE);
#endif
}

int year = 0;
int month = 0;
int day = 0;
int hour = 0;
int minute = 0;
int seconds = 0;
float latitude = 0;
float longitude = 0;
char lat = 'X';
char lon = 'X';
float CO2 = 0;
float temperature = 0;
float humidity = 0;


void TFT() {
//TFT Print//
#ifndef USE_SD_CARD
  tft.setCursor(0, 0);
  tft.setTextColor(ILI9341_WHITE, ILI9341_BLACK);
  tft.setTextSize(2);
  tft.print("Lat: ");
  tft.print(latitude / 100, 7);
  tft.print(lat);

  tft.setCursor(0, 21);
  tft.setTextColor(ILI9341_WHITE, ILI9341_BLACK);
  tft.setTextSize(2);
  tft.print("Lon: ");
  tft.print(longitude / 100, 7);
  tft.print(lon);

  tft.setCursor(0, 82);
  tft.setTextColor(ILI9341_WHITE, ILI9341_BLACK);
  tft.setTextSize(2);
  tft.print("M_PM1: ");
  tft.print(val.MassPM1);
  tft.setCursor(0, 102);
  tft.setTextColor(ILI9341_WHITE, ILI9341_BLACK);
  tft.setTextSize(2);
  tft.print("M_PM2: ");
  tft.print(val.MassPM2);
  tft.setCursor(0, 122);
  tft.setTextColor(ILI9341_WHITE, ILI9341_BLACK);
  tft.setTextSize(2);
  tft.print("M_PM4: ");
  tft.print(val.MassPM4);
  tft.setCursor(0, 142);
  tft.setTextColor(ILI9341_WHITE, ILI9341_BLACK);
  tft.setTextSize(2);
  tft.print("M_PM10: ");
  tft.print(val.MassPM10);
  tft.setCursor(0, 162);
  tft.setTextColor(ILI9341_WHITE, ILI9341_BLACK);
  tft.setTextSize(2);
  tft.print("N_PM1: ");
  tft.print(val.NumPM1);
  tft.setCursor(0, 182);
  tft.setTextColor(ILI9341_WHITE, ILI9341_BLACK);
  tft.setTextSize(2);
  tft.print("N_PM2: ");
  tft.print(val.NumPM2);
  tft.setCursor(0, 202);
  tft.setTextColor(ILI9341_WHITE, ILI9341_BLACK);
  tft.setTextSize(2);
  tft.print("N_PM4: ");
  tft.print(val.NumPM4);
  tft.setCursor(0, 222);
  tft.setTextColor(ILI9341_WHITE, ILI9341_BLACK);
  tft.setTextSize(2);
  tft.print("N_PM10: ");
  tft.print(val.NumPM10);
  tft.setCursor(0, 242);
  tft.setTextColor(ILI9341_WHITE, ILI9341_BLACK);
  tft.setTextSize(2);
  tft.print("Particle Size: ");
  tft.print(val.PartSize);

  tft.setCursor(0, 62);
  tft.setTextColor(ILI9341_WHITE, ILI9341_BLACK);
  tft.setTextSize(2);
  tft.print("VOC_Rel: ");
  tft.print(gas.value());
#endif
}

void GPSTFT() {
  //TFT Print//
#ifndef USE_SD_CARD
  tft.setCursor(0, 0);
  tft.setTextColor(ILI9341_WHITE, ILI9341_BLACK);
  tft.setTextSize(2);
  tft.print("Lat: ");
  tft.print(latitude, 3);
  tft.print(lat);

  tft.setCursor(0, 21);
  tft.setTextColor(ILI9341_WHITE, ILI9341_BLACK);
  tft.setTextSize(2);
  tft.print("Lon: ");
  tft.print(longitude, 3);
  tft.print(lon);
#endif
}

void DATATFT() {
#ifndef USE_SD_CARD
  tft.setCursor(0, 82);
  tft.setTextColor(ILI9341_WHITE, ILI9341_BLACK);
  tft.setTextSize(2);
  tft.print("M_PM1: ");
  tft.print(val.MassPM1);
  tft.setCursor(0, 102);
  tft.setTextColor(ILI9341_WHITE, ILI9341_BLACK);
  tft.setTextSize(2);
  tft.print("M_PM2: ");
  tft.print(val.MassPM2);
  tft.setCursor(0, 122);
  tft.setTextColor(ILI9341_WHITE, ILI9341_BLACK);
  tft.setTextSize(2);
  tft.print("M_PM4: ");
  tft.print(val.MassPM4);
  tft.setCursor(0, 142);
  tft.setTextColor(ILI9341_WHITE, ILI9341_BLACK);
  tft.setTextSize(2);
  tft.print("M_PM10: ");
  tft.print(val.MassPM10);
  tft.setCursor(0, 162);
  tft.setTextColor(ILI9341_WHITE, ILI9341_BLACK);
  tft.setTextSize(2);
  tft.print("N_PM1: ");
  tft.print(val.NumPM1);
  tft.setCursor(0, 182);
  tft.setTextColor(ILI9341_WHITE, ILI9341_BLACK);
  tft.setTextSize(2);
  tft.print("N_PM2: ");
  tft.print(val.NumPM2);
  tft.setCursor(0, 202);
  tft.setTextColor(ILI9341_WHITE, ILI9341_BLACK);
  tft.setTextSize(2);
  tft.print("N_PM4: ");
  tft.print(val.NumPM4);
  tft.setCursor(0, 222);
  tft.setTextColor(ILI9341_WHITE, ILI9341_BLACK);
  tft.setTextSize(2);
  tft.print("N_PM10: ");
  tft.print(val.NumPM10);
  tft.setCursor(0, 242);
  tft.setTextColor(ILI9341_WHITE, ILI9341_BLACK);
  tft.setTextSize(2);
  tft.print("Particle Size: ");
  tft.print(val.PartSize);

  tft.setCursor(0, 62);
  tft.setTextColor(ILI9341_WHITE, ILI9341_BLACK);
  tft.setTextSize(2);
  tft.print("VOC_Rel: ");
  tft.print(gas.value());
#endif
}
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

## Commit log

2025-02-01 First commit.
    [5V_parts.kicad_sch, HRBRC.kicad_pcb, HRBRC.kicad_sch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]
2025-02-01 Tidied up.
    [HRBRC.kicad_pcb, HRBRC.kicad_sch]
2025-04-13 Writtin code
    [5V_parts.kicad_sch, opaque-r2.kicad_sch, power.kicad_sch]
2025-07-01 Changed a lot could be final
    [5V_parts.kicad_sch, HRBRC.kicad_pcb, HRBRC.kicad_sch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]
2025-12-07 Changed more
    [5V_parts.kicad_sch, opaque-v2.01.kicad_sch, power.kicad_sch]
